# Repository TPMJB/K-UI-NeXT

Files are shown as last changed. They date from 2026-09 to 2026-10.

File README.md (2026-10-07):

# K-UI V1.8.5 "Dáinsleif"

An independent Dreamcast shell built directly on upstream KallistiOS, retaining
the original GD-ROM and using exFAT/FAT32 storage.

**Version 1.8.5 fixes the native reader placement that blocked Sonic Adventure
and Grandia II; the owner also reports Skies of Arcadia works.** Games adds
GDI/ISO/BIN-CUE/CDI/raw-image support, an Original/2048 picker, RAM-cached lists
and selected-title artwork. Disc Ripper adds BIN/CUE and verified CSO/ZSO/CHD
exports. SCI Wi-Fi integration and separate ESP32-C5/C6 firmware are included.
The splash identifies 1.8.5 and retains the Dáinsleif artwork.

Download the [1.8.5 release](https://github.com/TPMJB/K-UI-NeXT/releases/tag/v1.8.5),
then read the [installation guide](docs/release-v1.8.5.md) and
[release notes](docs/release-v1.8.5-notes.md). Install the runtime and complete
Games payload folder together. Existing exFAT cards, game dumps and compatible
independent K-UI boot CDs stay usable. DreamShell-based K-UI 1.0 requires the
supplied new CDI. No reformat, reripping or 2048 conversion is required.

Windows CE defaults to its background SCI reader and remains experimental;
audio/FMVs and title compatibility are limited. Time Stalkers and some native
FMV stalls remain unresolved. Compressed games require PC import before launch.
IDE/CF remains untested synchronous PIO; ATA DMA and CE on IDE/SCIF are future
work. ext4 is available only to the read-only bootstrap, not runtime apps or
Games.

The historical [1.7 notes](docs/release-v1.7-notes.md) and
[1.5.1 notes](docs/release-v1.5.1-notes.md) remain available.

The current SD runtime adds **raw-track GDI capture, saved-file verification and
controlled resume** to the independently booting hardware diagnostic. It stays
in RAM after you swap discs and uses FAT32/exFAT through the standard external
serial SD adapter. Keep the reusable CD and update `/KUI/runtime.kui`.

**Disc reading is done and verified. For the full state, read
[docs/HANDOFF-disc-reader.md](docs/HANDOFF-disc-reader.md) first.** A whole GD-ROM now rips in
about 20 minutes (it was over 100 with the original settings) and has been proven byte-exact
against the TOSEC catalogue on two discs: Sword of the Berserk (3 tracks) and MDK2 (31 tracks,
27 of them audio), on the console and again on a PC. MDK2 was also interrupted twice mid-disc and
resumed to a verified finish.
The capture engine also passes host-image tests. Earlier SD runtime launch and
disc/exFAT probes passed on a physical console. The user also
confirms B selects CD fallback and reports successful cold boots; the boot count
was not specified. Missing-file detection, checksum rejection and restoring the
good runtime have now passed by user report; see the
[hardware evidence](docs/hardware-evidence.md) for remaining coverage.
New K-UI shell code uses GPLv3; the Wi-Fi firmware/link library is MIT, and
dependencies retain their own licenses. There is no
separate contribution or commercial-relicensing agreement.

## The ten-app shell

The SD runtime opens ten apps, in this order on Home: **Games**, **Disc Ripper**,
**VMU Manager**, **File Manager** (new since 1.5.1), **Music Player**, **GD Play**,
**Memory Test**, **Network**, **Diagnostics** and **Settings**. New captures use a selectable
parent folder, defaulting to `/Games`, with title-based folders and GDI filenames.
The established raw acquisition engine remains in place; new format exports
have separate host validation and still need console acceptance.

Coming from DreamShell-based K-UI 1.0? Burn the supplied 1.8.5 CDI; that older
CD cannot boot this independent runtime. For an existing independent K-UI
installation, use its compatible bootstrap CD and merge the release package's `KUI` folder
onto the SD card as described in the [installation guide](docs/release-v1.8.5.md).
Update the runtime and Games payload together; optional original menu music
is included.
See [the current app acceptance round](docs/apps-round-five.md) and
[app boundaries and the later executable-loader plan](docs/app-architecture.md).
These new app paths still need physical-console acceptance.

- Select with D-pad or stick and open with A. B returns home while idle.
- The startup splash is capped at three seconds; B skips the shortened startup cue.
  Home Y cycles volume/off; L/R on Home and Ripper select songs. The header names the current song.
- GD Play exits through normal KOS shutdown to the stock BIOS. Music Player
  caches PCM16 WAV or Ogg Vorbis songs up to 6 MiB for background playback across apps.
  The developer `sd-update` includes an original one-minute WAV/Ogg sample.
  Music Player supports custom-song cycling, explicit cache clearing and a separate audio-CD player.
  Since 1.5 the menu songs ship as Ogg Vorbis and share one decoder, and Harbor
  Lights joins the rotation as a sixth song. All six cached use 1.06 MiB of RAM,
  against 4.46 MiB for the five 1.5 WAVs, which cards without the Oggs still play.
  The startup chime is embedded as Ogg too ([details](docs/music-round-five.md#bundled-menu-songs-as-ogg)).
- Ripper: A confirms a new dump, X resumes the newest matching job, Y verifies.
  Start opens Advanced, **Destination folder** and **Capture settings**.
  Output choices are GDI, BIN/CUE, CSO, DreamShell-LZO ZSO and CHDv4; compressed
  exports retain the verified raw capture for resume and verification.
  Advanced also offers explicitly confirmed Quick resume (sizes only), preserving
  full Resume and its saved-byte checks. During work, B requests Stop. Reports still save automatically. Idle insertion
  detection shows the disc title; moving capture/verification phases show percentage and ETA.
  Current retry attempts and the cumulative job total are labelled separately.
- System Settings: 640x480 TV timing with reversible preview, memory display,
  music enabled and volume, startup chime/app, local clock, TV safe area, menu sounds
  and restore-defaults. System Tools adds inventory, verified flash/visible BIOS backups and Restart.
  Capture hashes/readback remain inside the ripper. New file dates follow the RTC.
- VMU Manager: read saves, make verified SD backups, and preview/confirm restore
  into a free filename with readback. Managed copy/delete require confirmation and
  a verified restorable SD backup. No overwrite or format. Memory Test checks only its allocated RAM.
- Ripper Advanced CRC scans completed saved jobs and reports hash/Mode 1 sector
  errors separately. Already-read track sizes and CRCs are compared with the
  Redump/TOSEC catalogues, including GDI-only folders without a manifest. Only a
  full reference match establishes all-track agreement; unavailable/partial
  references retain the limited structural result.
  Separate Salvage jobs add durable bad-sector queues, optional zero filling and
  bounded repair passes; unresolved holes never receive a complete-dump claim.
- File Manager browses every folder and file on SD and opens games, music and
  pictures. Copy, move, rename and delete are checked and confirmed first;
  copies are read back and compared before they take their name, nothing is
  replaced, and the files K-UI needs to start are protected
  ([details](docs/files.md)). It has not yet been tried on a console.
- Network includes a temporary DHCP/address-conflict/gateway-ping test; it
  does not claim Internet reachability or change saved network settings. With a
  W5500 wired to the SCI port (a modification), Network also finds that adapter
  and runs an FTP server for the SD card: uploads take their name only once
  complete, and K-UI's start-up files are protected
  ([details](docs/ftp.md)). Earlier overlapping-transfer builds reached about
  0.8 MiB/s uploads and 0.5 MiB/s downloads in the tested W5500/SCIF setup;
  these are historical results, not new 1.8.5 measurements.
  A XIAO ESP32-C5/C6 with the separate K-UI firmware provides SCI Wi-Fi;
  Network Start opens scan/join and band selection. Storage remains on SCIF
  while networking owns SCI. Flash firmware by USB from a computer; console
  firmware updating is not exposed ([setup](docs/wifi.md)).
  Diagnostics retains disc/SD probes, log export,
  mstats and benchmarks. RAM remains visible in the ripper.
- Music keeps playing from RAM during menu actions and capture; uncached song
  changes wait until the storage worker is idle. Console continuity still needs checking.
- Repeated drive failures can retain PIO until reboot. The ripper now keeps that
  warning visible; the accepted DMA stop/lid policy is unchanged.

Defaults now select **CRC32, automatic end readback Off, DMA and 2 Hz busy redraws**:
these are the policy choices used by the accepted fast captures. Explicit
`bench.cfg` keys override saved preferences, and the log prints the effective
options. Resume keeps the existing job's hash mode. **Y Verify always rereads saved
files**. Only an independent **FULL TRACK MATCH** gives the stream CRC badge a
green result; partial matches and saved-file verification remain separate.

A title such as MDK2 produces `/Games/MDK2/MDK2.gdi`; another New uses
`/Games/MDK2 (2)/MDK2.gdi` without overwriting the first. Resume/Verify select the
greatest numbered matching-disc checkpoint in the chosen parent, with legacy
`/KUI/dumps` fallback. Existing jobs keep their format. See
[ripper controls](docs/ripper-controls.md) and [the capture format](docs/capture-format.md).

The reusable CD's built-in diagnostics remain available by holding B during
startup. Missing or invalid runtime packages fall back automatically. Keep using
the working CD; this UI update needs no new burn. See [SD bootstrap](docs/sd-bootstrap.md)
and [hardware evidence](docs/hardware-evidence.md) for the established boot checks.

## Build and test

On Ubuntu 24.04 / a compatible Linux or WSL installation:

```sh
sudo apt-get install build-essential git curl wget patch python3 bison flex \
  texinfo gettext libgmp-dev libmpfr-dev libmpc-dev libisl-dev \
  meson ninja-build pkg-config libisofs-dev libpng-dev libjpeg-dev \
  dosfstools exfatprogs mtools ffmpeg
python3 tools/fetch_deps.py --fatfs-only
make test test-images
bash tools/setup_kos.sh
source .deps/kos/environ.sh
make diagnostic
python3 tools/package.py
```

Packaging requires a clean committed source tree, so the source archive matches
the executable. The initial compiler build is substantial; subsequent builds
reuse it. Dependencies are pinned in [dependencies.json](dependencies.json).
The scripts use upstream KOS's stable SH-4 compiler profile: GCC 15.2.0,
Binutils 2.45.1 and Newlib 4.6.0.20260123. No DreamShell checkout is needed.

Host tests run the same portable C command, TOC, block-device and filesystem code
as the console app. Filesystem tests use disposable regular image files and
independent `mkfs`/`fsck` tools. They do not operate on physical disks.

## Milestone 1

The complete goal remains: boot independently, use FAT32/exFAT serial SD storage,
capture every supported retail GD-ROM track, and verify and resume saved dumps.

| Stage | Status |
| --- | --- |
| M1.0: source/build foundation and visible boot diagnostic | **Done.** Diagnostic runs and display fix confirmed; dozens of cold boots with no controller problems |
| M1.1: raw-disc and FAT32/exFAT capability probes | **Done.** Disc probes (Sword of the Berserk, MDK2) verified; exFAT and FAT32 both verified end to end. On FAT32 the runtime loads, the storage test passes and a whole disc rips byte-exact, about 2.4% slower than exFAT ([evidence](docs/evidence/fat32-sword-dma-2026-09-20.json)) |
| M1.2: validated runtime loading from SD | **Done.** exFAT handoff, B-selected fallback, missing-file rejection and good-runtime restoration confirmed; all five malformed fixtures rejected on hardware, each with its own reason, with a usable fallback ([evidence](docs/evidence/m12-runtime-rejection-2026-09-20.json)) |
| M1.3: full-track GDI capture | **Done.** Sword of the Berserk and MDK2 (31 tracks, 27 audio) captured and verified against TOSEC on the console and on a PC; Sword ripped three ways, identical by SHA-256 ([handoff](docs/HANDOFF-disc-reader.md)) |
| M1.4: SHA-256 capture verification and controlled stop/resume | **Done.** MDK2 stopped twice mid-disc and resumed to a finish verified on the console and against TOSEC; Sword track 3 PC-verified. The lid opened mid-capture stopped cleanly and resumed to a TOSEC-verified finish on hardware (Omikron). A scratched disc retried a fixed 10 times, named the bad sector and stopped with the partial job kept. A B stop and a lid-open in the same boot both resume on DMA ([evidence](docs/evidence/dma-stop-fix-confirmed-2026-09-20.json)). **Open:** a card that fills mid-capture, host-tested only |
| M1.5: hardware acceptance and minimal UI refinement | Launcher and non-Games app round five implemented: named dumps, salvage, VMU copy/delete/restore, Ogg/CD audio, settings/tools and network diagnostics; latest app hardware acceptance pending. Full-card failure remains host-tested only |

See [the research scope](docs/milestone-1-research.md),
[the implementation decisions](docs/diagnostic-design.md), and
[dependency provenance](THIRD_PARTY.md).

## Games

Games directly launches supported GDI, ISO, BIN/CUE, CDI v2/v3/v3.5 and
standalone BIN/IMG layouts. The supplied PC importer expands CSO/ZSO and
extracts CHD; resident compressed boot decoding is not implemented. See
[format and import limits](docs/games-formats.md).

Matching `Game` and `Game-2048` folders collapse into one Games entry. Choose
**Original** or **2048-byte copy** after selecting it. The
[batch converter](docs/gdi-2048-test.md) creates separate copies, preserves
originals and reports each conversion, skip or failure. Conversion does not
guarantee compatibility or replace an archival raw dump.

Recent lists remain in RAM. Rows appear before artwork, and only the selected
game's cover loads. The owner reports the first Games entry takes about
5–7 seconds on the tested collection and navigation afterward is fluid.
**X Refresh** rebuilds the cache after library/card changes. See
[covers and views](docs/games-covers.md).

Native confirmation uses **A** standard, **X** background SCI/20 and **Y**
background SCI/25. Windows CE uses **A** for its background SCI reader; its
broken regular reader is no longer offered. The native reader now stays below
the IP image, clearing startup-stack collisions without changing game code.
The owner confirms Sonic Adventure, Grandia II and Skies of Arcadia working
on the tested layout. Power Stone 1/2 worked after earlier GD command fixes.
These are scoped console results, not full playthroughs or an all-games claim.

Time Stalkers still returns to K-UI, and some titles stall/skip FMVs in both
Original and 2048 mode. CDDA, Mode 2 Form 2 and subchannel emulation remain
unsupported. See the [current release notes](docs/release-v1.8.5-notes.md),
[native placement evidence](docs/evidence/native-low-resident-2026-10-06.md),
and [historical gameplay development](docs/games-retail-test.md).

## License and contribution policy

New K-UI shell code is **GPL-3.0-only**, unless a file states otherwise.
The separate Wi-Fi firmware and shared kwlink library are **MIT**; source
headers and [THIRD_PARTY.md](THIRD_PARTY.md) identify the applicable licenses. Contributions
use the applicable existing file license. Contributors retain their copyrights;
there is no separate CLA or grant of proprietary relicensing rights.

This is a fresh repository, not a DreamShell fork. Requirements and hardware
observations can inform new implementations. Do not import upstream-derived DreamShell source or binaries by changing their names.
Independently authored additions from our earlier fork can be reused after checking
their origins, dependencies and intended license; see [the reuse inventory](docs/prior-work-reuse.md).
Original project artwork and the five original synthesized music loops are reused with recorded provenance; inherited assets keep their own terms.
Independently licensed upstream KOS contributions remain attributed and usable,
including contributions by people who also work on other projects.

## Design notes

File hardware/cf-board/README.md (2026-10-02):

# CF board: CompactFlash inside the Dreamcast

**Rev 1, designed 2026-09-29. Not yet made or tried.** A small board that
puts a CompactFlash card on the GD-ROM drive's bus (the G1 ATA bus) as its
second device, inside the console. The GD-ROM drive stays the first
(master) device and keeps working. The card is the slave, as KallistiOS's
`g1ata` driver expects: "The GD-ROM drive should always be the master
device on the chain, but you can hook up a hard drive or some other device
as a slave" (`dc/g1ata.h`).

The [standalone storage development build](../../docs/storage-transports.md)
adds a G1 ATA slave path, including the independent Games reader. Both this
board and the new IDE/CF driver still need hardware validation. See
[the handoff](../../docs/HANDOFF.md) for the current software state. Fitting
the board alone should not change the console's ordinary boot behavior.

| Top (card side) | Underside |
| --- | --- |
| Top | Underside, seen from below |

- [Schematic (PDF)](docs/cf-board-schematic.pdf)
- [Fit template, print at 100 % (PDF)](docs/cf-board-fit-template.pdf)
- [Gerbers for the board house](fab/cf-board-gerbers.zip),
  [parts list](fab/cf-board-bom.csv),
  [part positions](fab/cf-board-positions.csv)

## What the photos of the VA1 board show

From the owner's photos of both sides, with a ruler, sent on 2026-09-28:

- **CN503, the drive connector, is surface-mounted:** two rows of 25 legs at
  1.0 mm spacing. The A legs (A1 to A25, as printed on the board) run along
  the side facing the middle of the board. The B legs run along the side
  facing the board edge. Nothing comes through to the underside, so the
  wires are soldered to these legs.
- **The underside, under CN503,** has a grid of round test pads and the
  33 ohm resistor arrays in the drive's lines (RA507 to RA515 and others).
  The test pads would be easier to solder to than the legs, but nothing
  printed says which signal each carries (see
  [Using the test pads](#using-the-test-pads-instead)).
- **SCI connector points:** R115, R140 (beside IC105) and CE113 are on the
  underside. R122 and RA101 are not yet found in the photos. These matter
  for the [SCI connector plan](../../docs/sci-connector.md), not this board.

## How it connects

Each pad on the board takes one wire from the CN503 leg of the same name:
pad A4 to leg A4, pad B11 to leg B11. The pads are labelled A1 to A21 and
B1 to B21 on top, and with their signals on the underside. The CN503 signal
names follow the [iceGDROM](https://github.com/zeldin/iceGDROM) riser
board, which plugs into the same connector.

| Leg / pad | Signal | CF pin | Leg / pad | Signal | CF pin |
| --- | --- | --- | --- | --- | --- |
| A1 | +3V3 | JP1 (card supply) | B1 | +3V3 | JP1 (card supply) |
| A2 | /RESET | 41 (/RESET) | B2 | (unused) | leave unwired |
| A3 | +5V | JP1 (card supply) | B3 | +5V | JP1 (card supply) |
| A4 | D7 | 6 (D7) | B4 | D6 | 5 (D6) |
| A5 | D8 | 47 (D8) | B5 | D9 | 48 (D9) |
| A6 | D5 | 4 (D5) | B6 | D4 | 3 (D4) |
| A7 | D10 | 49 (D10) | B7 | D11 | 27 (D11) |
| A8 | GND | ground | B8 | GND | ground |
| A9 | D3 | 2 (D3) | B9 | D2 | 23 (D2) |
| A10 | D12 | 28 (D12) | B10 | D13 | 29 (D13) |
| A11 | D1 | 22 (D1) | B11 | D0 | 21 (D0) |
| A12 | D14 | 30 (D14) | B12 | D15 | 31 (D15) |
| A13 | GND | ground | B13 | GND | ground |
| A14 | DMARQ | 43 (DMARQ) | B14 | /DIOW | 35 (/IOWR) |
| A15 | /DIOR | 34 (/IORD) | B15 | IORDY | 42 (IORDY) |
| A16 | /DMACK | 44 (/DMACK) | B16 | INTRQ | 37 (INTRQ) |
| A17 | (unused) | leave unwired | B17 | DA1 | 19 (A1) |
| A18 | GND | ground | B18 | GND | ground |
| A19 | DA0 | 20 (A0) | B19 | DA2 | 18 (A2) |
| A20 | /CS0 | 7 (/CS0) | B20 | /CS1 | 32 (/CS1) |
| A21 | GND | ground | B21 | GND | ground |

**Never wire A22 to A25 or B22 to B25.** They carry CD audio, ground and,
on A25 and B25, **+12 V**, which would destroy the card. A3 and B3 (+5 V)
are needed only if the card is ever switched to 5 V (JP1, below).

That is 28 signal wires, 2 for 3.3 V and 8 for ground. Wire every ground:
the grounds are the return path for the 16 data lines.

## Wiring it

1. **Check the connector's orientation first, with the console unplugged.**
   Put a multimeter on continuity. Legs A21 and B21 must beep to ground
   (the metal shield, or the shell of the AV connector). Leg A5 must not.
   Leg A1 must beep to leg B1 (both are 3.3 V). If the connector were turned
   end to end, A21 would be a data line and would not beep. If anything
   disagrees, stop and send a photo: the numbering differs from what this
   board expects.
2. Use thin insulated wire, such as 30 AWG wire-wrap wire, about 10 to 15 cm
   long and no longer than the chosen spot needs.
3. Tin each leg lightly, lay the wire on it, and touch it with a fine tip
   and flux. Keep solder off the connector's plastic and out of its
   opening. Lay the wires flat along the board so the GD-ROM drive still
   seats fully in CN503.
4. Solder the other end of each wire to the pad of the same name.
5. Before powering: check continuity from each leg to its pad; check that
   no two neighbouring legs are bridged, in both rows; and check there is
   no short between C1's two ends (the card supply and ground).

## Before and at first power-up

- **JP1** (underside) comes bridged between 1 and 2: the card runs from
  3.3 V. To run it from 5 V instead, cut the thin trace between pads 1 and 2
  and bridge 2 and 3. Stay on 3.3 V unless a measurement says otherwise
  (see the design notes).
- **JP2** (underside) stays open: the card is the slave. Bridging it makes
  the card the master, for trying the board on a PC's IDE port only.
- Fit a CompactFlash card. Any size will do; True IDE mode is part of every
  CF card.
- Power up with the drive connected. The console must start and read discs
  exactly as before. The ACT LED (underside) lights briefly at start-up as
  the card announces itself, and later while the card is busy.

## Making it

- **Board:** 2 layers, 1.6 mm, 66.5 x 54 mm, any colour. Upload
  [cf-board-gerbers.zip](fab/cf-board-gerbers.zip). It fits the standard
  service of the usual board houses: 0.25 mm tracks, 0.2 mm spacing,
  0.3 mm drills. Choose **ENIG** (gold) plating if offered: its flat pads
  make the socket's 0.635 mm pins easier to solder by hand.
- **Parts:** [cf-board-bom.csv](fab/cf-board-bom.csv). The socket is a 3M
  N7E50-E516PG-30 CompactFlash header. The rest are 0805 resistors,
  capacitors and an LED.
- **Order of soldering:** the CF socket first (flux, tack two corner pins,
  drag-solder the rest, then check every gap with a magnifier), then the
  underside parts. The wire pads get their wires last, at the console.

## Where it goes

The board with a card fitted is about 7 mm thick in all, and the card
slides in from the right-hand edge. Print the
[fit template](docs/cf-board-fit-template.pdf) at 100 %, check that its bar
measures 50 mm, cut out the outline, and try it inside the console with
the drive and the power supply fitted. Double-sided foam tape holds it; the
two M2 holes also take nylon screws, and tracks stay 2.4 mm clear of them.
If no spot fits, the outline can change: the whole design is regenerated
from [tools/design.py](tools/design.py).

## Using the test pads instead

The round pads on the underside under CN503 are probably test points for
the same signals, which would make easier solder points. That is not
confirmed. To use them: with the board out and unplugged, beep from each
CN503 leg (top side) to the test pads (underside), write down the pad for
each signal in a copy of the table above, and send the list for checking
before soldering. Any signal without a test pad is wired at its leg.

## Design notes

- **3.3 V card supply.** The iceGDROM emulator drives these lines straight
  from a 3.3 V chip, so the Dreamcast's side works at 3.3 V. The GD-ROM
  drive's own output level is not documented. If it drove 5 V onto the bus,
  a card running at 3.3 V would be stressed. JP1 allows 5 V operation, as
  the iceGDROM riser's slave connector does. The level can be settled by
  measuring a data line while the drive reads a disc, before a card goes in.
- **The row names agree.** On the iceGDROM riser, the A row and the A25
  end face the riser's body, which lies over the middle of the mainboard,
  where the drive sits. That matches VA1's silkscreen, with A1 to A25 along
  the side of CN503 facing the middle of the board. The orientation check
  in the wiring steps catches a connector turned end to end.
- **No series resistors** on the board. The Dreamcast already has 33 ohm
  resistors in these lines. With short wires and a single card, the board
  stays simple, like the usual IDE modification.
- **No master/slave handshake with the drive.** The drive connector carries
  neither DASP nor PDIAG. The card's DASP line drives the ACT LED, and
  PDIAG has its own pull-up.
- **True IDE mode:** ATA SEL (pin 9) and A3 to A10 are grounded, and WE
  (pin 36) is held high. CSEL (pin 39) is left open, so the card is the
  slave. The CF pin assignments were checked against published True IDE
  tables.
- **The socket's footprint** is KiCad's `CF-Card_3M_N7E50-E516xx-30`, with
  the copper rings of its two unconnected board-lock holes cut from 3.99 to
  3.2 mm, so that they clear the locating holes by 0.55 mm instead of
  0.155 mm (`cf-board.pretty`).

## Files and checks

- `cf-board.kicad_pro`, `.kicad_sch`, `.kicad_pcb`: the KiCad 7 project.
  `cf-board.kicad_sym` holds the socket's symbol, and `cf-board.pretty` its
  footprint.
- `tools/design.py`: the connector pinouts, the parts and every
  connection, in one place. `tools/build.sh` rebuilds everything from it:
  schematic, netlist check, placement, autorouting with Freerouting 1.9,
  ground pours and stitching, DRC, and the files in `fab/` and `docs/`.
- `tools/check_netlist.py` compares KiCad's netlist, from the schematic and
  again from the finished board, with `design.py`. It stands in for ERC,
  which KiCad 7's command line lacks. `tools/drc.py` runs KiCad's DRC.

For rev 1, both netlist checks found 36 nets, 102 connections and no
problems. The DRC found no violations and no unconnected pads, and every
footprint matches its library.

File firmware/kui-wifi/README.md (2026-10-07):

# K-UI Wi-Fi firmware

Firmware for a **Seeed XIAO ESP32-C5** (dual-band Wi-Fi 6) wired to the
Dreamcast's SCI port. It gives K-UI a network connection the way the W5500
does, over Wi-Fi instead of a cable. It also builds for the XIAO ESP32-C6
(2.4 GHz only).

**Status: implemented and host-tested; hardware characterization remains
incomplete.** Earlier owner reports include Wi-Fi connection and FTP use,
without establishing performance for the merged 1.8.5 source. K-UI provides
a driver, FTP integration and a Wi-Fi page for choosing a network (see
[Wi-Fi](../../docs/wifi.md)). Set up and test the board from a computer
before installation.

## What it does

- Joins your Wi-Fi network (WPA2/WPA3, 2.4 or 5 GHz), remembers it, and
  rejoins by itself after a power cut or a dropped connection.
- Runs the TCP/IP stack itself. The Dreamcast opens up to eight numbered
  sockets on it, much as it does on the W5500, so the FTP server can run
  over either.
- Also offers the Dreamcast a network list, joining, name lookups, and the
  time of day (set from the internet). Firmware-update messages exist in
  the link protocol; K-UI does not yet expose a firmware-update workflow.
- A USB console for setting it up and checking it from a computer.

The link to the Dreamcast is described in [PROTOCOL.md](PROTOCOL.md); the
wiring is in [the SCI connector plan](../../docs/sci-connector.md).

## Loading it the first time

For Arch Linux, follow the [C5 flashing and bench-test guide](../../docs/wifi-flash-arch.md).

You need the board, a USB-C data cable and a current `esptool` with ESP32-C5
support. On Arch use its packages as described in the guide above; other
systems can use [Espressif's installation instructions](https://docs.espressif.com/projects/esptool/en/latest/esp32c5/installation.html).
Keep the board disconnected from the Dreamcast during this first USB test.
If already installed, disconnect its Dreamcast power and signal connections
before attaching powered USB: the XIAO's 5V pin is also USB VBUS.

1. Download the `kui-wifi-esp32c5` artifact from the latest successful
   **Wi-Fi firmware** run in the repository's Actions tab, and unzip it.
2. Plug the board into the computer. On Linux it appears as `/dev/ttyACM0`.
3. Write the whole image:

   ```
   esptool --chip esp32c5 --port /dev/ttyACM0 write-flash 0x0 kui-wifi-esp32c5.bin
   ```

   If esptool cannot connect, hold the board's **B** (boot) button while
   plugging it in, release it, then try again.

`kui-wifi-esp32c5-update.bin` in the same download is the app on its own,
for the firmware-update protocol, not initial USB flashing. K-UI's update
workflow remains to be implemented. `SHA256SUMS` lists checksums. The
protocol's rollback mechanism keeps an update only once the new firmware
has started and the Dreamcast has reached it over the link; otherwise the
board goes back to the firmware it had (see [PROTOCOL.md](PROTOCOL.md)).

## Testing it on the bench

Attach the included antenna to the board's U.FL connector while unpowered.
Start with a 2.4 GHz network. If a 5 GHz
network cannot be reached, check its channel and test with a known dual-band antenna.

Open the board's console, for example with
`python -m serial.tools.miniterm --raw --eol CR /dev/ttyACM0 115200`, and
press Enter for the `kui-wifi>` prompt.

```
band 2.4                        start with 2.4 GHz only
scan                            networks in range, with band and signal
join "My network" password      join and save (quote names with spaces)
status                          state, band, channel, signal, addresses, clock
band auto                       both bands; `band 5` for a separate 5 GHz test
forget                          disconnect and forget the saved network
reboot                          restart the board
```

`status` should show **online**, a channel and an address. From the computer,
`ping` that address. After a `reboot` it should come back online by itself;
reopen the terminal if USB disconnects. This tests the board's Wi-Fi, not
its SCI connection to the Dreamcast. Exit miniterm with **Ctrl+]** and unplug
USB before connecting the Dreamcast wiring and its 5V supply. For later USB
access to an installed board, disconnect those Dreamcast connections first.

## Building

With [ESP-IDF v5.5.5](https://docs.espressif.com/projects/esp-idf/):

```
cd firmware/kui-wifi
idf.py set-target esp32c5
idf.py build
idf.py merge-bin -o kui-wifi-esp32c5.bin    # in build/
```

The link and bridge code also builds on a normal computer. `make -C
firmware/kui-wifi/test` runs the tests: exactly-once, in-order delivery
through bit errors and cut-short transfers; and a simulated Dreamcast
driving real TCP and UDP sockets on localhost, with listening, connecting,
closes both ways, bands, echoes, a board reset and a firmware update. K-UI's
own tests also run this bridge core, behind K-UI's real driver and FTP
server (`tests/wifi_model.c` at the top of the repository).

## Licence

MIT (see [LICENSE](LICENSE)), unlike the rest of K-UI (GPL-3.0). The
firmware is linked with Espressif's closed-source Wi-Fi libraries, which GPL
code cannot be combined with. The link protocol code in
`components/kwlink` is shared with K-UI, which can include MIT code. No
DreamShell code is used.

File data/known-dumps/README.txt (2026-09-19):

Bundled known-dump database
===========================

redump.db contains game names, track numbers, sizes, and CRC32 values derived
from the Libretro Database file:

  metadat/redump/Sega - Dreamcast.dat, version 2026.08.01
  https://github.com/libretro/libretro-database/blob/master/metadat/redump/Sega%20-%20Dreamcast.dat

The source database is licensed under Creative Commons
Attribution-ShareAlike 4.0 International (CC BY-SA 4.0):

  https://creativecommons.org/licenses/by-sa/4.0/

This compact adaptation is distributed under the same license. It was produced
with host-tools/make_gd_redump_db.py and contains no game or disc payload data.

The bundled Libretro catalog normally lists one identifying data track per
game. Therefore GD Ripper reports IDENTIFIED BY DATA TRACK for a match. To use
a full Redump DAT with all tracks, run the included converter and replace this
redump.db file.

TOSEC GDI catalog
=================

tosec.db contains a compact factual index of retail GDI game names, track
numbers, lengths and CRC32 values from TOSEC's official 2025-03-13 DAT pack:
https://www.tosecdev.org/downloads/category/59-2025-03-13

Source DAT author: Maddog / TOSEC-ISO contributors. Regional source DATs:

TOSEC-ISO/Sega Dreamcast - Games - JP (TOSEC-v2025-02-16_CM).dat
SHA256 b3937cf6ef0fd13d97ef701202b8d06631c15f0de162a7364442e6f567157d88

TOSEC-ISO/Sega Dreamcast - Games - PAL (TOSEC-v2023-04-02_CM).dat
SHA256 4fb1cee56dfe84ae12003fd081a1b2758254ba16ce219bb0ccbfcdcd85323e9d

TOSEC-ISO/Sega Dreamcast - Games - US (TOSEC-v2025-02-09_CM).dat
SHA256 fdf463cee179196d1b089ee16bf8785511f0189f85e75e7d10c068860245f019

Generated using make_gd_redump_db.py: 1,245 game entries / 9,545 track entries.
Only names and checksum metadata are included; no games or disc payloads.
The Libretro CC BY-SA notice above applies to redump.db, not to TOSEC's work.
For updated metadata and corrections, visit https://www.tosecdev.org/.

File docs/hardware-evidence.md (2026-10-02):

# Hardware evidence

## SCI period correction: batching active and FMVs improved — 2026-10-01

**Console result — ce7006087f20:** the owner reports **18 seconds** from
Kasumi selection to the first fight (previously 25), **FMVs playing fine**,
and remaining slowdown during the first **seven seconds** of combat.
The return photo confirms batching: 5,355/6,762 reading steps enlarged
(79.19%), 21,872 sectors (3.23455 per step), zero spin steps and guard fault.
Latest period/vblank is **525/260**, the geometry mishandled by the old code.
Keep this as the current DOA2 comparison build. See the
[console evidence and limits](evidence/sci-pacing-period-console-2026-10-01.md).

## SCI batching: reported improvement, zero enlarged steps — 2026-10-01

The owner reports **about 25 seconds from selecting Kasumi to match start**
on **8d930310f79d**, versus the earlier 29 seconds, and noticeably smoother
combat with only slight slowdown in the first roughly ten seconds. The old
severe slowdown also resolved after about ten seconds; severity improved,
not duration. Audio remains pretty smooth. These are initial timing and
qualitative observations, with no explicit FMV acceptance.

The matching return photograph now shows **zero paced and spin steps**,
5,970 read steps, 11,880 game sectors (1.989950 per step) and no guard fault.
The owner passed through DOA2's title screen and retried the combination
several times; normal soft resets do not clear these session counters.
Larger batches did not activate, so the reported improvement cannot be
attributed to more sectors per call. Its cause remains unestablished.

Storage Soak run **13** passes 160 MiB/ten cycles in 303.722145 seconds,
with zero errors/DMA faults and successful remount verification/cleanup.
Write/read **1,197.40/1,064.98 KiB/s** is effectively unchanged versus run 10.
See the [reports, photo transcription and scope](evidence/sci-game-pacing-result-2026-10-01.md).
The subsequent [period correction](evidence/sci-pacing-period-fix-2026-10-01.md)
uses actual `SPG_LOAD` geometry and adds timing diagnostics. Its positive
console result is recorded above; this older photograph did not identify
the precise condition that prevented larger batches.

## SCI grouped CRC passed; game counter capture obtained — 2026-10-01

Build **6cc2abb460b5** passed Quick run **9** (4 MiB) and Soak run **10**
(160 MiB, ten cycles), with zero errors/DMA faults and successful remount
verification and cleanup. Soak write/read rates are **1,198.32/1,064.87 KiB/s**,
respectively +0.14%/+1.52% versus run 8. RX checking fell from 78.18 to
68.48 microseconds per sector, a 12.4% reduction; Quick independently reports
68.57 microseconds. Overall read gains remain modest and run variation applies.

The matching game counter photograph shows no guard fault, zero enlarged
or spin-triggered steps and approximately two sectors per successful read step.
It does not identify physical SCI DMA use or isolate the previously reported
29-second character-to-fight load. See the
[raw reports, photo transcription and limits](evidence/sci-grouped-crc-and-game-pacing-2026-10-01.md).
The resulting half-frame/max-four candidate was subsequently tested as
8d930310f79d; its separate report above shows no enlarged steps. These grouped
CRC results belong to its parent and do not validate batching activation.

## SCI word-reversal build soak passed; write setup improved — 2026-10-01

Runtime **499bcb53c2d4**, run **8**, passed the same five-minute Soak recipe
as run 7: 10 cycles/160 MiB verified in 306.434992 seconds, zero errors/DMA
faults and successful cleanup. Write/read rates were **1,196.64/1,048.89 KiB/s**,
respectively 5.65%/0.44% above run 7. TX setup fell from 35.96 to
20.21 microseconds per sector. RX reversal/CRC did not improve: 78.18 versus
77.18 microseconds, with transfer still near 331 microseconds. The small
read-rate change does not establish a repeatable read gain.

The owner timed the current DOA2 test at **29 seconds from selecting Kasumi
to the first fight**. The brief return-counter display could not be captured;
no game DMA, batch-size or standby-state values are available. A retry was
deferred until the display is easier to capture. See the
[original soak reports and separate game observation](evidence/sci-dma-word-soak-2026-10-01.md).
The runtime pass does not prove a game speed change or the module-wake hypothesis.

## SCI DMA Quick and five-minute profile soak passed — 2026-10-01

Runtime **65fcaafadb98** passed run **6**, a 4 MiB Quick check, and run **7**,
a five-minute Soak completing 10 cycles/160 MiB in 315.049953 seconds. Both
verified after remount with zero errors/DMA faults and successful cleanup.
Write/read rates were **1,097.42/1,037.03 KiB/s** for Quick and
**1,132.60/1,044.27 KiB/s** for Soak. Quick is slightly slower than a6cb218's
single Quick run (0.63%/1.49%); instrumentation and run variation prevent a
regression conclusion. Soak is 12.74%/12.76% above cf8e7ea, but five versus
fifteen minutes and two intervening changes prevent a controlled comparison.

Soak averages **331.02 microseconds for RX transfer** and **77.18 microseconds
for reversal/CRC** per DMA sector. A further 68.88 microseconds per sector of
timed file reads lies outside measured RX phases; it is not solely card time.
See the [original reports, exact comparisons and phase analysis](evidence/sci-dma-profile-2026-10-01.md).
This is runtime evidence; no new retail-game timing accompanies the reports.

## SCI cached processing Quick passed — 2026-10-01

Runtime **a6cb21895c37**, run **5**, passed a **4 MiB Quick** check with zero
errors/DMA faults. Write/read rates were **1,104.35/1,052.72 KiB/s**, respectively
9.93%/13.67% above the first DMA soak. This is preliminary run-to-run evidence:
Quick is much shorter than Soak and does not establish a sustained gain.
DMA reads exactly match the 8,192 verified sectors. See the
[original reports and review](evidence/sci-dma-cached-quick-2026-10-01.md).

## SCI DMA soak passed; DOA2 substantially improved — 2026-10-01

Runtime **cf8e7ea7866b**, run **4**, passed 26 cycles and 416 MiB written and
verified after remount, with zero errors or DMA faults. Write/read throughput
was **1,004.62/926.11 KiB/s**: 92.55%/75.15% faster than the first SCI run.
Reads are 51.25% faster than SCIF; writes remain 6.97% lower. Recorded DMA
reads exactly match the verified payload's sector count. See the
[original reports, conditions and comparison](evidence/sci-dma-soak-2026-10-01.md).

The owner reports DOA2 is now "much better", with a tiny amount of lag remaining
in some areas. This is qualitative title-specific evidence; it does not prove
the cause of that lag or accept other games, VMU and FMV behavior. The next
original optimization combines receive processing and overlaps transmit CRC
work while retaining integrity checks and the existing game pacing.

## Initial SCI DOA2 play check — 2026-10-01

After the passing SCI soak below, the owner tried Dead or Alive 2 and reported
that it was "largely the same" as SCIF. This is an initial qualitative play
observation, with no measured load-time improvement or separate acceptance of
FMV, return-to-menu and VMU operations. It does not establish the exact retail
payload build from a report. The owner requested an original SCI performance
fix, including DMA investigation, before broader testing. Reference projects
may inform the design; their implementation is not to be copied.

## SCI storage soak passed; slower than SCIF — 2026-10-01

The owner's SCI microSD run **2**, runtime **3a368ddcfaff**, passed the same
15-minute exFAT/128 KiB-cluster recipe as the SCIF baseline. It completed in
**15 min 56 s**, verifying **240 MiB across 15 cycles**, with zero reported
transport/FatFs errors and successful cleanup. Write/read throughput was
**521.75 / 528.75 KiB/s**, **51.69% / 13.65% lower** than SCIF. The report
establishes runtime integrity for this run, not a performance improvement.

See the [SCI baseline and original reports](evidence/sci-soak-baseline-2026-10-01.md)
for the complete comparison and latency interpretation. Runtime storage is
ready for Games compatibility checks; the initial DOA2 observation above does
not complete that coverage. Use the same image and a matching SCI-capable
`/KUI/apps/games/retail-boot.kui`. IDE/CF remains hardware pending.

## SCIF storage soak baseline passed — 2026-10-01

The owner designates run **1** from runtime **3a368ddcfaff** as the SCIF baseline
for SCI comparison. The 15-minute exFAT soak finished in **15 min 7 s**:
**21 cycles**, **336 MiB written and verified**, zero reported transport/FatFs
errors and successful cleanup. Across 64 KiB requests, aggregate write/read
rates were **1,079.94 / 612.32 KiB/s**; maximum call durations were
**141.026 / 173.527 ms**. Music was off and UI refresh was 2 Hz.

See the [baseline record and original reports](evidence/scif-soak-baseline-2026-10-01.md)
for exact settings and latency interpretation. The SCI comparison above uses
matching reported settings. No repeat of this accepted SCIF run is requested.

## Selected-image GD request test: hardware pending — 2026-09-24

The next Games increment implements selected-GDI allocation mapping and a
bounded request service through the actual GD BIOS vector. Its own standalone
client compares post-shutdown physical SD reads with small pre-handoff CRC
references. **No console result for this increment has been supplied.** Follow
[the selected-image guide](games-image-probe.md) using the existing Dead or Alive
2 dump; no full rip, full verification or reader benchmark is requested.

This does not start the retail executable, provide hardware SD DMA or establish
throughput. The accepted original-fixture result below remains valid within its
recorded scope; it is not evidence for the new selected-image/vector path.

## Games resident handoff: original fixture passed — 2026-09-24

The owner's console photograph identifies build **7a8493ae825e**, shows all
ten probe checks passing and reports **84 post-handoff SD blocks read**. The
separately linked client checked actual SD bytes after KOS shutdown and erasure
of retired launcher RAM. This accepts the G3 resident storage/handoff foundation
for the original fixture and K-UI probe ABI v1. See [the evidence](evidence/games-resident-probe-hardware-2026-09-24.json)
and [photograph transcription](evidence/games-resident-probe-hardware-2026-09-24.txt).

The photograph does not identify the filesystem, establish throughput or retail
GD BIOS compatibility, or demonstrate CDDA playback. Selected-game track mapping
and the bounded vector request path are now implemented but pending their own
hardware check as noted above. Retail boot remains subsequent work, with Dead or
Alive 2 the first intended target. No repeat of this original probe, ARMADA
inspection, full rip or reader benchmark is requested.

## Games image inspection: ARMADA — 2026-09-24

Runtime **57d53841c1ea** successfully inspected the saved ARMADA GDI three times
on exFAT. Each reports five tracks (three data, two audio), 1,187,764,704 stored
bytes, and `0WINCEOS.BIN` at LBA 548388 with length 1,253,376 bytes. Each inspection
read 7,199 metadata bytes. Bust-A-Move 4 was stopped after 3,143 bytes; subsequent
ARMADA inspections succeeded. It is a cancelled attempt, not a parsing failure.
An earlier `CMD 19 FAILED` belongs to inserted-disc identification before Games.

This accepts the demonstrated image-inspection path, not executable loading,
retail compatibility, full verification or performance. The log does not identify
every browser navigation action. See [the evidence](evidence/games-armada-inspection-2026-09-24.json)
and [console excerpt](evidence/games-armada-inspection-2026-09-24.txt).
The subsequent resident read proof passed as recorded above; no repeat ARMADA
inspection or rip is requested.

## Audio-CD follow-up accepted by owner — 2026-09-24

The owner confirms **audio CD worked** and wants to proceed to Games. Record
playback as passed by owner report; no repeat playback test is requested.
The message supplies no new log, build ID, album or individual control results,
so it does not establish every mixed-CD/transport path. The offered update was
packaged runtime `9c282c90c2f8`; that context does not identify the tested binary.
See [the confirmation record](evidence/m15-audio-cd-owner-confirmation-2026-09-24.json).
The older logged status observations below are retained as history.

## Current app acceptance: scans, music cache and VMU — 2026-09-24

Runtime **cc2320bb6d3a** has now passed all three tiny Advanced CRC fixture
expectations: clean hashes/Mode 1 checks pass; the damaged fixture reports two
suspect data sectors and three CRC mismatches; the GDI-only fixture explicitly
reports structural checks only. The existing **ARMADA** folder also scanned to
completion. Its five saved-track CRC32s were recorded, and Mode 1 structure
passed, but no K-UI manifest was present, so this runtime had no expected hashes
to compare. The amber result is not a failed scan or a full reference match.
The separately supplied completed report records **1,187,764,704 bytes**, with
**220,386 data sectors**, **284,616 audio sectors**, and zero bad/unsupported
sectors. A subsequent read-only comparison found **all five recorded CRC32s,
including both audio tracks, match TOSEC's Armada v1.000 US entry**. Total bytes
and data/audio sector totals match too. That comparison was performed from the
console report, not by independently reading the uploaded track files, and was
not part of the runtime's amber result. The report omits individual track sizes
and elapsed time. It does not require another whole-game PC read to compare the
already-recorded CRCs.

**Clear cache released all nine music file allocations**: nine allocations,
nine frees, zero cached/loading bytes and mask zero. Eight subsequent memory
snapshots retained **189,876 bytes of heap in use** and the same main-RAM
used/reserved estimate of **4,447,688 bytes**. Retained free allocator pages are
not live song allocations. This confirms cache clearing in this session; the
report does not identify selected filenames or prove every playback path
leak-free or glitch-free.

**VMU backup → delete → restore passed by owner report using THPS2**: the game
acted as if no save existed after deletion and loaded it again after restore.
The log contains no detailed VMU operation audit, so this is game-tested owner
acceptance of one save, not independently checked metadata or two-VMU Copy.

The owner heard the second audio CD play. The log records a 13-track audio-only
TOC and Play success on tracks 1–3, but tracks 1 and 2 are followed by
`Drive not ready` reports; CD status/control acceptance remains incomplete.
The earlier refused disc has 16 audio tracks plus a data track, consistent with
this build's mixed-disc refusal. The log does not identify its album or prove a
physical fault.

**Network testing is deferred until suitable hardware is available. Salvage
(item 8) is deferred by the owner to a future version.** Neither is marked
passed. Settings/tools were not established by this submission. The
[sanitized evidence](evidence/m15-app-round-five-2026-09-24.json) records the
upload's fingerprint, exact source-line ranges and these limits. The upload
contains 570 physical lines and says `Log truncated: no`; the requested larger
log buffer is a usability improvement, not a repair for truncation in this file.
Use the remaining checks in [the app guide](apps-round-five.md); no accepted
reader test needs repeating.

## Earlier app evidence: Dead or Alive 2, cache and Advanced CRC — 2026-09-23

Runtime **6f1be4cf53c3** completed Dead or Alive 2 after one failed capture and
a stopped Quick Resume. The final Quick Resume ended with **TOSEC FULL TRACK
MATCH across all three tracks** and used **5,286 DMA chunks and two PIO chunks**.
The two size-only resume checks took **0.419433 s** and **0.397359 s**. These are
observations from the owner's ordinary recovery session, not new reader tests.
Saved bytes were not reread, and no track files were supplied for a PC check.

Retries were working: the first capture made one retry at FAD 380094 and all
**10/10 retries at FAD 380111**, then stopped with **11 cumulative retries**.
The stopped resume added two more, making 13. The reported screen value of 1
was a presentation issue; it is not evidence that the engine made only one
attempt. The logs identify the inserted title before/after work, but do not
record the exact title drawn while capturing.

The damaged Advanced CRC fixture passed its acceptance criterion: **two suspect
data sectors** (FAD 150: P/Q, FAD 45152: EDC/PQ) and **three CRC mismatches**, with
10 data and four audio sectors read. The clean fixture is not present in this
submission. Two existing-folder attempts failed before scanning. Their old
error omitted the selected folder, filename and FatFs code, so these logs do
not establish which metadata was missing or whether the selected folder was
its parent. The next app update adds specific errors and imported-GDI support.

Music counters remain at **6,473,566 cached bytes**, zero loading bytes,
**12 allocations / seven frees**, and cached mask **0x3d** across the scan and
capture/resume reports. That mask includes the retained custom song. Peak file
allocation was **8,061,166 bytes**, below the **8,388,608-byte** cache budget.
Main-RAM use/reservation stayed at **10,745,736 bytes** after caching, with a
sampled peak of **12,333,336 bytes**. These snapshots support bounded retained
cache rather than continuing growth in this run; they do not prove every music
path leak-free. The owner reports the custom song played but was omitted by
trigger cycling; source inspection confirms the old five-bundled-song cycle.

Five diagnostic files are overlapping snapshots of **one session**, two of them
truncated. Their filename timestamps do not establish operation order.
[Sanitized source fingerprints and exact observations](evidence/m15-doa2-app-round-four-2026-09-23.json)
record the scope and limits. The RTC log uses September 23; actual file-date
artifacts and VMU write acceptance were not supplied. Follow
[the next app acceptance guide](apps-round-five.md) on the existing boot disc.
The remaining sections below retain historical runtime-specific findings;
statements about what was then pending should not supersede this entry.

## Omikron DMA stop/resume and music — 2026-09-23

Runtime **69dc33c0ff87** completed all five Omikron tracks after two stops and
Quick Resumes, ending in **TOSEC FULL TRACK MATCH**. The final resumed segment
used **1,796 DMA chunks and one PIO chunk**. Its two size-only prefix checks took
**0.483950 s** and **0.414696 s**. The three capture phases together averaged
**940.79 KiB/s**, excluding setup, pauses, resume checks and final publication.
Saved files and older prefixes were **not reread**. The rip log is truncated;
stopped phases do not contain their own DMA/PIO summary. Their PIO subtimers
must not be mistaken for evidence that all their reads used PIO.

All ten RAM snapshots in the rip report stayed at **9,671,936 bytes (9.224 MiB)**.
A separate, untruncated music report went from **4,162,232** to **11,548,184 bytes
(11.013 MiB)** after background-song selection. These reports are not proven to
be one continuous boot, so they do not establish RAM falling from 11 to 9 MiB.
The older runtime lacks cache counters. Cache filling is consistent with these
observations; the logs alone neither prove a leak nor rule one out. The owner
reports that the supplied music-folder demo played. Audio continuity and
performance cost were not measured.

[Sanitized evidence and input fingerprints](evidence/m15-omikron-music-resume-2026-09-23.json)
retain the exact phase and memory observations. Source inspection separately
found fixed FatFs dates and duplicate caching when a bundled song was selected
manually. The next SD update addresses both. Host testing also reproduced and
fixed a song-replacement/Resume lifetime race; that is not evidence that the
owner's RAM observation had that cause. [Music host evidence](evidence/m15-music-cache-host-2026-09-23.json)
records allocation tests and their limits. RTC dates, Advanced CRC scans, VMU
restore and expanded Settings remain pending console acceptance. Use
[the focused app tests](apps-round-four.md); no new optical benchmark or burn is
required.

## Dead or Alive 2 resume and app checks — 2026-09-23

Runtime **1d48aaf1412e** completed the remaining **387,858,912 bytes** of a
Dead or Alive 2 capture in **548.953593 s**, averaging **689.98 KiB/s** for that
resumed segment. **All three tracks matched TOSEC**. The log confirms the
reported slowdown: despite `capture_read=dma`, that segment used **zero DMA
chunks and 5,154 PIO chunks**. Its duplicate summary repeats the same counts.
This was an ordinary recovery run supplied by the owner, not a new benchmark.

The preceding failed capture visibly exhausted **10/10 retries** at its final
unreadable sector; the saved job reported 34 cumulative retries. The submitted
report is **truncated**, beginning partway through those errors. It does not
retain the event that disabled DMA, so it cannot distinguish the existing
timeout/repeated-DMA-failure latch from another cause. The earlier capture's
PIO subtimer covers only its PIO requests, not every captured byte. The accepted
B-stop/lid-open DMA fix remains separately established by
[the September 20 evidence](evidence/dma-stop-fix-confirmed-2026-09-20.json).

**Quick Resume's size check took 0.375164 s** before acquisition resumed.
The preceding full Resume was stopped during its saved-prefix reread; this
does not change either mode's intended behavior. Automatic end readback was
off, and a later Verify was cancelled during disc identification before any
saved-file verification. The TOSEC result therefore applies to checkpoint plus
captured-stream CRCs; **this submission does not verify the final saved files**.

Normal estimated main-RAM use/reservation was **5,048,856 bytes (4.815 MiB)**,
with a sampled peak of **5,058,616 bytes** before Memory Test. That app then
passed **70/70 passes over its allocated 4 MiB**, with zero errors. Its allocation
accounts for the later **9,243,168-byte** sampled peak; that peak must not be
attributed to ripping or music. Separate video/audio RAM is excluded. This log
does not measure the CPU or throughput cost of music.

Disc insertion identified Dead or Alive 2, then Omikron, and later reported an
empty drive. System preferences saved and reloaded within the session; cold-boot
persistence was not established here. L did emit an mstats log entry. Network
inspection correctly reported no supported Ethernet adapter; no connection test
was performed.

[Sanitized aggregates and input fingerprint](evidence/m15-doa2-resume-2026-09-23.json)
retain the exact timing and scope without publishing the raw report or private
device/storage details. Follow [the next app acceptance round](apps-round-four.md)
on the existing boot disc. The reader is not being rebenchmarked.

## Omikron final-track timeout and app round — 2026-09-23

Runtime **0599097a8bfb** started a new **Omikron: The Nomad Soul** capture.
The uploaded report's older free-text experiment note names another game; its
identified title and operation establish the actual workload. It committed
**1,201,396,896 of 1,203,979,392 bytes (99.7855%)**, finishing four tracks before
the final track failed. Capture wall time was **1257.766055 s (20 min 57.8 s)**,
or **932.80 KiB/s** of committed data including the terminal recovery waits.

A late DMA read timed out, disabling DMA until reboot. The subsequent PIO
fallback could not finish abort recovery and reported **RESET REQUIRED**. The
console preserved the partial checkpoint and saved a diagnostic report
automatically; the submitted file is a later manual report. Its generic
`CAPTURE/VERIFY FAILED` label does **not** establish a verification failure:
acquisition had not finished, automatic end readback was off, and neither a
saved-file verification phase nor a reference result appears. CRC32, DMA,
UI 2 Hz and full saved-prefix checking for Resume were selected.

UI scheduled time was **107.425 s / 1263.176 s**, reported as **8.5%**. Estimated
main-RAM use/reservation and its sampled peak stayed at **2,859,544 bytes**.
This failed, different-disc run is not a controlled UI speed comparison. The
log does not identify the physical cause of the stall, independently verify
the saved bytes or provide a final DMA/PIO transfer-count summary.

[Sanitized aggregates and input fingerprint](evidence/m15-omikron-timeout-2026-09-23.json)
record the original report's size and SHA-256. The raw report, hardware
identifiers, storage geometry, full disc identity and card paths are not copied
into this evidence record. Recovery uses the existing reset guard: reboot
before Resume, preserving the partial job. No reader/recovery policy changed.

The next app build adds idle insertion-title identification, clearer operation
and reset messages, phase ETA, separate system settings, optional RAM-cached
menu music, Memory Test, VMU listing/SD backup and network-adapter inspection.
**All of these new app paths still need physical-console acceptance.** Identity
polling and identification use the single worker only while idle; music pauses
before foreground work. The finished acquisition engine remains unchanged.
Use [the app acceptance guide](apps-test.md) on the same bootstrap CD; no new
optical benchmark or repeat full rip is required to test the apps.

## Ripper destinations and reference results — 2026-09-23

The next UI update adds a saved destination (default `/Games`), title-numbered
job folders, named GDI descriptors, Advanced actions and a structured stream-CRC
badge. Only a full catalogue match is green; partial/reference-unavailable
results and saved-file readback remain separate. See [ripper controls](ripper-controls.md).

Both baseline suites passed on clean `54711b931554` before the limited
`capture.c` destination/metadata/result changes; the protected source hashes
matched before and after that baseline. Acquisition, DMA, command and retry
behavior remain unchanged. New host tests pass on FAT32 and exFAT for naming,
collisions, full-identity resume selection, legacy fallback, path bounds,
publication failure/recovery and structured reference results.

**Pending on hardware:** destination selection/persistence, one ordinary named
capture with its catalogue result, and complete saved-file checking on a PC.
The same bootstrap CD is used. No new optical benchmark or measured speed claim
is part of this change. A dedicated salvage workflow remains planned.

## Completed MDK2 on the restored menu — 2026-09-23

The owner's initial impression that speed was restored is now accompanied by a
completed log for runtime **8bae3efe7c2f**. Its [sanitized evidence](evidence/m15-mdk2-2026-09-23.json)
records **all 31 tracks captured and TOSEC FULL TRACK MATCH** using stream CRC32.
Capture took **1223.545181 s (20 min 23.5 s)** at **973.96 KiB/s**. CRC32,
automatic end readback Off, DMA and UI 2 Hz were active; no capture retry messages
appear. Saved bytes were not reread, and this job has no supplied PC verification.

The accepted same-disc Trip 12 averaged 1011.67 KiB/s. This run is **3.73% slower**,
adding 45.61 s of capture time. UI scheduled time is reported as **8.3%**, versus
4.9% in Trip 12. Its extra 45.032 s of UI scheduled time nearly matches the
extra 45.936 s of whole-operation wall time, supporting remaining UI overhead.
These overlapping timers cannot be added to the write/hash wall times. The
earlier first-shell 12.4% figure used another game, so that comparison does not
isolate the display-clear change.

This completed ordinary capture supports the restored-menu runtime. It does not
establish the later destination-browser package's hardware acceptance and does
not call for changing or rebenchmarking the accepted reader.

## M1.5 first UI report — 2026-09-23

The owner reports that the shell seems functional during an ongoing game rip,
with a highest observed speed of about **933 KiB/s**, and requests restoration of
the original K-UI menu design. [Recorded observation](evidence/m15-shell-first-ui-report-2026-09-23.json).
No completed-rip average, build identifier, effective options or new verification
log accompanied this message. It does not replace the accepted reader results or
establish a performance regression. The remaining UI checks are still pending.

The follow-up UI update restores the original assets/layout and the earlier KOS
store-queue screen clear. This is a source-level display correction; its effect
on physical-console throughput has not been measured. The reader is unchanged.

### Completed log received after that observation

The uploaded log identifies
runtime **24d5cfe735d7** and **The House of the Dead 2**, not the restored-menu
update. [Sanitized results and input hash](evidence/m15-house-of-the-dead-2-2026-09-23.json).
The raw log remains in the project conversation and is not published here.

- All three tracks captured; **TOSEC FULL TRACK MATCH** for US v1.001 [12S].
- **1,188,966,576 bytes in 1273.291252 s: 911.9 KiB/s**, or 21 min 13 s of
  capture. Including setup/finish: 1278.391955 s (21 min 18 s), 908.3 KiB/s.
- CRC32, end readback Off, DMA, UI 2 Hz. **15,795 DMA chunks and
  four PIO chunks**; the duplicate summary lines describe the same counts.
- UI scheduled time **159.235 s / 1278.394 s**, reported **12.4%**, versus 5.1%
  in Trip 11, 4.9% in Trip 12 and 4.1% in the accepted FAT32 Sword run. This
  supports increased UI overhead. It does not isolate the clear's cost or prove
  the newer runtime's effect. UI time overlaps the stage wall timers.
- Preferences saved, reloaded and applied in the same session; L mstats,
  benchmark Stop and capture auto-report save are evidenced. Reboot persistence
  and restored-layout appearance still need their own observations.

Saved tracks were **not reread**; the reference match uses captured-stream CRCs.
No PC/saved-file verification was supplied for this job. The initial benchmark's
unreadable-disc result precedes the successful capture. The current
next step at that point was installing **8bae3efe7c2f** on the existing card and
checking its appearance during ordinary use. Current pending named-output checks
are recorded above. No reader changes are called for by this log.

These results cover the uploaded logs, storage fixtures and user reports received on
2026-09-16 and 2026-09-17. They establish the specific checks below on the user's console;
they do not complete the full dumping milestone.

## MDK2 optical command timing and automatic report save

The untruncated `diagnostics(20260917-220946).txt` identifies SD runtime
`92484724c538`. It is a **manual report** containing the preceding automatic
save's success message, `Report saved: /KUI/probes/p0005/diagnostics.txt`.
Automatic report saving after controlled Stop therefore worked according to
the console log; the separately saved automatic report was not uploaded.

This run resumes the same MDK2 job, `/KUI/dumps/df838eac34967ae16-0002`, from
checkpoint 11 with **75576816 committed bytes**, exactly where the prior log
ended. The completed tracks 1-3 and partial track 4 pass the console's CRC32
and SHA-256 checks. The 72.08-MiB prefix pass takes **212.448470 seconds**, or
**347.40 KiB/s**. Saved-file read calls consume 160.577146 seconds; SHA-256
and CRC32 together consume 51.099671 seconds. These are resume costs, separate
from the capture measurements below.

New capture spans **audio track 4, FAD [62456,70040)**: **17837568 bytes**
(7584 sectors) in **305.611520 seconds**, averaging **57.00 KiB/s**. The final
committed count is **93414384 bytes**. Thus the profiling build establishes
essentially the same slow audio throughput as the preceding 57.46-KiB/s run;
it does not establish a speed improvement.

| Capture category | Seconds | Share of capture wall time |
| --- | ---: | ---: |
| Optical read callback | 270.600197 | 88.54% |
| Track-file writes | 21.921474 | 7.17% |
| SHA-256 | 11.033157 | 3.61% |
| CRC32 | 1.989986 | 0.65% |
| Checkpoint sync/publication | 0.050895 | 0.02% |
| Other | 0.015811 | less than 0.01% |

The new optical subtimers separate costs that the older logs combined:

| Optical operation | Elapsed seconds | Calls | Time inside scheduler waits |
| --- | ---: | ---: | ---: |
| First PIO read | 130.570325 | 238 | 124.779241 s across 15687 waits |
| Second PIO read of the same range | 138.971324 | 238 | 133.207952 s across 16684 waits |
| Raw mode setup | 0.005312 | 238 | Not measured separately |
| Buffer preparation, checking and copy | 1.033794 | — | Not applicable |

The two read commands together spend **257.987193 seconds inside scheduler
waits**, 84.42% of capture wall time and 95.34% of the optical adapter's timed
interval. The runtime calls `thd_sleep(1)` at each wait; the measured elapsed
averages are **7.954 ms** for the first read and **7.984 ms** for the second.
There are 66.91 and 71.10 polls per command on average, respectively, for
32-sector requests. This makes the repeated read and the frequency of waits
between firmware service calls concrete optimization targets. These averages
are not a distribution of individual sleeps, and elapsed wait time includes
time in which the drive can progress or other threads run: it must not all be
treated as recoverable overhead.

Simply subtracting the measured second-read time while holding every other
cost fixed gives **104.53 KiB/s**. That is an arithmetic comparison, not a
prediction: a single sequential read and a different polling policy can also
change the first read's latency and other costs. Removing SHA-256 alone cannot
explain or fix this result; both capture hashes together account for 4.26%.
Mode setup is only 0.00174% of capture time. SD write calls average
**794.63 KiB/s**, so this trace does not show track-file writes imposing the
57-KiB/s overall rate.

There are **zero application retries, comparison mismatches or buffer-guard
failures**. The extra optical request ends in the user's controlled Stop:
read 1 completes 238 times; read 2 completes 237 times and is cancelled once.
Its abort succeeds, and 237 successful 32-sector chunks are committed. The
single optical `fatal` result describes that cancellation, not an exhausted
sector retry or unrecoverable media error. Internal drive retries are not
visible in these counters. The initial initialization command's sense 6/40
is followed by successful identification, prefix validation and capture.

Main-RAM use/reservations and sampled peak stay at **900888 bytes**, with
**15876328 bytes available**. The allocator's 232 free bytes describe only
its existing arena; a further 15876096 bytes remain unclaimed main RAM.
This log supplies no evidence of memory pressure or growth during the run.

[Machine-readable results](evidence/mdk2-optical-waits-2026-09-17.json) retain
the upload's SHA-256, exact phase/track/optical counters, prefix hashes and
derived rates. All timing groups and byte/FAD continuity checks reconcile.
MDK2 remains incomplete, and the uploaded log alone does not independently
verify the saved track bytes or an uninterrupted/reference dump match. The
profiling test has answered its question; the next hardware round should
measure the optical performance changes, using the existing bootstrap disc,
rather than repeat this unchanged baseline. See the [optical test guide](optical-test.md).

## MDK2 isolated audio capture and successful checkpoint resume

The untruncated `diagnostics(10).txt` comes from SD runtime `0ef58878ccdd` in
a fresh runtime session. It resumes the same MDK2 job as `diagnostics(9).txt`,
`/KUI/dumps/df838eac34967ae16-0002`, from checkpoint 9 with **59620848 committed
bytes**. Tracks 1-3 and the saved track-4 prefix pass the console's CRC32 and
SHA-256 checks before any new writes. Capture then starts at **track 4, FAD
55672**, writes **15955968 new audio bytes** (6784 sectors), and stops with
**75576816 committed bytes**. The counts reconcile exactly across the two logs.

The entire new capture phase is audio. It lasts **271.160576 seconds** (4 minutes
31 seconds), averaging **57.46 KiB/s**. This directly establishes slow audio
capture in the reported 50-KiB/s range; the log does not record individual
instantaneous screen readings or establish the earlier track-5 duration.

| Capture category | Seconds | Share of capture wall time |
| --- | ---: | ---: |
| Optical read callback | 240.661598 | 88.75% |
| Track-file writes | 19.840484 | 7.32% |
| SHA-256 | 8.596927 | 3.17% |
| CRC32 | 1.983868 | 0.73% |
| Checkpoint sync/publication | 0.065075 | 0.02% |
| Other | 0.012624 | less than 0.01% |

SD write calls average **785.36 KiB/s**, compared with 801.95-804.21 KiB/s in
the earlier runs. The much slower overall capture rate is dominated by the
optical callback. Its combined timer still cannot identify how much belongs
to mode setup, the first/second read, polling or buffer checks. SHA-256 is
3.17% of this capture; removing it alone would not resolve the slowdown.
There is no capture EDC bucket because the new bytes are all audio; the setup
phase's EDC checks are separate.

The preceding **resume prefix check** takes **167.466368 seconds** (2 minutes
47 seconds) for 56.86 MiB, averaging **347.67 KiB/s**:

| Resume category | Seconds | Share of resume wall time |
| --- | ---: | ---: |
| Saved-file reads | 126.206689 | 75.36% |
| SHA-256 | 34.167135 | 20.40% |
| CRC32 | 6.431161 | 3.84% |
| Other | 0.661383 | 0.39% |

The SD reads alone average **461.33 KiB/s** within those calls. Hashing adds
about 40.60 seconds to the prefix pass. These are measurements of this build,
not an A/B comparison with the other ripper. The 12.615276-second setup phase
is separate from both resume and capture. Every phase's categories sum exactly
to its wall time.

The final `CMD 16 CANCELLED` is the controlled Stop; 213 optical calls versus
212 successful writes account for the cancelled request. The log reports
**zero application retries**, and memory use, sampled peak and allocator
counters remain unchanged at the earlier values. This does not expose internal
drive retries. The initial `CMD 24 FAILED` is followed by successful TOCs,
identification, resume and capture; it is not a capture retry failure.

This establishes checkpoint/prefix validation and continued hardware writing
after a new runtime startup, followed by another controlled Stop. The log
does not independently identify how the console was restarted. MDK2 remains
incomplete; final saved-file verification and equality with an uninterrupted
or independent reference dump are still untested for this resumed job.

[Machine-readable results](evidence/mdk2-audio-resume-2026-09-17.json) retain
the input fingerprint, exact counters, prefix hashes and continuity checks.
The requested baseline test is complete. The [next steps](performance-test-plan.md)
are optical subtimers/automatic reports and a versioned fast-resume design;
another identical baseline or full rip is unnecessary. This evidence update
does not change the runtime.

## MDK2 capture reaching high-density audio

The follow-up `diagnostics(9).txt` is an untruncated log from SD runtime
`0ef58878ccdd`, MDK2 job `/KUI/dumps/df838eac34967ae16-0002`. It completes tracks
1-3 and stops inside **audio track 4**. The saved prefix is 59620848 bytes
(56.86 MiB): 50782032 data bytes and 8838816 audio bytes. Track 4 has 3232
committed sectors (7601664 bytes); the next FAD is 55672 if this checkpoint is
still the newest job state. The preceding audio track 2 contributes 526 sectors.

The measured capture lasts **409.071777 seconds** (6 minutes 49 seconds), with
an overall rate of **142.33 KiB/s**. This mixes the earlier data tracks with audio;
the file has no per-track durations or instantaneous speed records, so it does
not directly measure the user's on-screen 50 KiB/s observation or their separate
roughly-20-minute duration report.

| Capture category | Seconds | Share of capture wall time |
| --- | ---: | ---: |
| Optical read callback | 294.224269 | 71.92% |
| Track-file writes | 72.602139 | 17.75% |
| SHA-256 | 33.542500 | 8.20% |
| CRC32 | 6.281438 | 1.54% |
| Sector EDC | 2.005522 | 0.49% |
| Checkpoint sync/publication | 0.354948 | 0.09% |
| Other | 0.060961 | 0.01% |

The counters sum exactly to the phase wall time. SD write calls average
**801.95 KiB/s**, close to 804.21 KiB/s in the earlier track-1 sample. Main-RAM
use, sampled peak and allocator counters remain at the same values as that
sample. There are **zero recorded application retries**. `CMD 16 CANCELLED`
occurs at the controlled Stop; one extra optical call has time but no committed
bytes (795 disc calls versus 794 successful writes). It is not evidence of a
failed sector or an exhausted retry loop. Internal drive retry activity is not
separately visible in this instrumentation.

The larger optical share, stable write-call throughput and unchanged memory
support investigating the optical path through the audio portion first. The
callback still combines both reads, mode setup, polling and comparisons, so
the mechanical transfer rate or one specific driver operation cannot yet be
identified as the cause. SHA-256's 8.20% is not the dominant cost in this run.

As an explicitly conditional estimate, charging data bytes at the earlier
track-1 sample's total per-byte time leaves about 143.86 seconds for the audio
bytes, equivalent to about 60 KiB/s. Different data-track speeds, command sizes
and run conditions can invalidate this assumption. It is consistent with slow
audio capture, not a replacement for a direct audio-only measurement.

[Machine-readable follow-up results](evidence/mdk2-audio-entry-2026-09-17.json)
retain exact counters and this estimate's limitations. The isolated audio
measurement above now supersedes the conditional estimate for choosing the
next change. It resumes this exact prefix and measures resume and capture
separately. See the [performance test plan](performance-test-plan.md).

## MDK2 capture timing and resume overhead

`P1 diagnostics.txt` and `P2 diagnostics.txt` identify SD runtime
`0ef58878ccdd`, MDK2 and the same job `/KUI/dumps/df838eac34967ae16-0001`.
P2 starts with the exact bytes of P1 and adds another log-save action. They are
two snapshots of **one** operation, not separate capture trials. Both logs are
untruncated. The operation stopped during data track 1 after 9120 sectors
(21450240 bytes) and **112.024259 seconds** of measured capture, averaging
**186.99 KiB/s**, with zero recorded application retries.

| Capture category | Seconds | Share of capture wall time |
| --- | ---: | ---: |
| Optical read callback | 70.794132 | 63.20% |
| Track-file writes | 26.047232 | 23.25% |
| SHA-256 | 11.945064 | 10.66% |
| CRC32 | 2.269059 | 2.03% |
| Sector EDC | 0.843589 | 0.75% |
| Checkpoint sync/publication | 0.104441 | 0.09% |
| Other | 0.020742 | 0.02% |

The buckets add exactly to the capture wall time. Disc, EDC, write and both
hash buckets each account for the same 21450240 logical bytes in 285 chunks of
32 raw sectors. The optical callback includes both guarded PIO reads, mode
setup, polling, comparisons and scheduling. This measurement does not separate
those costs or establish that optical media transfer alone consumed 63.20%.

SHA-256 is a measurable cost but not the largest contributor in this trace.
Subtracting all measured SHA-256 time while holding other costs fixed gives
209.31 KiB/s, an idealized 11.94% speed increase, not a prediction of an actual
modified build. It does not account for the gap to the previously reported
DreamShell capture rates. SD write calls alone averaged 804.21 KiB/s for this
sample; that is neither a complete-rip rate nor a hardware maximum. No saved-file
verification or resume timing breakdown is present in these two logs.

Startup, operation start, controlled Stop and log-save snapshots all report
881976 bytes of main RAM used/reserved, 15895240 available, a sampled peak of
881976, and heap in-use/system counts of 88948/91708 bytes. These snapshots show
no growth or main-RAM pressure in this short operation; they do not establish
long-run memory behavior.

The user separately reports a longer run, roughly 20 minutes before noticing
capture near 50 KiB/s around track 5. The TOC identifies tracks 1/3/31 as data,
and 2 plus 4-30 as audio. The severe reported slowdown therefore occurred in
the audio portion, which this track-1 trace does not measure. The later mixed
data/audio and isolated audio logs are analyzed above. Photos show a
later checkpoint with about 70 MiB saved and a resume prefix check near
355-365 KiB/s, but not completion of that resume or its capture timing.

Current Resume deliberately rereads all committed bytes, validates CRC32/SHA-256
and rebuilds incremental hash contexts before appending. At 360 KiB/s, 70 MiB
takes about 199 seconds for that prefix alone. This is a separate source of
waiting from slow disc capture. Checkpoints currently retain finalized hashes,
not resumable SHA-256 state; a faster checkpoint resume would require a format
and validation-policy change. No checks have been removed by this evidence
update. Full saved-file and independent-reference verification remain separate.

[Machine-readable timing results](evidence/mdk2-timing-2026-09-17.json) retain
input fingerprints, exact counters, memory values, assumptions and limitations.
The isolated audio and resume baseline is now complete. Next performance
evidence should separate optical command work within the callback; hashing
and SD I/O must remain separately accounted for. See the
[test plan](performance-test-plan.md) for the next runtime work.

## First completed capture: Sword of the Berserk

The user reports that **SWORD OF THE BERSERK GUTS RAGE** completed capture and
saved-file verification on SD runtime `2657a97031e3`. The uploaded manifest
identifies that build/title and declares `complete` and `saved_data_verified`.
This build publishes the final manifest/GDI only after the complete SD reread
passes. Both checkpoints and the GDI layout support the reported completion.
The uploaded raw bytes independently establish the checks for tracks 1 and 2
below; track 3 was intentionally omitted.

| Track | Sectors | Bytes | CRC32 | Independent PC result |
| --- | ---: | ---: | --- | --- |
| `track01.bin` | 776 | 1825152 | `bcec7767` | Length, CRC32 and SHA-256 match the manifest and both checkpoints |
| `track02.raw` | 526 | 1237152 | `0ff934e3` | Length, CRC32 and SHA-256 match the manifest and both checkpoints |
| `track03.bin` | 504150 | 1185760800 | `2cfb5dcb` | Not supplied; values are recorded by the console, not independently recomputed |

The three declared tracks total **1188823104 bytes**. Their bounds, sector sizes,
type-change gap exclusion and `disc.gdi` entries agree with the declared profile.
This verifies metadata consistency, not agreement with an independent disc catalog.

Both 4096-byte checkpoints pass independent Python CRC32 and structure checks,
including identity/build, reserved bytes, track bounds/order and alternating
sequence parity. `checkpoint-b.bin` is sequence 126 with 503808 track-3 sectors;
`checkpoint-a.bin` is sequence 127 with all 504150 track-3 sectors and hashes
matching the completed manifest. Both record **zero retries**. The earlier
track-3 prefix hash could not be checked without track 3. Valid checkpoints on
their own do not demonstrate a hardware Stop/reboot/Resume cycle.

`diagnostics(7).txt` is from **addd439aaea5**, not the capture build. Its bytes
are identical to the previously examined `diagnostics(6).txt`; it contains the
earlier nine-sample disc probe and storage probe, with no capture/mstats/timing
output. `storage(3).bin` and `storage(3).json` are also identical to the previous
storage uploads. Rechecking them passes all 2097325 expected bytes and CRC32
`a70f77ca`, but establishes no additional independent console session.

The user reports capture around 210-220 KiB/s. Earlier photos show capture near
209 KiB/s and saved-file verification near 311 KiB/s, with estimated main RAM
around 860 KiB and a sampled peak around 869 KiB. These are spot observations,
not whole-operation averages or detailed allocator measurements. The original
capture build has no timing instrumentation. Timing build `0ef58878ccdd` has
since supplied the MDK2 measurement above; this evidence change adds no runtime code.

[Machine-readable results](evidence/sword-of-the-berserk-2026-09-17.json) retain
the original upload names, lengths, SHA-256 fingerprints, per-track checks and
decoded checkpoints. No game track bytes are stored in the repository.

Still needed: local PC verification of track 3, a compatible independent
reference comparison and final verification of a complete resumed hardware
dump. MDK2 now supplies data/audio timing and a successful checkpoint resume
through new audio writes, followed by controlled Stop, as described above.
If the original capture log remains available, save/upload the report whose
header says `K-UI SD runtime 2657a97031e3`; do not repeat the full capture just
to replace a lost log. Keep the completed dump for later hash comparisons.

## Capture runtime host coverage

The SD capture runtime implements full-track GDI capture, CRC32/SHA-256 saved
file reread, checkpointed controlled resume and an mstats action. Host FAT32 and
exFAT image tests exercise complete six-track output, independent Python hash
verification, early/middle/late/verification Stop, resumed-versus-uninterrupted
equality, a damaged newest checkpoint, an uncommitted suffix, bounded retries,
media-change and storage-failure handling, corrupt-prefix and wrong-disc refusal,
and preservation of existing completed jobs. These are synthetic host tests.

The first physical completion and MDK2 resume through new writes are documented
above. Full PC track verification, final verification of a complete resumed
hardware dump and an independent disc-reference match remain pending. Use
[the capture guide](capture-test.md) with the existing bootstrap CD; the earlier
physical evidence below applies to the diagnostic builds identified there.

## SD runtime session and confirmed startup selection

Tested source: `addd439aaea504d765498f214a1e5409d5862fee`.
The [successful combined build](https://github.com/TPMJB/K-UI-NeXT/actions/runs/35147067592)
contains the CD bootstrap and SD runtime for this build. Keep using the existing
disc; this evidence update does not require a new binary or another burn.

The uploaded `diagnostics(6).txt` starts with `K-UI SD runtime addd439aaea5`
and records `Running SD runtime build addd439aaea5`, with successful disc and
storage operations. After initially reporting a CD bootstrap heading, the user
clarified that holding B selects CD bootstrap and booting without touching any
buttons reaches SD runtime. This resolves the apparent discrepancy and confirms
the normal SD handoff and manual fallback selection.

Source inspection shows both the title and saved report header use the same
compile-time role. The CD shows its own role during startup even on a successful
load; it remains there when loading is skipped or fails. The user also reports
that cold boots work. No count was supplied, so this is recorded as a successful
user-reported check rather than a documented five-boot sequence.

The user then completed the three-step missing-file/checksum/restoration check
on the same disc. With the runtime renamed, the console reported that
`runtime.kui` failed or was missing (wording recalled approximately). The
`bad-checksum.kui` test produced `Runtime Checksum mismatch`. Renaming the good
file back restored normal operation. These are user-reported hardware passes
for missing-file detection, payload-checksum rejection and good-runtime
restoration. No new log or screenshot was supplied, and diagnostic probes or
controller responsiveness during automatic fallback were not separately reported.

| Check | Observed result |
| --- | --- |
| SD execution handoff | Confirmed by the runtime log and the user's no-buttons startup report |
| Hold B at startup | User confirms CD bootstrap selection; fallback probe results were not separately supplied |
| Missing runtime file | User-reported pass: failed/missing-file explanation shown |
| Bad payload checksum | User-reported pass: `Runtime Checksum mismatch` shown |
| Restore good runtime | User-reported pass: normal operation returns after renaming the original file back |
| Cold boots | Dozens, with no controller problems (user report, 2026-09-20) |
| Video mode | 640x480 NTSC interlaced, buffered |
| Disc TOCs | Both density regions parsed; three tracks |
| Raw disc reads | All nine samples passed repeat and buffer-guard checks |
| Data-sector comparison | All six data samples matched independent cooked reads |
| Audio samples | Three passed repeat/guard checks; offset and subchannels were not validated |
| Storage layout | exFAT, MBR volume start 2048, 249997312 volume sectors, 131072-byte clusters |
| Console storage probe | `/KUI/probes/p0009`, 2097325 bytes; write, remount and reread passed |
| PC storage verification | Exact length, every expected byte and CRC32 `a70f77ca` passed |

The initial `CMD 24 FAILED` with sense `6/40` was followed by successful
initialization and the complete disc probe. The TOCs, sample addresses and
sample CRC32 values match the prior session; this does not establish a second
disc layout or independent full-disc accuracy.

The PC check ran `tools/verify_probe.py` on temporary copies of the uploaded
`storage(2).bin` and `storage(2).json` using the standard fixture filenames.
The original uploads were unchanged. The storage pattern is deterministic,
so its hash matching previous successful fixtures is expected.

| Uploaded file | Bytes | SHA-256 |
| --- | ---: | --- |
| `diagnostics(6).txt` | 2514 | `d2a93a39de88d08c3395d40c6031e8cbb29427c4d7301eec5cb029303d5310b3` |
| `storage(2).bin` | 2097325 | `e19146d42e4161db7890e39427fc5ccb95ef1da2a97b910c224d03d8cda6daff` |
| `storage(2).json` | 115 | `618b9b5553f0932666bcf0363e235ba7d5c1884974106cc353afd886f4b44849` |

## Earlier evidence

- `99a069777c7e`: both TOCs, nine raw samples, six data comparisons and the
  exFAT console/PC storage checks passed. The first five uploaded diagnostic
  files are progressively longer snapshots of one session, not five boots.
- `cf8210bc5442`: the user explicitly confirmed the rendering fix removed the
  visual errors. Disc samples and exFAT console/PC checks passed again.
- The user reported a FAT32 console pass on a 32 GB card. Its log and fixture
  remain unavailable because they lack a compatible reader. FAT32 SD runtime
  loading has not been established on hardware.

## Remaining checks on the same bootstrap disc

These are unconfirmed by the supplied logs and user reports. If they were already run,
record the observed outcome rather than asking for another burn or repeating
successful work.

**Update 2026-09-20: most of these are now done.**

- **Done:** all five rejection fixtures fail safely on hardware, each with its own reason and a
  usable fallback ([evidence](evidence/m12-runtime-rejection-2026-09-20.json)); dozens of cold boots
  with no controller problems; a second retail disc with a different TOC (MDK2, 31 tracks); full
  PC/reference verification of complete dumps, including a dump resumed twice
  ([handoff](HANDOFF-disc-reader.md)).
- **Hardware recorded:** NTSC console, motherboard reported as "V1A" (most likely VA1), RF video
  cable, SanDisk 128 GB microSD (Endurance line), exFAT. The SD adapter model is not recorded.
- **Done since:** the lid opened mid-capture stops cleanly and resumes to a TOSEC-verified finish
  ([evidence](evidence/lid-open-omikron-2026-09-20.json)); a disc with physical damage retries a
  fixed 10 times, pins the exact bad sector and stops with the partial job kept
  ([evidence](evidence/scratched-omikron-retry-2026-09-20.json)).
- **Done since:** FAT32 end to end: the runtime loads from a FAT32 card, the storage test passes,
  and a whole disc rips byte-exact and PC-verified
  ([evidence](evidence/fat32-sword-dma-2026-09-20.json)).
- **Still open:** a card that fills up mid-capture (host tests only).

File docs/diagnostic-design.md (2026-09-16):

# Diagnostic implementation decisions

This implements the first M1.0/M1.1 test vehicle. Passing host tests and compiling
are prerequisites to a console test; neither completes hardware acceptance.

This page documents the original probes. The current SD runtime additionally
implements M1.3/M1.4: [capture/checkpoint design](capture-format.md),
[combined hardware test](capture-test.md), and [mstats accounting](memory-stats.md).
References below to deferred capture/resume describe the original probe scope.

The M1.2 bootstrap now loads a validated, versioned runtime from SD before an I/O
worker exists. It closes/unmounts/disconnects SD before KOS's execution handoff.
The runtime is a separate executable with its own kernel and no auto-loader, so
it does not recursively reload itself. Missing/invalid files and startup B lead
to the embedded diagnostic. See [the boot contract](sd-bootstrap.md).

## Ownership and lifetime

One 64 KiB-stack worker owns optical and SD/filesystem I/O. The main thread polls
the controller, draws an in-memory log, and exchanges requests under a mutex.
It never checks the drive or writes a log concurrently with the worker. KOS's
optional CD-ROM/ISO9660, dcload and serial debug output are disabled. Code and the
KOS minifont are in the executable, so the boot CD can be removed.

Video uses KOS's multibuffer mode. The main thread clears and draws a complete
frame into the non-displayed drawing buffer, waits for vertical blank, then
calls `vid_flip(-1)` to display it and select another drawing buffer. Waiting
before drawing into the displayed buffer does not protect a redraw that lasts
beyond the blanking interval. The startup log records the selected cable/mode
and interlace state. The user confirmed the fix removes the visual errors on
their setup; see the [hardware evidence](hardware-evidence.md).

The drive adapter uses direct documented KOS firmware calls and PIO only. The
small upstream BSD bus-activation helper retains its source attribution. No
firmware patch, DMA, streaming command or shared CD wrapper is used.

Submission and polling share one deadline: 10 seconds for INIT, 5 seconds for a
TOC/read, then up to 1 second to confirm abort. INIT permits at most two additional
attempts, only for disc-change sense. A failed abort permanently blocks further
disc commands until console reset. Firmware-visible parameters and buffers are
static, so an unfinished request cannot access freed memory. Polling deadlines
cannot interrupt a firmware call that itself never returns; that remains a
physical-console test limitation. The diagnostic does not claim proven drive
reset/recovery on damaged discs.

## What disc checks establish

Both density TOCs must parse before samples are read. Each session may contain
multiple tracks. Starts are FAD addresses; the checked conversion to displayed
GDI LBA subtracts 150 exactly once. TOC ends are **not** final dump boundaries.

The probe checks the start, midpoint and a late interior sector of every track,
deduplicating samples in short tracks. The late sample stays 150 sectors away
from a possible following pregap. No data is discarded from a dump: this build
does not dump tracks or generate GDI files.

Each raw sector is read twice into guarded buffers with different initial fills.
Equal results detect common underfill and instability; guards detect nearby
overwrites. Data sectors also require a supported Mode 1 or Mode 2 Form 1 layout,
two matching guarded 2048-byte reads, and equality with the raw-sector payload.
Audio gets repeat/guard checks, not offset correction. CRC32 and header bytes are
logged. EDC/ECC checking, independently verified reference hashes, subchannels,
full-track captures and disc fingerprints are later work. Matching samples do
not prove every byte on the disc can be read correctly.

## Storage and completion

The adapter accepts a 512-byte-sector FAT32/exFAT superfloppy or exactly one
supported MBR primary partition. It refuses GPT, extended/ambiguous layouts and
cards outside its 32-bit block range. Every FatFs request is range-checked and
translated within the selected volume. Any backend I/O/sync error latches the
device unavailable until the next explicit connection, preventing an automatic
remount from silently continuing a failed job. FatFs formatting APIs are absent.

The serial backend uses KOS SCIF with CRC enabled. Its `CTRL_SYNC` performs a
fresh SD read; the pinned KOS driver waits for the previous write's busy period
to end before issuing that command. This is deliberately different from the
upstream block-device no-op flush. The 500 ms ready wait does not guarantee
survival of sudden power loss, removal or opaque card-controller caching.

The storage test writes at least 2 MiB + 173 bytes and crosses two clusters on
larger-cluster volumes. Each byte is derived from its position. Successful
writes advance accounting only by their exact requested size. The test flushes,
closes, remounts, reopens, checks the file size, and rereads every byte against
the independent position-derived expectation. It also compares streaming CRC32.
A `storage.json` completion manifest is written only after that verification.

The PC tool recomputes the byte pattern and CRC32 and reports SHA-256 using
Python's standard library. A SHA-256 capture hash in the console dump format is
deferred to M1.4. The predictable storage fixture already allows byte-for-byte
validation without trusting a self-reported hash.

Each test/report uses an exclusively created `/KUI/probes/pNNNN/` directory and
new files. Failed or cancelled tests retain their partial data without a
completion manifest. B finishes the current filesystem call and performs close;
there is no resume support yet. Filesystem allocation scans and internal SD read
retry loops are not covered by the optical command deadline. This UI therefore
shows Stop requested rather than promising an immediate storage abort.

## Host validation

`make test` checks finite command behavior, abort failure, clock wrap,
partition bounds, media-error latching, malformed TOCs/raw layouts, CRC vectors,
chunking, and PC detection of corruption/truncation/incomplete results.

`make test-images` compiles actual FatFs and the same storage probe used by the
console. It creates FAT32/exFAT fixtures with independent distribution tools,
checks successful filesystems with `fsck`, verifies repeated runs, tests MBR
translation with outside-partition sentinels, and injects write/sync failures and
controlled cancellation. It checks that failures cannot produce a pass result.
The FAT32 output is also exported through mtools and checked by the PC verifier.

AddressSanitizer and UndefinedBehaviorSanitizer are enabled in host builds. On a
restricted execution host where LeakSanitizer cannot inspect `/proc`, use
`ASAN_OPTIONS=detect_leaks=0 make test test-images`; this leaves address/undefined
checks enabled. CI uses the full default sanitizer configuration.

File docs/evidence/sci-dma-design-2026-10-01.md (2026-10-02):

# Original SCI DMA candidate — 2026-10-01

The initial SCI soak passed integrity but measured 521.75 KiB/s writes and
528.75 KiB/s reads. The owner also found DOA2 largely the same as SCIF and
requested a performance fix. These are the [accepted initial measurements](sci-soak-baseline-2026-10-01.md),
not evidence that the hardware's throughput potential has been reached.

The owner explicitly requires an original implementation: reference projects
may supply ideas, but SWAT's implementation must not be copied. The new DMA
code is written around the SH-4 register contract and K-UI's ownership model.
Existing source provenance and notices are retained.

## Transfer design

An optional payload-block operation removes the indirect callback and mode
setup from every data byte. SD commands, tokens, CRC bytes, busy waits, stop
commands and card-status checks retain their existing framing. Every received
sector is still CRC checked. A failed payload is never resumed by switching
methods halfway through the sector.

For eligible 512-byte reads, DMA channel 1 moves SCI receive data directly
into the caller's isolated, 32-byte-aligned RAM buffer. The CPU supplies exactly
512 dummy bytes to generate the clock; it no longer reads/clears the receive
register once per payload byte. The first validated build restored byte bit
order through the uncached alias, then calculated CRC in a separate pass.
The follow-up candidate combines reversal and CRC after DMA completion through
the caller's original alias, allowing isolated P1 buffers to use cache again
after the pre-DMA purge. No CPU access occurs while DMA owns the buffer.
The game reader's existing aligned sector cache avoids a second resident buffer.

Runtime writes use a separate aligned sector buffer, reverse the outgoing bits
before transmission and let channel 1 feed the transmit register. The follow-up
candidate computes CRC from the immutable original source while transmit DMA
is active. CRC is published only after successful completion; protocol CRC
bytes and response checking remain unchanged. This buffer and write
implementation are excluded from the read-only game resident.

DMA is borrowed only when the controller is enabled without a global error and
channel 1 has no active transfer, unacknowledged completion or enabled completion
interrupt. CPU interrupts are masked across the short claim/transfer/restore
operation. No DMA interrupt handler is installed. The SCI request is disabled
and channel state restored before restoring the CPU's interrupt mask. Global
DMA error flags are never cleared to force a transfer through.

Short, unaligned or otherwise ineligible transfers use a bounded block-polling
path. That path keeps at most one byte in flight, preserving tolerance for
interrupt latency. DMA failure stops the operation, latches a fault and returns
through existing SD cleanup; it does not silently turn a partial transfer into
a success. Both completion of memory transfer and the final serial byte must
be established before proceeding to CRC/response handling.

Runtime counters track completed DMA reads/writes, polled blocks and DMA
failures. Storage tests log deltas for the run and preserve them in successful
results' existing message field, including JSON and History. No on-card binary
result format change is required. These counters are excluded from the small
game resident. Polling counts include filesystem metadata and short transfers;
a nonzero count does not by itself mean the payload benchmark missed DMA.

The resident borrows the manifest's track records instead of keeping a second
16-track table. The SCI resident alone uses link-time optimization and SH call
relaxation. The protected memory reservation and stack limits are unchanged;
the SCI stack audit counts every final compiler-emitted frame, including
initialization, duplicate local names and optimized clones. Missing final
reports fail the build. SCIF and IDE keep their existing compilation settings.

## Validation and first console check

Host checks cover delayed transmit/receive flags, all byte values, exact sector
counts, DMA and polling paths, cache preparation, busy-channel fallback,
mid-transfer errors, bounded abort, state restoration and the next scalar SD
operation. Protocol tests exercise equivalent bulk/scalar framing, CRC
failures, stream limits and stop-command cleanup. Native builds must still
pass the instruction, resident memory and stack guards at their existing limits.

The first DMA build **cf8e7ea7866b** passed the owner's 15-minute soak with
416 MiB verified, zero errors/DMA faults and write/read 1,004.62/926.11 KiB/s.
DOA2 was substantially improved with a little lag remaining. See the
[hardware result](sci-dma-soak-2026-10-01.md). The cached processing build
**a6cb21895c37** subsequently passed a 4 MiB Quick check at write/read
1,104.35/1,052.72 KiB/s, zero errors/DMA faults. See the
[short result](sci-dma-cached-quick-2026-10-01.md); different presets prevent
a controlled sustained comparison, and neither establishes disc equivalence.

## Next feed and phase-measurement candidate

Receive DMA now seeds TDR with 0xff once, then clears observed TDRE exactly
512 times to generate the payload clocks. The existing programmed read path
already reuses the retained TDR value. This removes 511 redundant peripheral
writes per sector. A specialized bounded loop keeps the error check and the
10,000-poll limit for every byte while avoiding resident helper-call overhead.
Normal runtime `-O2` already inlined the old helpers; do not claim a runtime
call-overhead defect. DMA ownership, count/completion checks, final-edge guard,
fault latching, CRC and stream cleanup remain unchanged.

Storage tests alone enable an injected microsecond timer at DMA boundaries.
Successful sampled reads accumulate setup, transfer and post-DMA reversal/CRC
time; writes accumulate setup (including reversal/purge) and transfer time
(including overlapped CRC). Independent sampled-block counts supply the
denominators. Failed DMA attempts do not enter those totals. Counters still
include completed bus transfers whose protocol CRC is subsequently rejected;
integrity is reported separately by the existing error/result fields.

These are software phase durations, not clock-active measurements. Setup
starts after channel eligibility. Transfer includes CPU feeding, completion
waits, the final-edge guard and stopping SCI/DMA. Channel restoration, commands,
token/busy waits, polling fallback and filesystem work remain outside the
measured phases. Timer overhead is included; timestamps are never read inside
the byte loop, and no timestamp is inserted between enabling SCI and feeding.

Detailed counts/totals are additive `sci_profile` fields in the live
`result.json`, with totals also logged. The binary History format, CSV and
success-message DMA summary remain compatible; loading History does not
reconstruct the detailed profile. Timing is disabled before result saving,
and for normal runtime I/O. All profiling state/code is excluded from the
small game resident. The next console Quick report should locate whether the
remaining cost is transfer feeding, receive processing or outside these phases.
This candidate does not add a second DMA channel, cross-sector buffers, a CRC
table, longer interrupt masking, or changed game pacing.

Keep both original and first-DMA soaks as comparison points. Install matching `KUI/runtime.kui` and
`KUI/apps/games/retail-boot.kui`; the existing `6af5e11` boot CD and exFAT card
remain usable. First run Diagnostics → R → Storage tests → Quick once, and
inspect integrity, throughput and the DMA counts. A longer soak and another
DOA2 comparison should follow a successful short test. Do not claim a measured
speedup before receiving the new console result.

Hardware reference: [Renesas SH7750 hardware manual](https://www.renesas.com/en/document/mah/sh7750-sh7750s-sh7750r-group-users-manual-hardware),
sections 14 (DMAC) and 15 (SCI). The nominal 12.5 Mbit/s clock corresponds to
1.5625 MB/s before protocol, software and card overhead; sustained throughput
is a measurement, not a promise.

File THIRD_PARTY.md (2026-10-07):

# Source provenance and licenses

New code is GPL-3.0-only under [LICENSE](LICENSE), except files explicitly
licensed otherwise, including the MIT Wi-Fi firmware and shared link library.
No DreamShell framework or
reader code is used as an input to this build. Selected original TPMJB artwork
from the earlier K-UI project is reused with the owner's authorization. This is source-aware
development, not a claim of a formal clean-room process.

| Input | Exact selection and use | License/notice |
| --- | --- | --- |
| KallistiOS | Official upstream `fcfa7d869471591ca1c777543261a7bfea7cb726`; kernel, hardware APIs, minifont and `arch_exec` execution trampoline | KOS BSD terms and per-file exceptions; [LICENSE.KOS](LICENSES/LICENSE.KOS), upstream `AUTHORS` and `doc/license/` |
| Original K-UI artwork | TPMJB's launcher badge and three original app icons, unchanged source images from `K-UI_DS` revision `2a5309298dde8fb100da1e2e4e10517695c9780f`; encoded as embedded RGB565 pixels | Owner-authorized reuse under this project's GPL-3.0-only; exact origins and hashes in [artwork record](resources/branding/README.md) |
| DejaVu Sans / Sans Bold | Unmodified font files and a generated ASCII raster atlas for the independent shell; no font engine linked at runtime | [Bitstream Vera/DejaVu license](LICENSES/DejaVu-fonts.txt); [source hashes and generation](resources/fonts/README.md) |
| Bus activation helper | `src/dreamcast/drive_bus.c` adapts the activation portion of upstream KOS `cdrom_init` at that pin | Original KOS copyright holders and BSD terms retained in the file |
| Resident probe SD reader | `src/loader/sd_reader.c` adapts the SCIF pin sequence and SD/CSD protocol from upstream KOS `hardware/scif-spi.c`, `hardware/sd.c`, and TMU register definitions from `kernel/timer.c`, all at the same pin; a separate read-only implementation owns its state and timer after kernel shutdown | Original per-file copyright holders and [KOS BSD terms](LICENSES/LICENSE.KOS) retained; no DreamShell source input |
| stb_vorbis 1.22 | `stb_vorbis.c` with documented short-read guards from `nothings/stb` commit `2c980bb59875b0d32144a71867fbdebb2f77cd20`; bounded, RAM-only Vorbis decoding in the Music app | Upstream alternative A, [MIT notice](LICENSES/stb_vorbis.txt); upstream/local hashes and adaptations in `dependencies.json` |
| stb_image 2.30 | `stb_image.h` with a documented zero-length read guard, from the same `nothings/stb` commit; PNG and JPEG box art that the owner places in `KUI/covers` | Upstream alternative A, [MIT notice](LICENSES/stb_image.txt); upstream/local hashes and adaptation in `dependencies.json` |
| lwext4 | Pinned `include/` and `src/` from `gkostka/lwext4` commit `58bcf89a121b72d4fb66334f1693d3b30e4cb9c5`; read-only CD bootstrap with documented checksum/bounds and read-only fixes; upstream/local per-file SHA-256 pins in `dependencies.json` | BSD-3-Clause and GPL-2.0-or-later per file; upstream [notice](LICENSES/lwext4.txt), all file headers retained in `third_party/lwext4` |
| FatFs | ChaN R0.16, official patches 1 and 2; SHA-256-pinned downloads, original license and patched source retained | [FatFs notice](LICENSES/LICENSE.FatFs) |
| K-UI Wi-Fi link library | This project's own `firmware/kui-wifi/components/kwlink` (`kwlink.c`, `kwhost.c`): the Dreamcast's side of the Wi-Fi board's link, shared with the board's firmware | MIT rather than GPL-3.0-only, so the firmware, which links Espressif's closed-source Wi-Fi libraries, can use it too; [notice](LICENSES/kui-wifi-kwlink.txt) |
| Known-dump catalogues (`data/known-dumps/`) | Track names, sizes and CRC32s only, no game or disc data. `redump.db` is adapted from the Libretro database's Redump Dreamcast DAT (CC BY-SA 4.0, share-alike; this file stays under that licence); `tosec.db` is a factual index of TOSEC's 2025-03-13 DAT pack | [Sources and licences](LICENSES/known-dumps-README.txt) |
| GCC/Binutils/Newlib | KOS stable profile at the pinned KOS revision | Component licenses; GCC runtime exception and Newlib component notices apply to runtime code |
| mkdcdisc | Canonical Simulant GitLab repository `4d74e40dd2122e14389a305ed1d86dd024201389`; separate host image-writing tool | MIT for its own code, with separate third-party components; upstream `THIRD-PARTY-NOTICES.md` |
| IP.BIN in the CDI | mkdcdisc MIL-CD template, including the LiENUS homebrew bootstrap | See the upstream IP.BIN provenance below; no DreamShell bootloader |
| Linux test/build utilities | Distribution `mkfs`, `fsck`, Meson, Ninja, libisofs and mtools | Host tools only; not linked into the Dreamcast executable |
| KiCad 7 libraries (CF board) | Symbols and footprints used by `hardware/cf-board`; `cf-board.pretty/CF-Card_3M_N7E50-E516xx-30_SmallRing.kicad_mod` is KiCad's `CF-Card_3M_N7E50-E516xx-30` with its board-lock rings cut from 3.99 to 3.2 mm | CC-BY-SA 4.0 with the KiCad libraries' exception for designs that use them; the adapted footprint file stays under CC-BY-SA 4.0 |
| iceGDROM riser board (reference) | Only the signal on each pin of the Dreamcast's GD-ROM connector, taken from `zeldin/iceGDROM` `pcb/riser`; no files copied | GPL-3.0 upstream; facts only |
| KiCad, Freerouting, kiutils | Host tools that draw, route and check the CF board (`hardware/cf-board/tools/build.sh`) | Host tools only; nothing from them is in the board files beyond their output |

The Wi-Fi board's firmware ([firmware/kui-wifi](firmware/kui-wifi/README.md))
is a separate program for the ESP32-C5 under its own MIT licence. It is built
with Espressif's ESP-IDF, including its closed-source Wi-Fi libraries, by its
own workflow, and is not part of the Dreamcast builds. Its host tests, and
K-UI's (`tests/wifi_model.c`), run its bridge core on the build computer only.

Source URLs and downloaded-file hashes are in [dependencies.json](dependencies.json).
The build artifact includes applicable KOS and FatFs license texts and source
records. Build-host package versions may change within Ubuntu 24.04; pinned
source inputs do not mean the entire compiler/image build is bit-for-bit
reproducible. `build.json` records the actual compiler and revisions, and
`SHA256SUMS` identifies the produced files.

## Bootstrap provenance

The image packager's [upstream notice](https://gitlab.com/simulant/mkdcdisc/-/blob/4d74e40dd2122e14389a305ed1d86dd024201389/THIRD-PARTY-NOTICES.md)
distinguishes the LiENUS replacement bootstrap from fixed Sega license-screen
code that the retail BIOS expects. Its interoperability rationale is an upstream
explanation, not blanket legal clearance from this project. The diagnostic uses
the MIL-CD template, disables the optional MR artwork, and does not distribute a
Sega BIOS image or a commercial game's extracted bootstrap.

The packager also contains libisofs, libedc, an ELF parser, a scramble routine and
makeip-derived code under their respective notices. They run on the build host;
their object code is not linked into K-UI. We retain the packager's notice so its
status is not reduced to its top-level MIT label.

## Independent references

The BSD `sega-dreamcast/httpd-ack` project informed the earlier feasibility
research and the declared GDI gap/address convention. No code from it is copied
into this implementation. The SHA-256/CD EDC routines are new implementations
of published algorithms; see [the capture format](docs/capture-format.md).
Games box art is also new code. The `.PVR` texture reader
(`src/core/pvr_texture.c`) follows the file layout, layout codes and Morton
(twiddled) texel order documented by KallistiOS's own texture tool at the
pinned commit (`utils/pvrtex/file_pvr.c`, `utils/pvrtex/pvr_texture.c`); no
code is copied from it. `0GDTEX.PVR` is found with the existing independent
ISO9660 reader. No DreamShell code, cover scanner or decoder is used. The command
adapter uses KOS's documented firmware structures and status values. It does
not patch or call the KOS CD-ROM command wrappers.

FatFs source changes consist of the two official patches. `config/ffconf.h` is
new project configuration; the block-device adapter and storage probe are new
project code. A source inventory must be revisited when any new dependency,
font, bootstrap, catalog or runtime component is added.

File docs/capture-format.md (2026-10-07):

# Capture format and invariants

Profile: `gdi-raw2352-typegap150-v1`. This is a declared logical GDI capture
profile, not a subchannel or forensic image of every physical region.

## Track plan

The planner accepts both density TOCs, consecutive track numbers starting at 1,
low-density start FAD 150, high-density first data track at FAD 45150, and
control values 0 (audio) / 4 (data). Other layouts fail before output creation.
All address ranges are half-open: `[start_fad, end_fad)`. GDI starts subtract
150 once. Raw files are `(end_fad - start_fad) * 2352` bytes; any individual file
above the FAT32 limit is refused even on exFAT.

For an intra-session change between data and audio, exclude the 150 sectors
immediately preceding the next TOC start. Same-type boundaries and each session
leadout use the full TOC range. The manifest retains `toc_end_fad` and
`excluded_tail_sectors`, making those exclusions explicit. The space between
the low-density leadout and high-density start is outside both session ranges.

This convention was checked against the independent BSD `httpd-ack` track/GDI
writer at [the pinned reference](https://github.com/sega-dreamcast/httpd-ack/blob/f5891519a01902d50b675ff38660ac87108de293/src/httpd-ack.c).
No source code is copied from that project. It is evidence of an established
GDI convention, not proof that every GD-ROM pregap matches it. Physical complete
captures and reference comparisons remain the acceptance gate.

## Reads and identity

Read at most 32 raw sectors (75,264 bytes) per PIO command. Firmware-visible
buffers and parameters have static lifetime. Capture reads each range once;
identification uses two reads with different fills and compares the payload.
Both paths inspect the guards and unused tail. Failed aborts and guard corruption
poison further drive access.
Sense 2/6 stops capture and requires a fresh prepare/identity check on resume.

Each data sector also passes its Mode 1 or Mode 2 Form 1 EDC check. This detects
errors; it does not repair ECC or validate independent reference content.
Audio bytes are preserved as returned by the drive, without byte swapping,
offset correction or subchannels. Repeat equality is not an audio reference.

The disc fingerprint is SHA-256 over the profile name, canonical track plan and
three raw content samples per track (start, midpoint, end-1). It includes the
high-density boot metadata, whose Dreamcast signature is required. Full hashes
are still necessary to establish whole-disc identity against a reference.
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

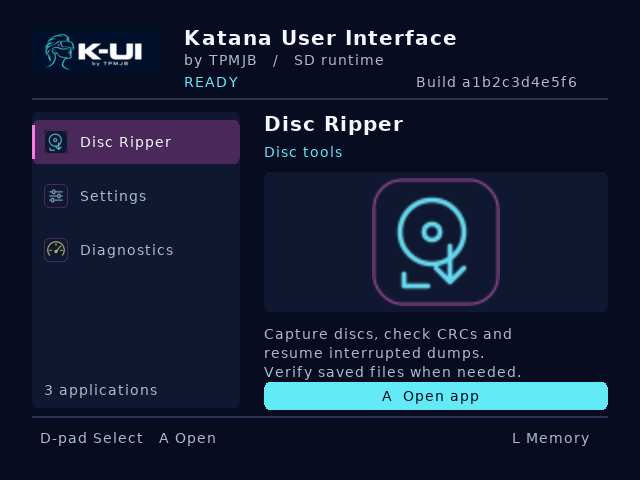
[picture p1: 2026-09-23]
docs/screenshots/m15-launcher.png

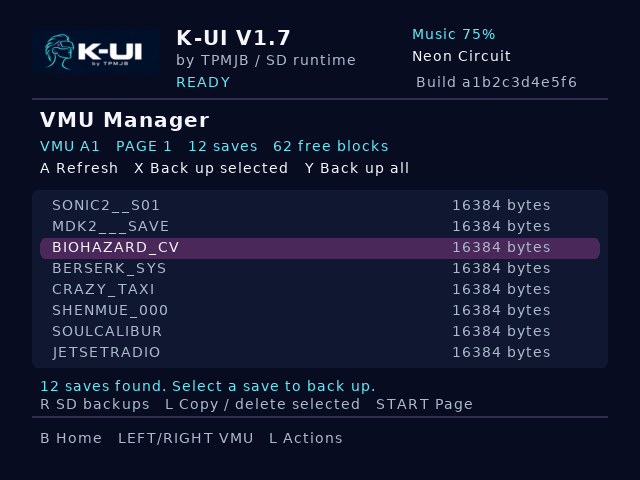
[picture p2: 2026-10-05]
resources/release-v1.7/vmu.png

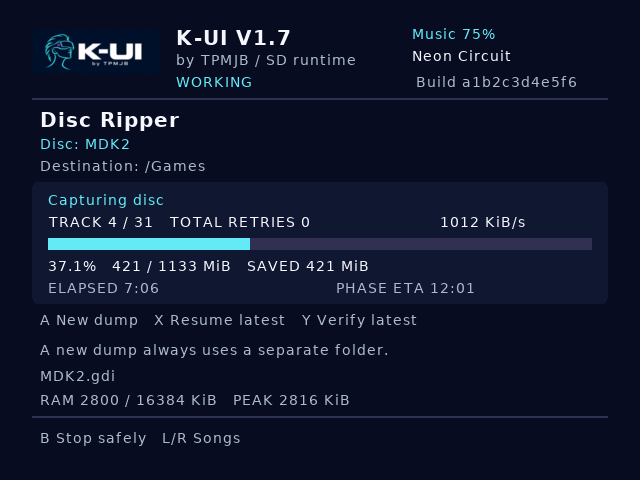
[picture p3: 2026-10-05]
resources/release-v1.7/ripper.png

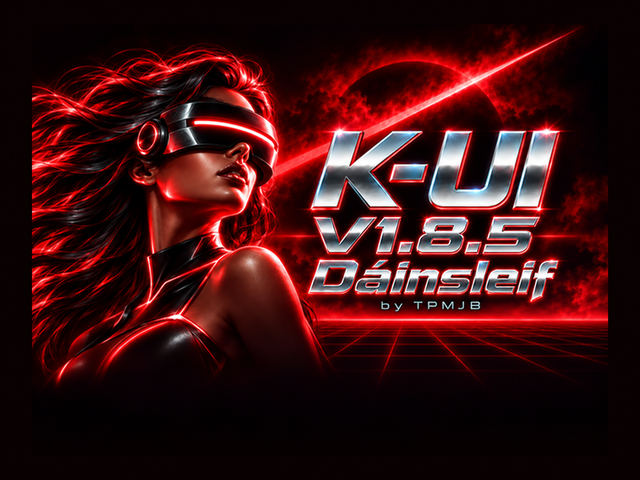
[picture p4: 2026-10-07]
resources/branding/boot-red.png

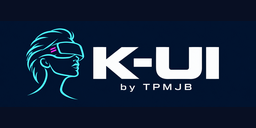
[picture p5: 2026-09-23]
resources/branding/launcher-brand.png

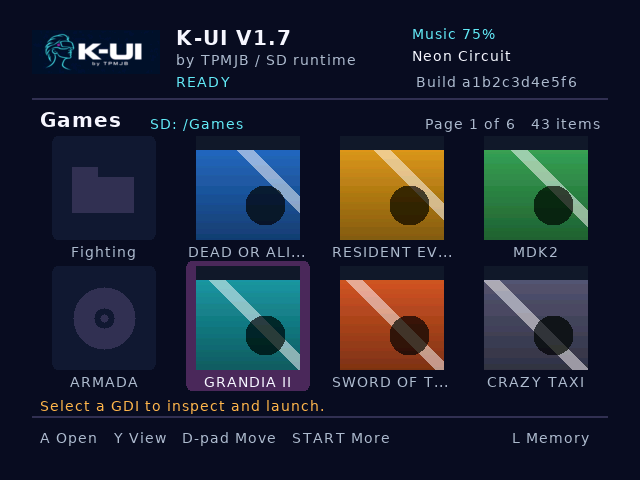
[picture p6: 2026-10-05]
resources/release-v1.7/games-gallery.png

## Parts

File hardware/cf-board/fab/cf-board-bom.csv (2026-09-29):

References | Quantity | Value | Footprint | Description | Suggested part
C1 | 1 | 10u | Capacitor_SMD:C_0805_2012Metric_Pad1.18x1.45mm_HandSolder | 10 uF 16 V X5R, 0805 | 10 uF 16 V X5R 0805
C2 C3 | 2 | 100n | Capacitor_SMD:C_0805_2012Metric_Pad1.18x1.45mm_HandSolder | 100 nF X7R, 0805 | 100 nF 50 V X7R 0805
D1 | 1 | ACT | LED_SMD:LED_0805_2012Metric_Pad1.15x1.40mm_HandSolder | Activity LED, green, 0805 | green LED 0805 (about 2 V at 2 mA)
H1 H2 | 2 | M2 | MountingHole:MountingHole_2.2mm_M2 | Mounting hole | nothing, or a nylon M2 screw
J1 | 1 | CF socket | cf-board:CF-Card_3M_N7E50-E516xx-30_SmallRing | CompactFlash header, Type I, SMT, 3M N7E50-E516PG-30 | 3M N7E50-E516PG-30
J2 | 1 | To CN503 | Connector_PinHeader_2.00mm:PinHeader_2x21_P2.00mm_Vertical | Wire pads, 2.0 mm grid (fit nothing, or a 2 x 21 2.0 mm header) | nothing (wires), or a 2 x 21 2.0 mm pin header
JP1 | 1 | 3V3/5V | Jumper:SolderJumper-3_P1.3mm_Bridged12_RoundedPad1.0x1.5mm | Card supply: 3.3 V as made (cut the trace and bridge 2-3 for 5 V) | nothing: solder jumper on the board
JP2 | 1 | CSEL | Jumper:SolderJumper-2_P1.3mm_Open_RoundedPad1.0x1.5mm | Open: slave (as needed in the Dreamcast); bridged: master | nothing: solder jumper on the board
R1 | 1 | 470 | Resistor_SMD:R_0805_2012Metric_Pad1.20x1.40mm_HandSolder | Activity LED resistor, 0805 | 470 ohm 1% 0805
R2 | 1 | 10k | Resistor_SMD:R_0805_2012Metric_Pad1.20x1.40mm_HandSolder | PDIAG pull-up, 0805 | 10 kohm 1% 0805

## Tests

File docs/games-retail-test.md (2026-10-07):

# DOA2 launch — historical SD latency comparison

This guide records earlier loader development. For release 1.8.5 controls,
compatibility and installation use the [release guide](release-v1.8.5.md)
and [current Games formats](games-formats.md). The native reader placement
is now below the IP image; see [hardware evidence](evidence/native-low-resident-2026-10-06.md).

**Historical release: 1.5.1, faster launches.** Track maps from the allocation
table, no executable pre-read, half-second handoff screens, silent CD-audio
commands and A+B+X+Y+Start restarting K-UI. The owner reports DOA2 launch is
"near instant now" and the restart works; see
[the launch-speed test](games-launch-speed.md).

**Historical playable baseline: `2072b489c378`**, pinned at
`baseline/doa2-pacing-2072b489c378` and on `main`: longer reads while the
picture is static, all-CMD18 streams and a counter screen on A+B+X+Y+Start.
The owner reports it worked really well; the first ten seconds of a fight
remain laggy. See [the pacing test](games-read-pacing.md) and
[the pin record](evidence/games-doa2-pacing-baseline-2026-09-26.md). The
earlier baselines below stay pinned for comparison.

**Previous playable baseline: `ed31d522c847`.** The owner reports the integrated
CMD18 build substantially better and really playable. Character selection to
the first stage took about 32 seconds; slowdown remained during the first
roughly eight seconds of battle and ten seconds of an FMV.

The exact package is pinned at `baseline/doa2-cmd18-ed31d522c847`; source,
archive hash and both transport/gameplay observations are in the
[CMD18 evidence record](evidence/games-cmd18-comparison-2026-09-24.md).
Keep these SD files installed. Games optimization is paused while the
[boot CD is refreshed](bootloader-refresh.md); no further comparison is
requested now. The following implementation notes describe this tested build.

The tested build uses bounded 8–10 physical-block CMD18 streams and CMD17 for
shorter tails. The two-game-sector EXEC limit is unchanged. Every image read
closes its stream before restoring the pins and returning to the game. It also
removes the resident's duplicate manifest decode and card initialization by
copying the stage's validated state and rebinding all callbacks locally.
The historical gameplay timings below describe the preserved working build.

**Earlier pinned working build: `6c02bd8b22f4`.** The owner reports fluid audio and
playable results, with delayed textures, stage loads and brief early-battle lag
still present. Exact rollback branch, archive checksum and timing intervals are
in [the pinned baseline record](evidence/games-doa2-pinned-baseline-2026-09-24.md).
Keep this build unchanged for future comparisons. The candidate discussion
below records how this now-tested build differed from its predecessor.

The selected-image GD probe has already passed on hardware: build
`c4cfd4585ec5`, DEAD OR ALIVE 2, all 11 checks, 93 physical SD blocks after
launcher shutdown. Do not repeat that probe for this test.

**Previous working baseline:** build `3ebbf8f9846b` was substantially better by
owner report: about 15 seconds to game startup, then about 10 seconds before
Start works on the initial screen (previously roughly three minutes).
Gameplay has minimal lag. Stage-start loads, FMVs and speech during loading
still suffer. These are approximate owner timings, not measured throughput.
Save/load through the physical VMU and broader compatibility remain open.
See [the hardware result and next change](evidence/games-doa2-fast-io-2026-09-24.md).
Keep this package as the working baseline.

## Tested SD latency change

The candidate reduces each EXEC call from eight to two game sectors, retaining
the existing physical-block cache across calls and avoiding the redundant
whole-destination cache purge at request submission. Per-chunk cache coherence,
CRC checking and the caller's interrupt-state restoration remain in place.
No extra buffer, compression, asynchronous DMA or prefetch is introduced.

Use the same card, dump and boot CD. Compare the opening movie and the same
stage introduction with character speech, then play a fight. Report whether
speech improves, whether loading gets longer, and whether gameplay stays smooth.
The smaller chunk is a latency experiment: infrequent game polling could reduce
throughput. Retain `3ebbf8f9846b` for rollback. One comparison run is sufficient;
no rerip or accepted-probe repeat is needed.

## Previous SD performance change (now tested on hardware)

Build `3ebbf8f9846b` changed CPU work in the existing synchronous read path:

- Dedicated receive-only SPI loop for normal-speed `0xff` transfers, with
  precomputed pin values and no transmit shifts or slow-delay branch per bit.
- Algebraic CRC16 byte update instead of eight polynomial iterations; card
  data CRC verification remains enabled, including rejection of corrupt data.
- Aligned 32-bit integer copies with byte fallback/tails, without borrowing
  game FPU or store-queue state.

That build retained eight-sector execution chunks and the diagnostic pauses,
without adding compression, asynchronous DMA or prefetch. The shared
CRC/copy changes are enabled only for retail stage/resident builds, leaving
the accepted standalone probes on their original implementation.

Focused validation is `ASAN_OPTIONS=detect_leaks=0 make test-retail-fast-io`:
SD pin edges/work accounting, protocol/CRC fixtures (including corrupt data),
and copy alignment/tails/canaries. These passed locally with address/undefined
behavior sanitizers. Native size, stack and instruction checks still run as
part of the console build. The owner subsequently confirmed the improvement
reported above.

The preceding first-gameplay baseline was `7fd48f11be02`; its original evidence
is retained in [the first gameplay record](evidence/games-doa2-gameplay-2026-09-24.md).

The first retail build `d19f1e0ebaf3` reached the independent loading screen
after an approximately four-minute wait, flashed more text, then returned to
the stock Dreamcast menu. This correction remains an **experimental retail
launch** with the limited hardware result above. It only offers launch for the native GD-ROM
`DEAD OR ALIVE 2` / `1ST_READ.BIN` profile. A different region or revision
may still need work. The product number in a synthetic test fixture is not
used as a hardware identification or compatibility claim.

Builds `255e63f79d8d` and `f26d1a883109` returned to the menu from
`0x8c012450` with zero recorded GD calls. The owner then supplied the exact
startup files: DOA2 `T3601N`, `V1.100`, region `U`. Its startup fills
`0x8c00c000..0x8c00f3ff`, overwriting our old reader-stack guard. The assembly
hook rejected calls before the C counters could increment. This correction
moves the entire reader stack below that range and reports the guard on a
menu return. See `evidence/games-retail-startup-return-2026-09-24.md`.

Build `289e10a1ab20` passed that startup guard and reached the reader, stopping
on unsupported command `0x28` (GET_VERS). The current correction implements
its bounded 28-byte compatibility response. DOA2's next visible startup step
is a one-sector ISO volume-descriptor read through the existing read commands.
Evidence: `evidence/games-retail-version-query-2026-09-24.md`.

## Install and test

1. Power off. Extract this build's `sd-update` archive onto the existing SD
   card, merging its `KUI` directory. Keep the existing boot CD and game dump.
2. Boot K-UI and open **Games**, then inspect the same DOA2 GDI.
3. Press **Y — Launch (experimental)**. On its confirmation screen press
   **A — Launch**. The existing **A — Test image reads** action on image
   details is the previously accepted probe, not this launch.
4. The loading screen now has a progress bar. Handoff screens stay up for
   about half a second. Photograph the last screen, including its
   build ID and error details. Unsupported reader operations stop on a
   diagnostic screen. If the game starts, report the furthest point reached: title,
   menu, or an actual fight, and whether controller input works.
5. A+B+X+Y+Start (the game's return-to-menu request) shows the reader's
   counters for about two seconds, then restarts the console, which boots
   the K-UI disc again. Otherwise power off/on to return to K-UI.

Preparation reads the IP and boot executable to record their checksums;
the independent loader checks those bytes again after K-UI shuts down.
Preparation keeps the track file open across sequential reads; it previously
reopened and retraversed its allocation chain for each sector. The detached
stage now enables CPU caches before SD transfers and CRC work. Neither change
is a measured hardware speed claim; the new console run establishes timing.
This is not a new disc capture or full-image verification. The loader never
writes the SD card or modifies the stored game files.

## What the experiment does

The temporary stage loads the owner's complete 32 KiB IP and native linear
boot executable. After checking both CRCs it clears the native Katana IP
flag at offset `0xfc`, bit `0x20`, matching the observed DreamShell setup,
and installs the resident before entering the owner's bootstrap 2 at
`0xac00e000`. It explicitly sets SP/VBR `0x8c00f400`, GBR `0x8c000000`,
SR/SSR `0x700000f0`, FPSCR `0x00040001` and CCR `0x00000909`. The precise
meaning of the IP flag is not established by the inspected source.
A temporary 128-byte executable-entry trampoline captures the resulting
integer CPU state, confirms the resident code remains intact, then restores
the original entry bytes and resumes the owner's `0xac010000` uncached alias
before the first original game instruction. The loader does not bundle proprietary bootstrap
code or apply compatibility patches to the executable.

The final reader must fit below `0x8c00bb00`, starting at `0x8c008300`.
Its guarded 1,280-byte stack occupies `0x8c00bb00..0x8c00c000`; the native
build rejects code/BSS overlap or a conservative stack bound over 1,232 bytes.
The owner executable's startup stack fill begins at `0x8c00c000`. Firmware low RAM, IP metadata/TOC, the upper bootstrap
and conventional VBR/stack, and executable RAM beginning at `0x8c010000`
are kept outside that reservation. The temporary high stage is no longer
needed once the game starts. A different stack/VBR arrangement is rejected.
This placement is an experiment for the selected game, not a general SDK
memory-reservation guarantee.

GD reads use the independent, read-only serial-SD backend with finite work
budgets and scoped ownership of the serial pins. The backend does not borrow
a game timer. The temporary stage first retires the UART/FIFO state left by
K-UI's shutdown; subsequent game-time reads preserve serial controls and
refuse to take over active serial I/O. Requests complete through explicit polling in bounded chunks;
command 17 still copies through the CPU. Hardware DMA interrupts, streaming,
image CDDA, Windows CE, IDE/CF, and broad game compatibility are not implemented.
The first game call requiring an unsupported operation therefore stops on
a diagnostic with the request and SD state. CD-audio PLAY/PAUSE/RELEASE
commands are accepted without sound. The standard BIOS-menu vector is
intercepted for return command 1: it shows the caller address, last GD
request and read counters, then restarts through the boot ROM. A direct jump
to ROM or a hardware reset bypasses that screen.

GD routing covers the BC supervisor vector, the C0 raw GD vector and both
direct firmware RAM entries (`0x8c001000`, `0x8c0010f0`). BC miscellaneous
setup/registration calls return zero while retaining the independent reader;
C0 ignores incoming R6 and dispatches by R7. Original GD forwarding is removed
to avoid recursion through those patched entries. A menu-return screen reports
counts for all four routes, the hook guard fault flag and current guard word.
A healthy guard is `4B554947` and its fault flag is zero. Exact evidence and
ABI comparison: `evidence/games-retail-gd-routing-2026-09-24.md`.

## Independent interface references

- Marcus Comstedt, [IP.BIN layout](https://mc.pp.se/dc/ip.bin.html) and
  [system calls](https://mc.pp.se/dc/syscalls.html): original bootstrap
  addresses, native GD executable layout, and firmware vectors.
- [KallistiOS, pinned commit fcfa7d869471591ca1c777543261a7bfea7cb726](https://github.com/KallistiOS/KallistiOS/tree/fcfa7d869471591ca1c777543261a7bfea7cb726):
  `kernel/arch/dreamcast/kernel/{startup.S,exec.c,execasm.s}`,
  `hardware/{syscalls.c,video.c}`, and `include/dc/pvr/pvr_regs.h` establish
  shutdown/cache and hardware interface details.
- GD status/mode interface details are additionally cross-checked against
  the independently developed redream source pinned in `retail_gd.c`.

The first build was implemented without reading the DreamShell ISO loader.
After the failed hardware attempt, the user explicitly requested comparison
with their existing DreamShell tree. Its bootstrap entry, CPU setup, cache
setup, syscall ordering and Katana IP flag were inspected for this correction.
See `evidence/games-retail-boot2-correction-2026-09-24.md` for exact source
files and hashes. The independent image reader and GD service remain in use. The accepted optical capture/drive/command files remain
unchanged. Host tests and binary layout checks cannot establish retail game
compatibility; this console run is the next evidence needed.

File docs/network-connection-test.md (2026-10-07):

# Ethernet connection test

Network retains its read-only adapter inspection and adds a temporary DHCP and
local-gateway test. It runs on the existing I/O worker and does not overlap a rip,
VMU write, storage test, or music-file load. It uses upstream KOS BBA/LAN drivers
and independently authored packet validation.

The connection test performs DHCP DISCOVER/OFFER/REQUEST/ACK, validates its
transaction ID and MAC address, checks the assigned address for an ARP conflict,
then requests the local gateway's MAC and sends an ICMP echo. It reports DHCP,
ARP and ICMP results separately. A router that filters ping may still be usable;
no response is reported as an unproven/failed ping, not as proof the adapter is
broken. A valid lease without an advertised gateway is displayed as such.
DNS server addresses are displayed, but DNS lookup and Internet access are not
tested. Dial-up modem support is not implemented.

This is a **temporary diagnostic session**, not a persistent networking service.
It never rewrites flash or saved addresses. It refuses to take over any running
interface, restores the previous packet-input callback, stops only the driver it
started, and unregisters only a device it registered. The acquired lease is not
retained by K-UI after the test; its server lease expires normally. A validated
static-address entry point exists for integration, but no inactive static editor
is exposed in the menu.

DHCP offer and ACK waits are individually limited to 15 seconds, ARP conflict
checking to 3 seconds, and gateway ARP/ICMP to 5 seconds each. B cancels between
protocol iterations. Pinned KOS's BBA startup has its own bounded 10-second link
wait, and LAN startup waits 4 seconds; cancellation takes effect after that
upstream call returns. The UI remains responsive throughout.

The engine rejects truncated/fragmented packets, wrong transactions, mismatched
hardware addresses, invalid IPv4/UDP/ICMP checksums, malformed DHCP options,
invalid masks, off-subnet gateways and address conflicts. DHCP option overload is
not implemented; such replies are ignored rather than interpreted incompletely.
The receive callback copies a bounded frame into a four-entry queue and leaves
all parsing to the worker. Queue drops are reported.

## W5500 on the SCI port

With no BBA or LAN adapter, inspection and the connection test look for a
W5500 wired to the SCI port. The same probe runs over the W5500's raw
Ethernet socket (socket 0 in MACRAW mode); the chip's own address stays
unset during the test. The W5500 also carries K-UI's FTP server; see
[the FTP server](ftp.md) for the wiring, the SPI speed checks and the tests.

## The Wi-Fi board on the SCI port

With no W5500 either, they look for K-UI's Wi-Fi board. It gets its own
address, so its test is different: it waits for the board to be online, then
looks up `pool.ntp.org` through it and reads the time the board set from the
internet; a successful lookup is the pass. See [Wi-Fi](wifi.md).

SCI storage reserves that port and blocks both W5500 and Wi-Fi probing. Keep
the storage card on SCIF for the first Wi-Fi test. The Wi-Fi hardware path has
not yet been validated on a console.

## Host and console checks

Host protocol tests cover DHCP success/NAK/deadlines, conflict detection, gateway
ARP/echo matching, every packet truncation boundary and malformed option lengths.
[Host evidence](evidence/m15-network-maintenance-host-2026-09-23.json) records these checks.
Lifecycle stubs cover preexisting interface refusal, callback/config preservation,
owned versus borrowed driver cleanup, cancellation and init/start/transmit errors.
TX storage is explicitly aligned to 32 bytes for the BBA driver. Neither driver
is polled from the test: BBA has its own RX worker and LAN an IRQ receiver.
They do not prove driver behavior on real hardware.

On a Dreamcast with BBA or LAN adapter, first run inspection, then the connection
test with a cable connected to a DHCP router. Save the report. Repeat with the
cable disconnected, and cancel one attempt. No full disc dump or new CD is
needed. If no Ethernet adapter is installed, the expected result is an explicit
no-adapter message. Hardware acceptance remains pending.

Primary implementation references:

- [Pinned KOS network interface](https://github.com/KallistiOS/KallistiOS/blob/fcfa7d869471591ca1c777543261a7bfea7cb726/include/kos/net.h)
- [Pinned KOS input callback](https://github.com/KallistiOS/KallistiOS/blob/fcfa7d869471591ca1c777543261a7bfea7cb726/kernel/net/net_input.c)
- [Pinned BBA driver](https://github.com/KallistiOS/KallistiOS/blob/fcfa7d869471591ca1c777543261a7bfea7cb726/kernel/arch/dreamcast/hardware/network/broadband_adapter.c)
- [Pinned LAN driver](https://github.com/KallistiOS/KallistiOS/blob/fcfa7d869471591ca1c777543261a7bfea7cb726/kernel/arch/dreamcast/hardware/network/lan_adapter.c)
- [DHCP RFC 2131](https://www.rfc-editor.org/rfc/rfc2131), [options RFC 2132](https://www.rfc-editor.org/rfc/rfc2132), [ARP RFC 826](https://www.rfc-editor.org/rfc/rfc826), [ICMP RFC 792](https://www.rfc-editor.org/rfc/rfc792)

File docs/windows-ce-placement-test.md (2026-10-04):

# Windows CE boot test

## Current release status — 1.7 (2026-10-04)

**1.7 retains the accepted 256-byte SCI token-search allowance from
`6f14bc529472`.** On the Windows CE confirmation, **X** selects the
background SCI reader and **A** the standard synchronous reader. The later
512-byte comparison was rejected after the owner's audio regression report;
no repeat comparison is pending. Windows CE remains experimental and
SCI-only, with title-specific FMV, audio and synchronization limits.

Use the [1.7 installation guide](release-v1.7.md),
[release notes](release-v1.7-notes.md) and
[baseline decision](evidence/v1.7-sci-baseline-2026-10-04.md) for current
operation. The dated experiments and next-step proposals below are retained
as implementation history; they do not request older comparison tests or
describe the selected release setting.

ARMADA and Worms Armageddon now boot and run from SCI microSD. FMV speed and
compatibility remain under test. The **Windows CE boot test** on a game's
detail screen provides the standard reader (A on confirmation) and the
background reader (X). The placement and bring-up results below are the
history of that implementation, not a statement that games still cannot run.

## What it needs

- `KUI/apps/games/ce-probe.kui` and `KUI/runtime.kui` from the same build.
- A raw GDI (2352-byte tracks) whose IP selects Windows CE, for example ARMADA.
- **SCI microSD.** Only the SCI reader is built CE-safe (below); preparation
  refuses other storage.

## How to run it

1. Games, select the CE game, A to inspect it.
2. The detail screen says `A Windows CE boot test`. Press A.
3. Press A for the standard reader, or X for the background reader. The
   experimental confirmation warning remains; compatibility is title-specific.
4. The launcher closes. The stage loads IP.BIN, then the kernel file
   (`0WINCEOS.BIN`), checking every sector's header and every SD block's CRC.
5. Play the selected title. On a fault, photograph the stop screen and power
   cycle. A+B+X+Y+Start can show the menu-return counters. A standard-reader
   comparison is optional for troubleshooting.

## Historical CE prefetch experiment (2026-10-04)

**Comparison at this stage: first-overrun fallback.** Recovery build
`68cbe37aa95e` boots with the live overlay hidden. The owner reports steady
FMV progression with persistent echo/repetition-like audio and no clear
improvement. Its whole-session report showed 5,891 overruns, 6,188 stream
starts and 2,925 polled blocks. Roughly two overruns per polled block is
consistent with the existing retry threshold; it does not establish the
cause of the audio symptom. The full counters and interpretation are in
[the handoff](HANDOFF.md#windows-ce-first-overrun-fallback-experiment-2026-10-04).

The next experiment at this stage changed only the CE background reader: after an
unrecovered overrun, reread that block by polled transfers immediately,
then return to DMA for following blocks. Other failure thresholds, the
retry limit, CRC, in-place repair safeguards and interrupt iteration bound
remain unchanged. Cold boot and use X on the same title; play the same
intro segment for the same duration, then photograph the return counters.
Compare pacing/audio and overruns/starts per completed card block. There
is no live rate overlay and no measured improvement for this change yet.

Earlier full overlay removal (`b3d9ee49f9b7`) stopped at bootstrap 2.
`68cbe37aa95e` restored the last working timer/accounting and display paths,
suppressing only status drawing while MMUCR.AT is set (CE active). Boot,
failure and menu-return screens remain. That guard is retained here.

The background reader now has a 2 KiB ring of CRC-checked output instead of
a single 512-byte spill. It can read ahead within the current request while
CE supplies the next DMA destination, and while a virtual PIO destination
cannot be accessed from the interrupt. Physical destinations still take a
direct copy when no older queued bytes remain. Virtual destinations are
copied only inside CE's GD calls, in the caller's address space.

Data arriving in the queue is not completion: a request or transfer finishes
only once its bytes reach the guest destination. Abort/reset discards queued
output. A terminal PIO-stream prefetch error reports failure and wakes CE,
even before its next transfer is submitted; it does not invent a transfer
callback. CRC checks, the resident memory limit and its 2 KiB stack are retained.
Each CE interrupt delivery visit takes at most two delivery-loop iterations,
including retries; this bounds block work, not the elapsed time of existing
token-polling loops.
Native game readers and the standard CE reader retain their existing paths.

The menu-return screen replaces the hook-count row with:

| Field | Meaning (hexadecimal) |
| --- | --- |
| `ISR` | 1 when CE's SCI handlers are installed |
| `Q PEAK` | Most queued bytes; capacity is `00000800` (2,048 bytes) |
| `Q BYTES` | Total checked bytes staged in the queue since launch |
| `Q FULL` | Service visits unable to admit another 512-byte block; a count, not time |
| `Q LEFT` | Bytes still queued when the report is captured |

`IRQ BLKS` and `CALLBLKS` count card blocks processed in those contexts;
prefetched IRQ blocks need not already have reached CE's destination.

Original prefetch comparison: replay ARMADA's same intro with X and compare with
the previous background build's roughly 470 KiB/s, including playback and
audio smoothness. A still supplies the standard-reader comparison. Then try
Worms' PIO intro. Capture the rate/busy display and menu-return screen if
possible. A queue peak above `00000200` proves use beyond the old spill;
it does not by itself establish a speed gain. Hardware performance remains
unmeasured when that change was built. Build `90b0456391fe` kept the live
display, so that first experiment did not change its drawing overhead; the
current comparison suppresses its MMU-on redraw as described above.

## Step 1: placement (passed on ARMADA)

## What it does

The kernel file is a 2048-byte load prefix followed by the kernel body. The
prefix's header (one load section: address, file offset, length, entry) says
where the body goes. Following Flycast's independent BIOS (see the
[loader audit](evidence/windows-ce-loader-audit-2026-10-01.md)), the prefix
goes to `0x8ce01000` and the body to `0x8c010000`.

The native stage occupies `0x8ce00000`, which covers the prefix's place, so
this test has its own package, `ce-probe.kui`, whose stage is linked 64 KiB
higher, at `0x8ce10000`. Its header carries the magic `KUIRCE01`; the launcher
refuses to mix it up with `retail-boot.kui`, and each stage checks the IP's
Windows CE flag itself.

The stage then:

1. Reads the prefix sector and builds the load plan
   (`src/core/ce_load_plan.c`) against everything still in use: firmware, IP
   and bootstrap area (`0x8c000000`–`0x8c010000`) and the stage with its stack
   (`0x8ce10000`–`0x8cff0000`). A rejected plan stops with `CE LOAD PLAN
   REJECTED`, its result code and the header fields.
2. Loads the body to `0x8c010000` and copies the prefix to `0x8ce01000`.
3. Shows the checksums, placement, the kernel's ROM header if it has one, and
   the IP's boot bytes.

## The result screen

| Line | Meaning |
| --- | --- |
| `PREFIX CRC32` | CRC32 of the 2048-byte prefix, read back from `0x8ce01000` |
| `BODY CRC32` | CRC32 of the body bytes in place at `0x8c010000` |
| `PREFIX AT` | Where the prefix was put |
| `BODY AT / BYTES / SECTORS / ENTRY` | The body's place, length, sectors read and the entry address |
| `ROMHDR / PHYSFRST / PHYSLAST / RAMSTART / RAMEND` | The CE ROM header found through `ECEC` at body offset 0x40: the kernel image's span and the RAM CE will use |
| `NO CE ROM HEADER AT BODY OFFSET 40` | Shown instead when the body has no such header (Worms Armageddon) |
| `IP F0 / F4 / F8 / FC` | Four words of the IP at 0xF0–0xFF, the boot information the next step needs |
| `STORAGE BLOCKS READ` | SD blocks read by the stage |
| `PLACEMENT CHECKED - CE WAS NOT STARTED` | The test finished |

Expected values, from the kernel files the owner supplied:

| Game | Prefix CRC32 | Body CRC32 | Bytes | Sectors | ROM header | Physlast | RAM start | RAM end |
| --- | --- | --- | --- | --- | --- | --- | --- | --- |
| ARMADA | `6200729C` | `B9F755BC` | `00131800` | `00000263` | `8C141420` | `8C141778` | `8C142000` | `8CFD0000` |
| Bust-A-Move 4 | `70513A3C` | `F6902800` | `001BE800` | `0000037D` | `8C1CE19C` | `8C1CE5B4` | `8C1CF000` | `8CFD0000` |
| Worms Armageddon | `EFFD7677` | `CD686951` | `0010E800` | `0000021D` | none | | | |

All three have body and entry at `8C010000`, and physfirst `8C010000` where a
ROM header exists.

## Console result: ARMADA, build 79f065b4ea88 (2026-10-03)

Passed on the owner's console over SCI microSD. Every value matched the
table above: prefix `6200729C`, body `B9F755BC`, prefix at `8CE01000`, body at
`8C010000` (`00131800` bytes, `00000263` sectors, entry `8C010000`), ROM header
`8C141420` with physfirst `8C010000`, physlast `8C141778`, RAM `8C142000` to
`8CFD0000`. `STORAGE BLOCKS READ 00000B45` (2885: 74 for the IP, 2811 for
the file's 612 raw sectors). The IP words at 0xF0–0xFF read `20202020`: that
range is the end of the IP's 128-byte title field (0x80–0xFF), padding spaces,
not boot information.

Found while planning the next step: ARMADA's CD driver (`wsegacd.dll`) calls
the BIOS GD entry `0x8c0010f0` directly, after `SetKMode(1)`, rather than
through the `0x8c0000bc` vector. The resident already redirects that entry
(and `0x8c001000`) to itself, so those calls reach K-UI.

## What it tells us

- That the prefix/body split, the higher stage and the sector checks work on
  the console with a real CE disc image.
- The RAM CE will claim. ARMADA's kernel uses `0x8c142000`–`0x8cfd0000` plus
  its driver globals up to `0x8d000000`, which covers the CE stage. The stage
  must therefore hand over before CE's kernel starts, and keep nothing there
  afterwards. The low resident (`0x8c008300`) sits below the kernel image;
  whether CE leaves it alone is the next step's question.

## Step 2: the boot test

After placement the stage carries on as for a native game:

1. It puts the relay's trampoline at the body start (`0x8c010000`), installs
   the CE-safe SCI reader in the low IP area, clears IP byte `0xFC` bit
   `0x20` exactly as native launches do, and enters the IP's bootstrap 2.
   Only the trampoline's first 64 bytes (all of its code) are placed, so the
   body keeps its `ECEC` signature and ROM header pointer at offset `0x40`
   while bootstrap 2 runs.
2. Bootstrap 2 runs under a K-UI exception table with SR.BL clear, which
   otherwise matches the native entry (SR.BL set): any exception, which would
   have reset the console, stops with `EXCEPTION WHILE BOOTSTRAP 2 RAN`, its
   vector, EXPEVT, TEA, SPC, SSR, R15, PR and the code at SPC; an interrupt
   (only if bootstrap 2 lowers IMASK) is left pending, as SR.BL would have
   left it, without changing any of bootstrap 2's registers.
3. Bootstrap 2 jumps to the body start and reaches the relay, which restores
   the boot VBR and SR.BL, checks the boot stack and CPU state, restores the
   body's first 64 bytes, checks the body's CRC32 and the reader's bytes,
   shows `ENTERING WINDOWS CE` (held two seconds, as is the screen before
   bootstrap 2) and jumps to `0x8c010000`.
4. Windows CE starts. Its CD driver calls the BIOS GD entry `0x8c0010f0`
   directly; the reader has redirected that entry (and the others) to itself.

The CE-safe reader (`KUI_RETAIL_CE`, built only into `ce-probe.kui`):

- **Stack:** CE calls with its MMU on and its stack at a virtual address. A
  TLB miss while exceptions are blocked (SR.BL) resets the console, so this
  reader writes and reads the caller's stack only with the caller's own SR:
  it masks after saving registers and unmasks before restoring them. Its
  private stack and all its data are physical addresses.
- **Addresses:** every buffer and parameter address goes through the existing
  check, which refuses anything that is not main RAM (`0x0c`/`0x8c`/`0xac`)
  without touching it. A CE virtual address therefore makes a request fail
  cleanly instead of crashing.
- **Reads:** a fixed step per EXEC, and a step on each CHECK while a read is
  pending (CE's driver polls CHECK between short sleeps). No pacing.
- **Trace:** it records the last four calls and, when one fails, stops with:

| Line | Meaning |
| --- | --- |
| reason | `GD REQUEST REJECTED`, `GD FUNCTION UNSUPPORTED` or `IMAGE READ FAILED` |
| `CALLER / STACK / SR / MMUCR / VBR` | CE's return address (PR), its stack, its SR at the call, the MMU control register and CE's vector base |
| `R7 / R4 / R5 / R6 / CALLS` | The failing call: function, first and second arguments, R6, and how many calls came before |
| `EARLIER` (three rows) | The three calls before it, newest first, as R7 R4 R5 R6 |

## Console result: first boot test, build 64f30e3f8ce4 (2026-10-03)

ARMADA reached `ENTERING OWNER BOOTSTRAP 2`, then the console reset to the
BIOS. That build entered bootstrap 2 with SR.BL set (as for native games), so
any exception there resets the console. Two differences from native launches
were found and removed in the next build:

- It left IP byte `0xFC` unchanged. Native launches clear its bit `0x20`
  before entering bootstrap 2, which skips bootstrap 1; every working launch
  has had it cleared.
- Its 128-byte trampoline covered body offset `0x40`, where the CE image
  keeps `ECEC` and its ROM header pointer, while bootstrap 2 ran.

ARMADA's kernel itself (`nk.exe` StartUp at `0x8c0120c0`, reached through a
jump at the body start) sets its own SR, stack and VBR at once and does not
read the bootstrap's state, so the reset is most likely inside bootstrap 2.

## Console result: second boot test, build 15b912ccfff5 (2026-10-03)

The same reset, but now clearly after `BOOTSTRAP 2 REACHED GAME ENTRY` and
the relay's screen: bootstrap 2 completed and the reset happened inside
Windows CE. The owner supplied ARMADA's IP.BIN (analysis only, not
committed). Its bootstrap 2 is SEGA's standard one ("IP Ver 1.03", January
1999): it disables the caches, clears 0x8c00fc00–0x8c010000, sets SR
`0x700000f0`, R15 and VBR `0x8c00f400`, FPSCR `0x40001`, and jumps to the
address stored at `0x8c00e004` (`0xac010000`). It never reads IP byte `0xFC`.

Reading ARMADA's kernel image for what CE expects of the BIOS:

- `wsegacd.dll` (the CD driver) reads IP bytes `0xF0`–`0xFB` (a 12-character
  string) and `0xFD` (4–99) only when byte `0xFC` is 1, so the real BIOS
  writes boot information there; with `0xFC` not 1 (as on disc, or cleared)
  the driver takes its "not available" path. It copies 256 bytes from IP
  `0x100`, the high-density TOC stored on the disc (`TOC1`, tracks 3–5).
- Its initialization loops on **BIOS system function 2** (`0x8c0000e0`,
  R4=2) until it is not negative; 0 means the disc is present and unchanged
  (it then copies the TOC), above 0 clears its TOC. That is the BIOS's
  check of the disc in the physical drive. K-UI forwarded it to the BIOS,
  which saw K-UI's own disc or none: the most likely reset.
- `platutil.dll` calls the BIOS sysinfo, font and flash vectors directly
  (unchanged by K-UI) and system function 1 (exit to menu, which K-UI already
  turns into its counters screen and restart).
- CE's debug output is enabled only on SEGA development hardware (it probes
  `0xa05f68a0` and looks for a monitor at `0xac008000`/`0xac004000`), so a
  retail console shows none.

The next build's CE reader answers function 2 itself (0: disc present and
unchanged), records it in the trace as `E0`, and stops with
`CE PASSED A VIRTUAL ADDRESS` at the first GD pointer argument (R5 of
REQUEST/CHECK, R4 of DRIVE/DATATYPE) that is not a main-RAM alias.

## Console result: disc-check build 21c31ca296bf (2026-10-03)

The first stop screen from inside Windows CE: `CE PASSED A VIRTUAL ADDRESS`
after 4 calls, from `wsegacd.dll` (caller `01DE1F8A`), SR `40008000` (kernel
mode, interrupts enabled), MMUCR `5800B801` (MMU on), VBR `8C0120F0` (CE's
table). The calls: GD INIT; REQUEST command `0x18` (drive init, no
parameters); EXEC; CHECK of token 1 with its status buffer at `080DFCF0` on
CE's stack (`080DFCDC`), a virtual address in the CD driver's process.

The driver's init (`0x8c0aaf20`) is REQUEST `0x18`, then EXEC and CHECK in a
loop: CHECK 2 (done) continues, 1 (busy) sleeps 10 ms and polls again, -1
(failed) reads the error code and runs its disc check (BIOS system function
2). The earlier builds refused the status buffer, so CHECK failed and the
disc check reached the real BIOS: that was the reset. After a command
completes it polls its disc interrupt event (SYSINTR 20) with a zero timeout,
so it does not depend on the interrupt to make progress.

ARMADA's driver uses GD functions INIT, REQUEST, EXEC, CHECK, ABORT, DRIVE,
DMA/PIO transfer and check (6, 7, 12, 13) and the PIO callback (11), and
commands 16, 17, 19, 20–23, 24, 26, 27, 30, 31, 33, 34, 36, 38 and 39. K-UI's
service lacks commands 26, 38, 39 and functions 6, 7, 12, 13 (11 only with
no callback).

Next build: the CE reader uses CE's virtual addresses directly. It masks
interrupts but leaves SR.BL clear, so CE's own TLB-miss handler maps each
page as the service reads or writes it; the service passes U0/P3 addresses
(only while the MMU is on) to the CE reader instead of refusing them.

## Console result: virtual-address build 6eb4736083b8 (2026-10-03)

ARMADA went past `ENTERING WINDOWS CE`; the screen went black (CE's display
driver taking over the video) and stayed black: no stop screen, no reset. So
CE accepted the virtual-address answers and asked for nothing K-UI refuses,
but it is waiting on something not yet visible.

Reading `wsegacd.dll` further: a request runs synchronously (EXEC and CHECK
with 5 ms sleeps) unless CHECK reports word 3 = 1, which K-UI never writes;
only then does its interrupt thread wait for the disc interrupt (SYSINTR 20,
15 s timeout, then ABORT). The platform's `ResetToFirmware` (`platutil.dll`)
calls the BIOS menu vector (`0x8c0000e0`, R4=1), which K-UI's reader catches.

Next build: two ways to see the hang.

- **Live status line** near the top of the frame CE is showing (its start
  and line pitch read from the video registers, nothing changed), redrawn on
  every disc request and every 16th call: `CALLS FUNCTION COMMAND SECTORS
  LBA` (calls so far, the last GD function, the last command, sectors read
  so far, the last sector address). If it keeps changing, CE is still
  reading; if it stops, the last values say where.
- **A+B+X+Y+Start** during the hang: if CE's controller handling still runs,
  K-UI's exit screen shows the guard, steps and sectors, CE's last caller
  and four calls, and the last command (`COMMAND LBA SECTORS DEST`), held
  for about 15 seconds before K-UI restarts.

## Console result: status-line build ec6d39cc5372 (2026-10-04)

This time ARMADA stopped with `GD REQUEST REJECTED` after 26 calls: REQUEST
(R7 0) for command `0x26` (38, DMA stream read), parameters at `0204FAF0`
on CE's stack, from `wsegacd.dll` (caller `01DE2DC2`). The earlier calls end
with CHECK, EXEC, CHECK of token 6. (The previous build's black screen was
probably the same point, its stop screen not reached or not drawn.)

How ARMADA's driver reads: it locks the buffer's pages and lists their
physical pieces (at most 4 KiB each, 32-byte aligned). One piece: DMAREAD
(17). Several: DMAREAD_STREAM_EX (38) with {FAD, sectors, 0}; when CHECK
first reports 3 it starts DMA_TRANSFER (6) {address, bytes} of the first
piece. A DMA thread waits on SYSINTR 21 (Holly ISTNRM bit 14, GD DMA end),
checks DMA_CHECK (7) for 0 and transfers the next piece. The request
completes when SYSINTR 20 (ISTEXT bit 0, the drive) wakes the interrupt
thread, whose CHECK then returns 2. A missing interrupt 20 times out after
15 s and aborts the read.

K-UI cannot make the G1 DMA or the drive raise those, so the CE reader raises
them inside CE's kernel the way CE's own interrupt dispatch does after the
platform handler returns a SYSINTR: set the pending bit, queue SYSINTR-8 in
the 32-entry ring after the ring's head index, set the reschedule flag. The
scheduler then sets the driver's events. In ARMADA's `nk.exe` these are
`0x8c145b40`, `0x8c145aa8` and `0x8c145884` (KData + 0x340, 0x2a8, 0x84). The
stage finds them by matching that dispatch code in the loaded kernel (one
match each in ARMADA and two other titles' kernels, at different addresses).

Next build:

- The CE reader serves command 38: CHECK returns 3 (STREAMING) while bytes
  remain; DMA_TRANSFER copies its piece at once (pieces may split sectors:
  `kui_retail_image_read_part`), raises SYSINTR 21, and after the last piece
  completes the command and raises SYSINTR 20; DMA_CHECK returns 0 with 0
  bytes left.
- The stage shows `CE PEND CE RING RESCHED` (the three addresses), or
  `CE KERNEL INTERRUPTS NOT FOUND`, on the placement screen.
- The CE reader may now fill up to `0x8c00c000`, with a 2 KiB stack at
  `0x8c00c000`–`0x8c00c800` (the IP's lower bootstrap area, unused once
  bootstrap 2 at `0x8c00e000` runs). Native readers are unchanged.
- Still missing for ARMADA: commands 26 and 39 (PIO stream), functions 12
  and 13, and 11 with a callback.
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

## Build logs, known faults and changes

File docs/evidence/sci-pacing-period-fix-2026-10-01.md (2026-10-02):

# Game pacing: use the programmed scanline period

**Console follow-up:** build `ce7006087f20` now shows enlarged steps on
79.19% of reading calls, an owner-reported 18-second Kasumi load and working
FMVs. See the [result and remaining fight-start issue](sci-pacing-period-console-2026-10-01.md).
The original pre-test reasoning below is retained for provenance.

## Trigger and limits

The owner's `8d930310f79d` return photo still shows zero enlarged steps:
5,970 successful read steps and 11,880 game sectors (1.98995 per step).
The button combination first returned DOA2 to its title screen and required
several more attempts before returning to K-UI. Those soft resets preserve
the resident's cumulative diagnostics. They add activity to the totals;
they cannot erase earlier enlarged steps. See the
[photo and reported 25-second load](sci-game-pacing-result-2026-10-01.md).

The photo does not report video-register geometry or actual resident read
cost. It therefore does not prove that the defect below occurred in this
particular launch. The reported smoother combat and shorter loading remain
observations with an unestablished cause, not proof that batching activated.

## Reproduced defect

The old reader inferred counter length from the vblank-in interrupt line,
capping the largest observed scanline at `vbi + vbi/8`. These are independent
register settings. A valid NTSC interlaced configuration has a 525-tick
counter and vblank-in at 260; a PAL interlaced configuration can have a
625-tick counter and the same interrupt line.

For `(period=525, vbi=260)`, the old estimate was capped at 293 ticks.
It rejected valid current lines above 292, halved the moving-screen time
allowance, and could underflow when timing a read across a counter wrap:

```
start=450, samples=524 then 50, one wrap, two game sectors
old cost16 = (293 + 50 - 450) * 16 / 2 = 2147482792 (uint32_t)
true cost16 = (525 + 50 - 450) * 16 / 2 = 1000
```

That inflated cost can suppress batching until it decays, while another
wrap can inflate it again. A temporary host harness reproduced the old
result against the unmodified source. This is an arithmetic regression
case, not a measured console performance result.

## Original implementation

- Read PowerVR `SPG_LOAD` at offset `0xd8`; its bits 25:16 store the vertical
  counter period minus one. Replace inferred maximum scanline state with
  this programmed period.
- Use that period both for elapsed read timing and the existing pacing
  allowance. Sector limits and duration policy are unchanged: two by default,
  at most four for moving buffers within a predicted half-period, up to
  eight for a sufficiently still buffer.
- Reject invalid start/end lines and implausible geometry. A timing epoch
  invalidates measurements spanning a geometry change, including a change
  back to the original mode, or an inconsistent sample. These changes clear
  learned cost, stillness and spin accumulation without inventing counter
  wraps. Early vblank interrupt positions are valid independently of period.
- Replace less useful return-screen fields with latest `PACE PERIOD`,
  `PACE VBI`, `PACE COST16`, `PACE STILL` and `PACE LINE`. Keep cumulative
  read, sector, frame, enlarged-step, spin-step and guard-fault counters.
  The five timing fields are current state, not a snapshot of the fight;
  returning to the title screen can change them. `PACE COST16 / 16` is
  estimated counter ticks per game sector, not microseconds.

No SWAT/DreamShell driver code was copied. Transport, per-block CRC, stream
cleanup, memory/stack reservations and interrupt restoration are unchanged.
The new geometry read is read-only. Windows CE remains a separate loader task.

## Primary cross-checks

- [KallistiOS video implementation](https://github.com/KallistiOS/KallistiOS/blob/master/kernel/arch/dreamcast/hardware/video.c),
  retrieved blob `7a1907890668beba74b8fd94194018412aac438c`: 524/624
  interlace vertical counts, interrupt line 260, and register programming.
- [Flycast scanline generator](https://github.com/flyinghead/flycast/blob/master/core/hw/pvr/spg.cpp),
  retrieved blob `f2f0cca5051ddd3f829f7b70814da05e5406f649`: counter wraps
  at `SPG_LOAD.vcount + 1`, including interlaced modes.
- [Flycast register definitions](https://github.com/flyinghead/flycast/blob/master/core/hw/pvr/pvr_regs.h),
  retrieved blob `81bc5cd27cdfa7c2f0da8c594a72cf3c6c7593e8`: register
  offsets and field widths. These sources establish the independent
  period/interrupt settings; they do not establish DOA2's particular settings.

## Validation and next console check

246 focused host checks pass under AddressSanitizer/UndefinedBehaviorSanitizer.
Coverage includes real interlace tuples, VGA, explicit wrap arithmetic,
moving/still limits, early vblank positions, invalid samples and geometry
changes. Host models do not establish hardware speed.

Local SH-4 normal and benchmark builds pass linked instruction, layout and
stack audits with unchanged guards. SCI payload is 11,164 bytes, resident
end `0x8c00baec` (20 bytes free), conservative stack 1,184/1,232 bytes.
SCIF/IDE payloads are 10,652/9,876 bytes and stack bounds 1,084/1,004 bytes.
Normal entry/stage payloads are 56,704/48,512 bytes; normal/benchmark audits
inspect 18,962/19,831 linked instructions. There are no unresolved symbols
or resident FPU instructions. Official CI run 36947691757 subsequently passed
both jobs with the same audit figures; the console result records package
verification and provenance.

Repeat the same Kasumi-to-first-fight timing and check the first ten seconds
of combat, speech and an FMV. Then capture the K-UI return screen; if DOA2
first resets to its title screen, release the buttons before trying again.
Note any intervening resets. The decisive first question is whether
`PACED STEPS` becomes nonzero. A new Storage soak is unnecessary for this
resident-only correction. Use `8d930310f79d` as the console comparison build.

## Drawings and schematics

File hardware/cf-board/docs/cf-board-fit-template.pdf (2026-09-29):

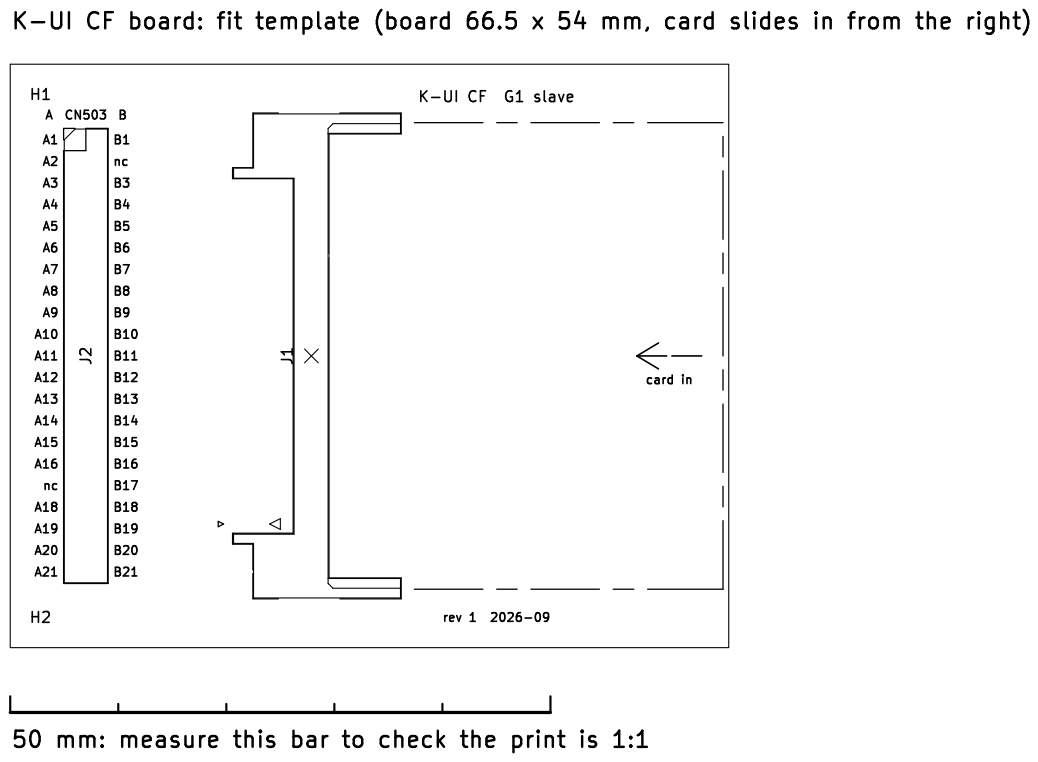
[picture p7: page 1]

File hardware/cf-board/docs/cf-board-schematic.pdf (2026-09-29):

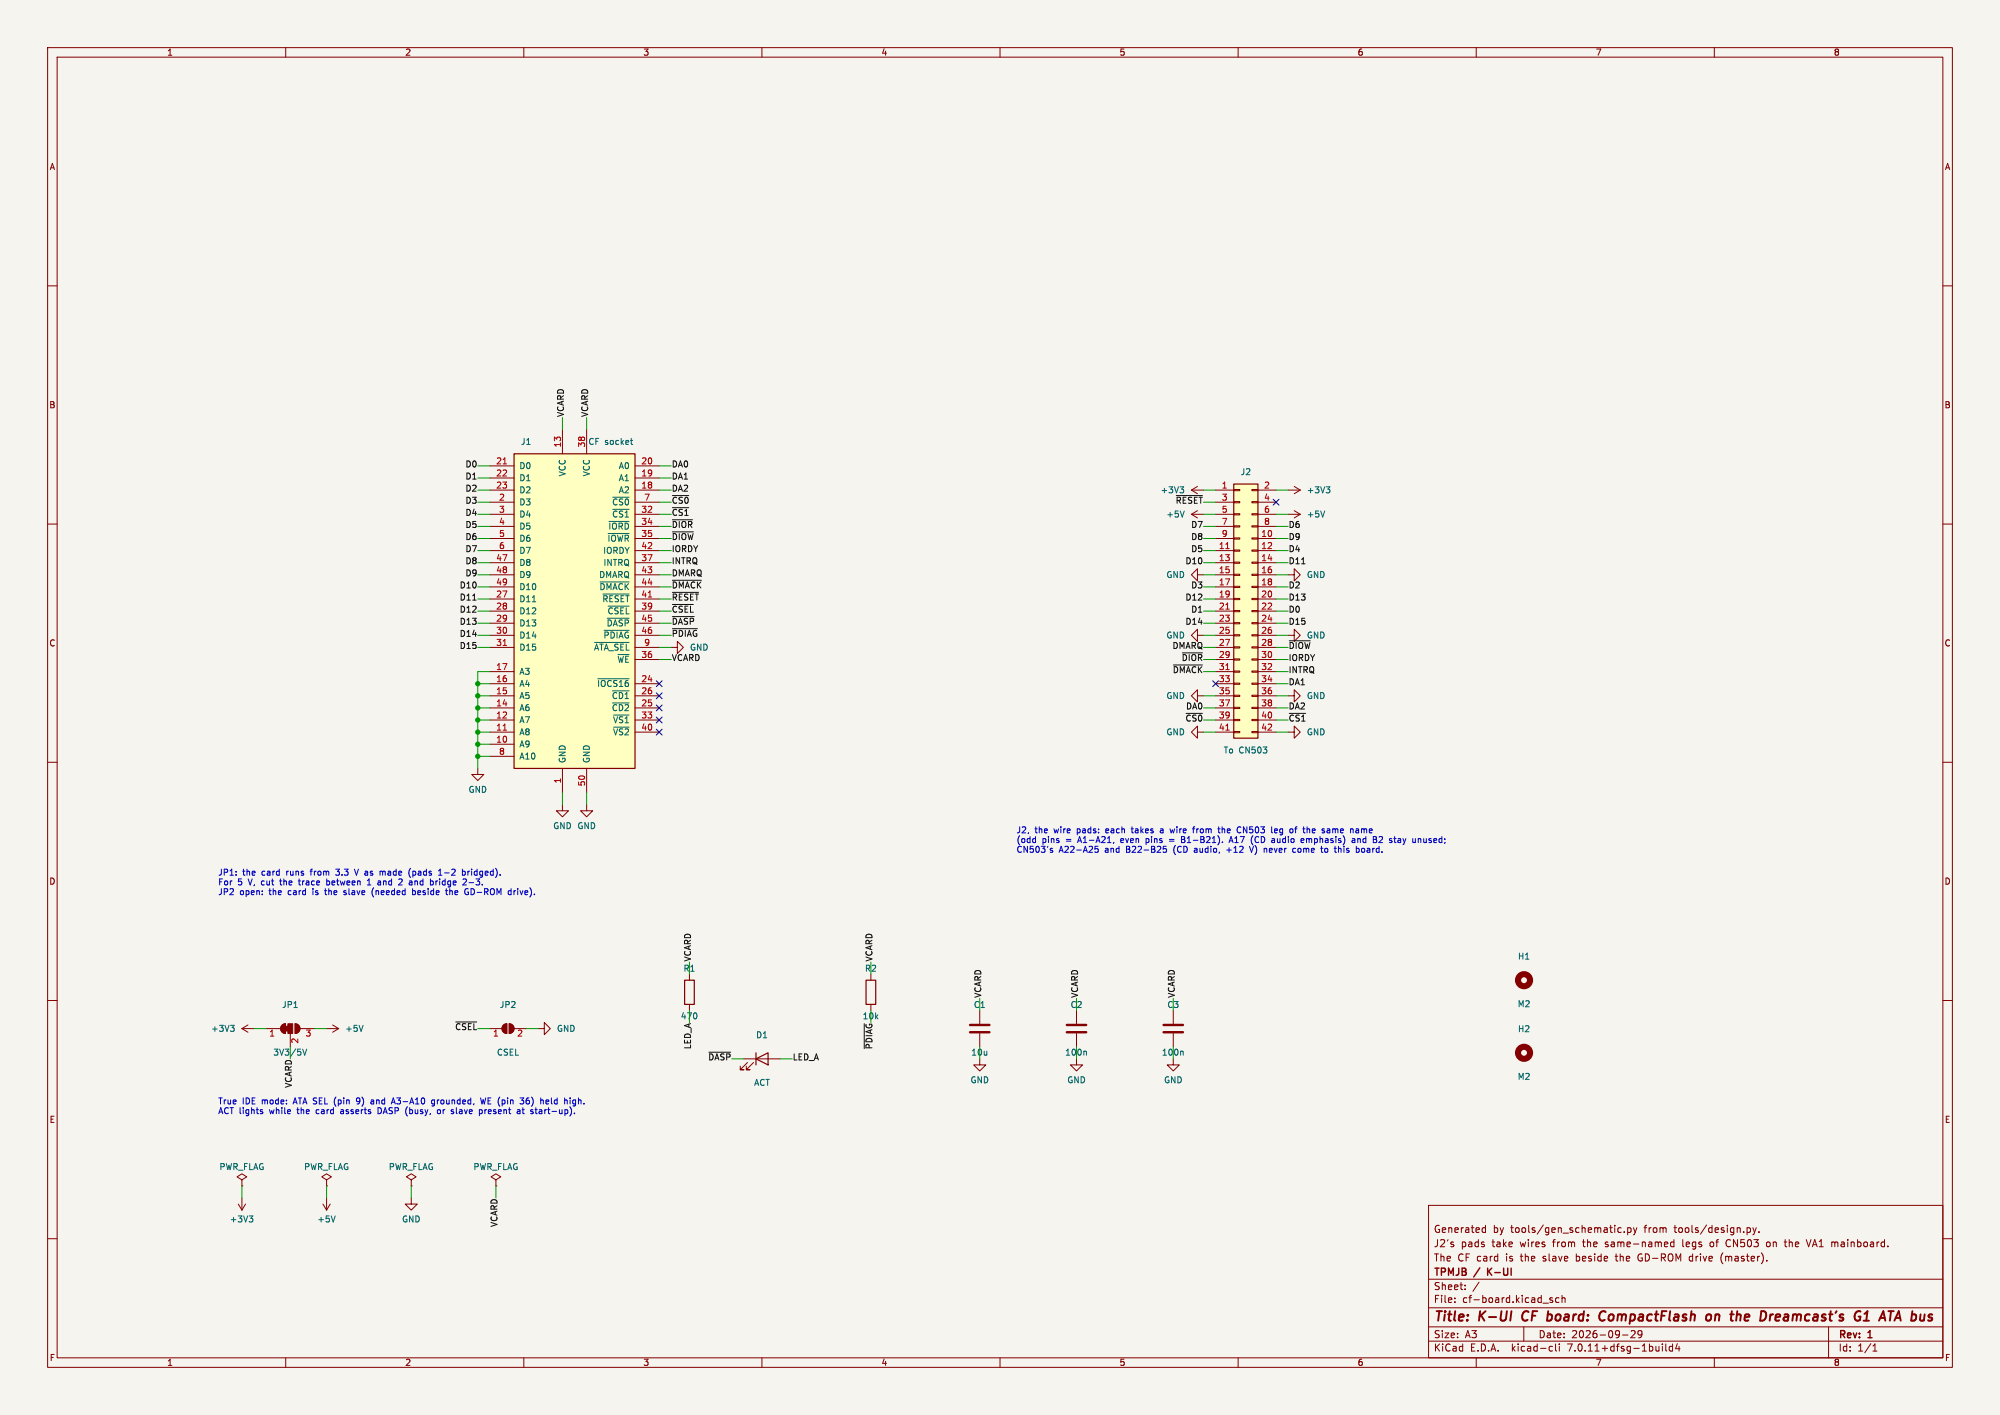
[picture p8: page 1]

1 A9 10 A8 11 A7 12 VCC 13 A6 14 A5 15 A4 16 A3 17 A2 18 A1 19 D3 2 A0 20 D0 21 D1 22 D2 23 ~{IOCS16} 24 ~{CD2} 25 ~{CD1} 26 D11 27 D12 28 D13 29 D4 3 D14 30 D15 31 ~{CS1} 32 ~{VS1} 33 ~{IORD} 34 ~{IOWR}35 ~{WE}36

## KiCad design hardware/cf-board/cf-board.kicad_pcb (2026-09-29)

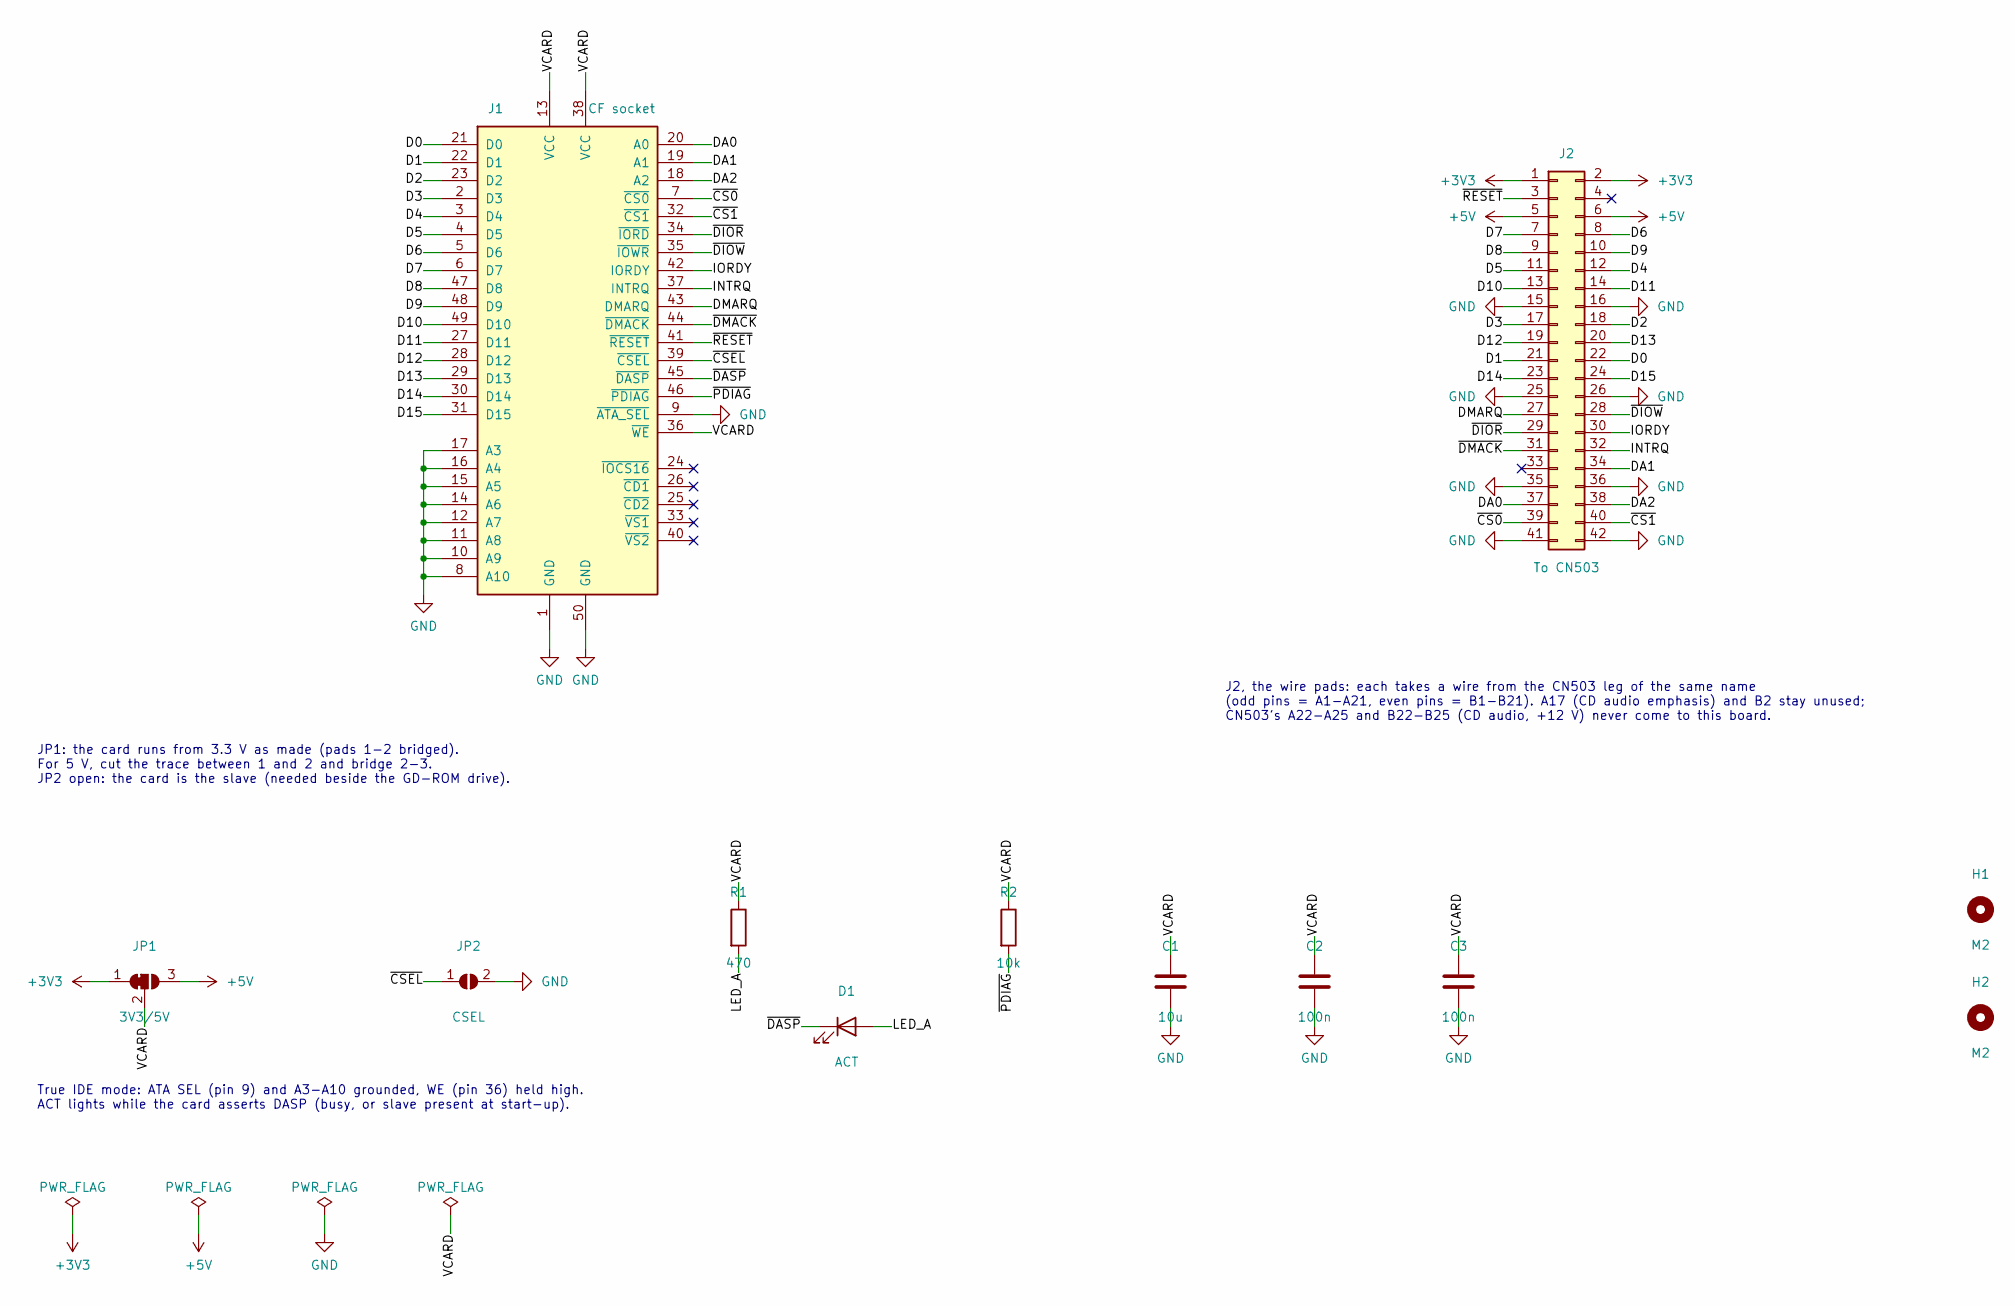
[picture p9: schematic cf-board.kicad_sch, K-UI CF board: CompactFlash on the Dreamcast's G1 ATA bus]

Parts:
C1: 10u; C_0805_2012Metric_Pad1.18x1.45mm_HandSolder
C2, C3: 100n; C_0805_2012Metric_Pad1.18x1.45mm_HandSolder
D1: ACT; LED_0805_2012Metric_Pad1.15x1.40mm_HandSolder
H1, H2: M2; MountingHole_2.2mm_M2
J1: CF socket; CF-Card_3M_N7E50-E516xx-30_SmallRing
J2: To CN503; PinHeader_2x21_P2.00mm_Vertical
JP1: 3V3/5V; SolderJumper-3_P1.3mm_Bridged12_RoundedPad1.0x1.5mm
JP2: CSEL; SolderJumper-2_P1.3mm_Open_RoundedPad1.0x1.5mm
R1: 470; R_0805_2012Metric_Pad1.20x1.40mm_HandSolder
R2: 10k; R_0805_2012Metric_Pad1.20x1.40mm_HandSolder

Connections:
+3V3: J2.1, J2.2, JP1.1 (A)
+5V: J2.5, J2.6, JP1.3 (B)
/D0: J1.21 (D0), J2.22
/D1: J1.22 (D1), J2.21
/D2: J1.23 (D2), J2.18
/D3: J1.2 (D3), J2.17
/D4: J1.3 (D4), J2.12
/D5: J1.4 (D5), J2.11
/D6: J1.5 (D6), J2.8
/D7: J1.6 (D7), J2.7
/D8: J1.47 (D8), J2.9
/D9: J1.48 (D9), J2.10
/D10: J1.49 (D10), J2.13
/D11: J1.27 (D11), J2.14
/D12: J1.28 (D12), J2.19
/D13: J1.29 (D13), J2.20
/D14: J1.30 (D14), J2.23
/D15: J1.31 (D15), J2.24
/DA0: J1.20 (A0), J2.37
/DA1: J1.19 (A1), J2.34
/DA2: J1.18 (A2), J2.38
/DMARQ: J1.43 (DMARQ), J2.27
/INTRQ: J1.37 (INTRQ), J2.32
/IORDY: J1.42 (IORDY), J2.30
/LED_A: D1.2 (A), R1.2
/VCARD: C1.1, C2.1, C3.1, J1.13 (VCC), J1.36 (~WE), J1.38 (VCC), JP1.2 (C), R1.1, R2.1
/~CS0: J1.7 (~CS0), J2.39
/~CS1: J1.32 (~CS1), J2.40
/~CSEL: J1.39 (~CSEL), JP2.1 (A)
/~DASP: D1.1 (K), J1.45 (~DASP)
/~DIOR: J1.34 (~IORD), J2.29
/~DIOW: J1.35 (~IOWR), J2.28
/~DMACK: J1.44 (~DMACK), J2.31
/~PDIAG: J1.46 (~PDIAG), R2.2
/~RESET: J1.41 (~RESET), J2.3
GND: C1.2, C2.2, C3.2, J1.1 (GND), J1.8 (A10), J1.9 (~ATA_SEL), J1.10 (A9), J1.11 (A8), J1.12 (A7), J1.14 (A6), J1.15 (A5), J1.16 (A4), J1.17 (A3), J1.50 (GND), J2.15, J2.16, J2.25, J2.26, J2.35, J2.36, J2.41, J2.42, JP2.2 (B)

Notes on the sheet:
J2, the wire pads: each takes a wire from the CN503 leg of the same name (odd pins = A1-A21, even pins = B1-B21). A17 (CD audio emphasis) and B2 stay unused; CN503's A22-A25 and B22-B25 (CD audio, +12 V) never come to this board.
JP1: the card runs from 3.3 V as made (pads 1-2 bridged). For 5 V, cut the trace between 1 and 2 and bridge 2-3. JP2 open: the card is the slave (needed beside the GD-ROM drive).
True IDE mode: ATA SEL (pin 9) and A3-A10 grounded, WE (pin 36) held high. ACT lights while the card asserts DASP (busy, or slave present at start-up).

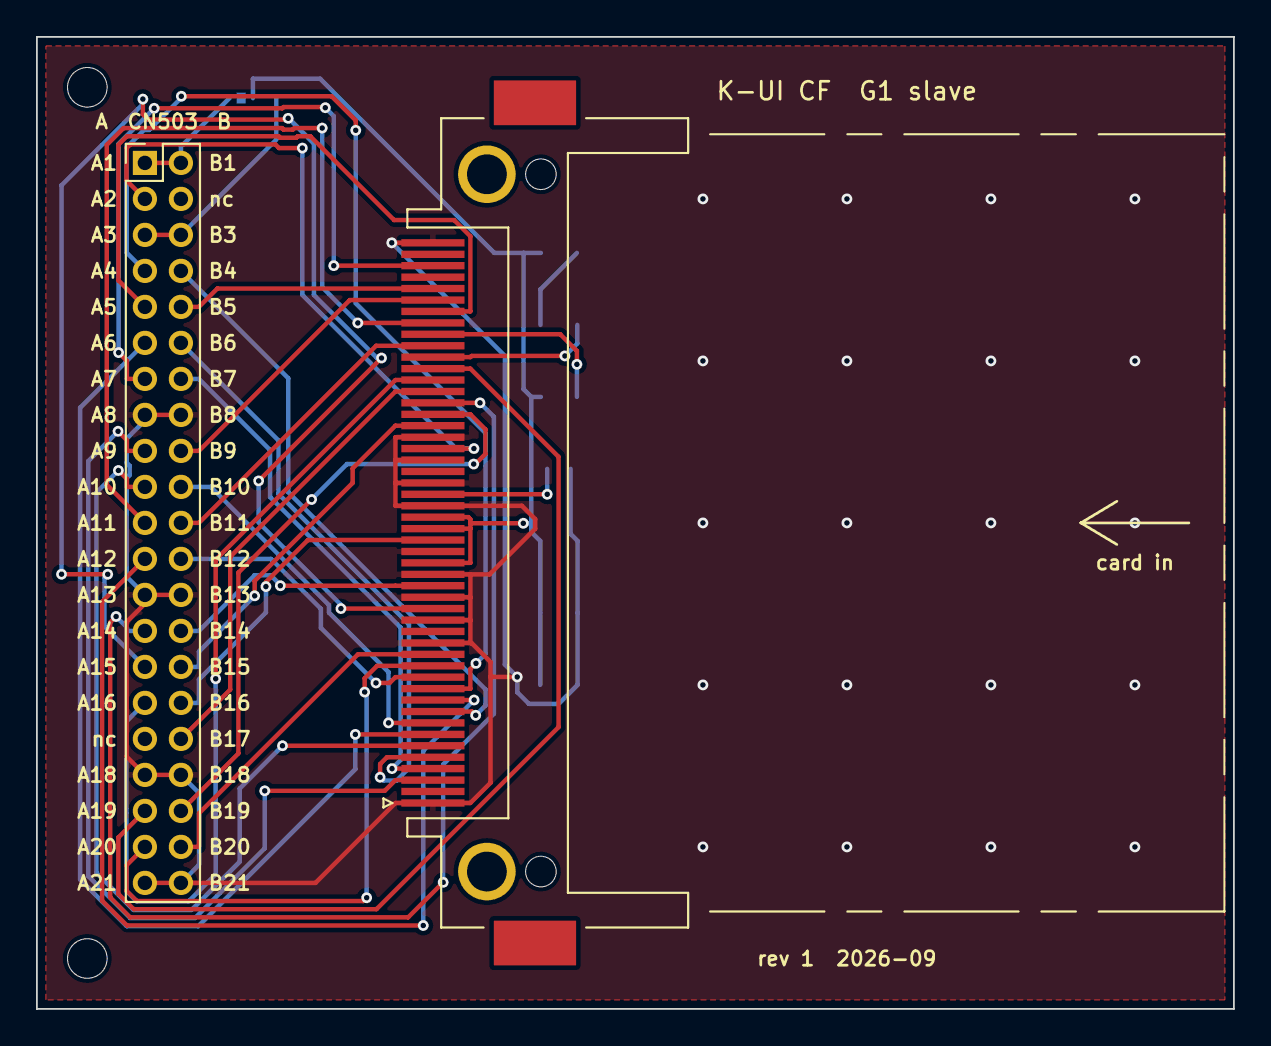
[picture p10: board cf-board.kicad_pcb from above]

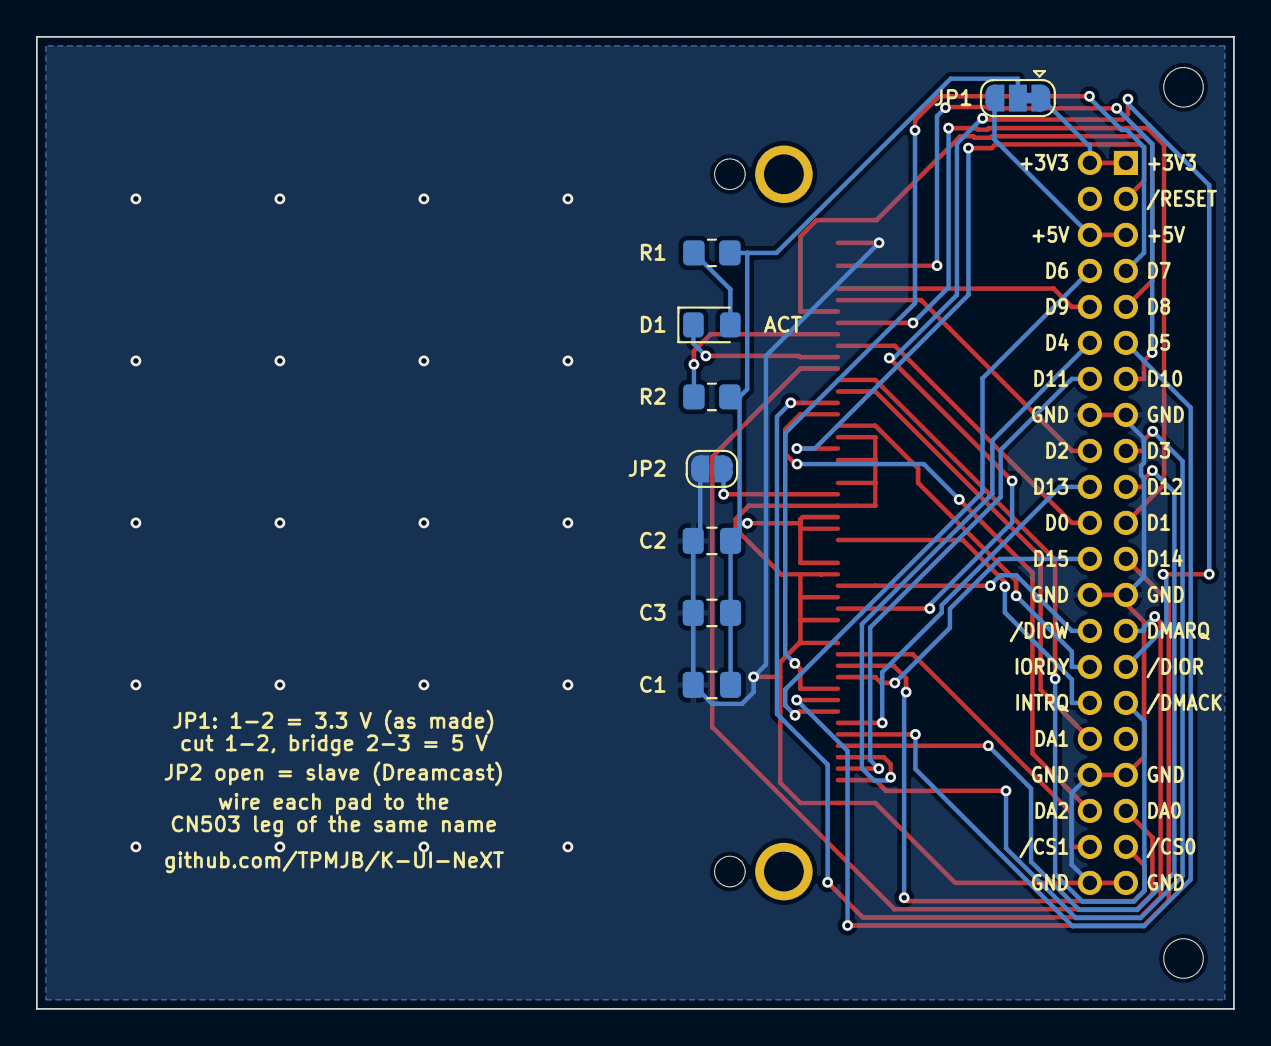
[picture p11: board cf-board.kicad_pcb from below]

Board: 2 copper layers, 66.5 x 54.0 mm, 12 parts (8 on the bottom side), 36 nets.

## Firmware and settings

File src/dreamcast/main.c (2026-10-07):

/* SPDX-License-Identifier: GPL-3.0-only */
#include "platform.h"
#include "kui/version.h"
#include "kui/ui_rate.h"
#include "kui/report.h"
#include "kui/clock_platform.h"
#ifndef KUI_SD_RUNTIME
#include "kui/boot_ui.h"
#endif
#ifdef KUI_SD_RUNTIME
#include "kui/shell.h"
#include "kui/settings.h"
#include "kui/system_settings.h"
#include "kui/disc_identity.h"
#include "kui/music.h"
#include "kui/apps.h"
#include "kui/music_player.h"
#include "kui/games.h"
#include "kui/games_probe.h"
#include "kui/games_image_probe.h"
#include "kui/games_retail.h"
#include "kui/games_covers.h"
#include "kui/image_loader_layout.h"
#include <arch/exec.h>
#include "kui/splash.h"
#include "kui/gd_play.h"
#include "kui/recovery_scan.h"
#include "kui/capture_display.h"
#include "kui/viewport.h"
#include "kui/network_probe.h"
#include "kui/ftp.h"
#include "kui/salvage.h"
#include "kui/maintenance.h"
#include "kui/menu_sound.h"
#include "kui/cd_audio.h"
#include "kui/storage_test.h"
#include "sd.h"
#include "sci_sd_bus.h"
#include "kui/sci_video_quiet.h"
#include <dc/sq.h>
#endif
#include <kos.h>
#include <dc/minifont.h>
#include <stdarg.h>
#include <stdio.h>
#include <string.h>

/* No KOS CD/VFS polling and no serial console competing with the SD adapter. */
#ifdef KUI_SD_RUNTIME
KOS_INIT_FLAGS(INIT_IRQ | INIT_CONTROLLER | INIT_VMU | INIT_NO_DCLOAD | INIT_QUIET);
#else
KOS_INIT_FLAGS(INIT_IRQ | INIT_CONTROLLER | INIT_NO_DCLOAD | INIT_QUIET);
#endif
#ifndef KUI_BUILD_ID
#define KUI_BUILD_ID "local-unversioned"
#endif
#define KUI_BUTTON_BENCH (1u<<29)
#ifndef KUI_SD_RUNTIME
#define KUI_BUTTON_BOOT_LEFT (1u<<30)
#endif
#ifdef KUI_SD_RUNTIME
#define KUI_BUTTON_MSTATS (1u<<30)
static struct kui_memory_stats memory_status;
static bool memory_valid;
static struct kui_shell shell;
static struct kui_settings settings_current, settings_pending;
static unsigned settings_generation;
static char settings_note[96];
static char destination_current[KUI_DEST_ROOT_CAP], destination_pending[KUI_DEST_ROOT_CAP];
static char capture_destination[KUI_DEST_ROOT_CAP], destination_note[128];
static bool destination_ready;
static unsigned destination_generation, destination_result, destination_offset;
static struct kui_destination_page destination_listing;
static struct kui_capture_stats capture_summary;
static struct kui_capture_display capture_display;
static bool observing_capture;
static enum kui_shell_outcome capture_outcome;
static char capture_message[128];
static bool drive_reset_required, dma_degraded;
static struct kui_system_settings system_current, system_pending;
static unsigned system_generation;
static bool system_ok, system_loaded;
static char system_note[128];
static bool video_preview, video_awaiting_save, safe_video_boot, video_prior_safe;
static unsigned video_prior_mode;
static uint64_t video_deadline;
static unsigned applied_video = KUI_VIDEO_AUTO;
static struct kui_disc_identity disc_identity, disc_snapshot;
static struct kui_music_status music_snapshot;
static struct kui_cd_audio_status cd_audio_snapshot;
static unsigned cd_audio_generation,cd_track_pending;
static bool cd_drive_owned;
static struct kui_app_status memory_test_status, network_test_status,maintenance_status;
static struct kui_vmu_view vmu_snapshot;
static unsigned vmu_generation, vmu_slot_pending, vmu_page_pending, vmu_selected_pending;
static struct kui_vmu_backup_view vmu_backups;
static unsigned vmu_backups_generation,vmu_backup_page_pending,vmu_restore_generation;
static unsigned vmu_delete_generation,vmu_copy_generation,vmu_copy_slot_pending;
static char vmu_restore_path_pending[KUI_VMU_BACKUP_PATH_CAP];
static struct kui_datetime clock_pending,clock_snapshot;
static bool clock_valid;
static unsigned clock_generation;
static char clock_note[128];
static struct kui_storage_test_request storage_test_pending;
static uint32_t storage_baseline_pending;
static struct kui_storage_test_result storage_test_result;
static struct kui_storage_test_history storage_test_history;
static struct kui_storage_test_progress storage_test_progress;
static unsigned storage_test_generation, storage_history_generation;
static bool storage_test_running;
static struct kui_app_status sci_async_status;
/* Only the UI thread draws. A fresh request is acknowledged by that thread
 * after its final frame and SQ drain, never merely by the worker setting a flag. */
static struct kui_sci_video_quiet sci_video_quiet;
static struct kui_app_status scan_status,salvage_status;
static char salvage_path_pending[KUI_DEST_JOB_CAP];
static unsigned salvage_passes_pending;
static bool salvage_zero_pending;
static char scan_path_pending[KUI_DEST_JOB_CAP];
static unsigned active_app;
static bool splash_active,boot_ready,startup_skip,startup_finished;
static bool probe_launch_ready,probe_launch_failed;
static struct kui_runtime_image probe_image;
static struct kui_app_status probe_status;
static uint64_t splash_deadline;
static int music_requested=-1;
static unsigned music_request_generation,music_cache_attempted;
static struct kui_music_player_page music_listing;
static struct kui_app_status player_status;
static unsigned music_listing_generation,music_offset_pending;
static char music_path_pending[256];
static struct kui_games_page games_listing;
static struct kui_games_detail games_detail;
static unsigned games_listing_generation,games_detail_generation;
static unsigned games_offset_pending,games_result_offset;
static unsigned games_epoch_pending,games_result_epoch,games_result_view;
static char games_path_pending[KUI_GAMES_FILE_CAP];
static unsigned games_reader_pending;
static unsigned games_view_pending;
static bool games_refresh_pending,games_cache_clear_pending;
static bool games_warm_done;
static unsigned games_storage_observed=KUI_STORAGE_AUTO;
static struct kui_shell_games_art_key games_art_requested,games_art_running,games_art_published,games_art_done;
static bool games_art_request_valid,games_art_result_ready,games_art_done_valid;
static struct kui_games_entry games_art_entry,games_art_running_entry;
static struct kui_games_cover_result games_art_result;
static struct kui_app_status games_scan_status;
/* The worker fills staging pixels; only main publishes them to the selected
 * cover. A ready result owns staging until main accepts/discards it, so neither
 * an older visible page nor drawing can race the next artwork read. */
static uint16_t games_cover_pixels[KUI_COVER_PIXELS],games_cover_staging[KUI_COVER_PIXELS];
static uint16_t games_detail_cover[KUI_COVER_PIXELS];
/* File Manager: requests copied from the shell when a job is queued, and
 * results the main loop installs by generation. files_status is the live
 * progress; files_result a finished run's (or File Manager song's) status. */
static struct kui_files_request files_request_pending;
static struct kui_files_job files_job_pending;
static struct kui_files_preview files_totals_pending;
static char files_picture_pending[KUI_FILES_PATH_CAP];
static struct kui_files_page files_listing_result;
static struct kui_files_preview files_preview_result;
static struct kui_app_status files_status,files_result;
static struct kui_files_picture files_picture_result;
static unsigned files_listing_generation,files_preview_generation,files_result_generation,files_picture_generation;
static bool files_music;
/* The picture view's pixels: only the worker writes them, and only while
 * the view shows none (its picture is still loading). */
static uint16_t files_picture_pixels[KUI_FILES_PICTURE_EDGE*KUI_FILES_PICTURE_EDGE];
/* FTP server: the status it publishes as it runs, drawn on its page. */
static struct kui_ftp_status ftp_status;
static bool ftp_seen;
/* Wi-Fi page: the job copied from the shell (its password wiped once the
 * job ends) and the view the job publishes as it goes, by generation. */
static struct kui_wifi_request wifi_request_pending;
static struct kui_wifi_view wifi_view;
static unsigned wifi_generation;
static bool is_capture_action(unsigned action) {
    return (action>=4 && action<=6) || action==22;
}

#define KUI_ROLE "SD runtime"
#else
#define KUI_ROLE "CD bootstrap"
#endif

#define LOG_LINES 1500
#define LINE_BYTES 77
#define VISIBLE_LINES 19
static mutex_t lock = MUTEX_INITIALIZER;
static char lines[LOG_LINES][LINE_BYTES];
static unsigned line_count;
static bool log_truncated, busy, cancel_requested, saving_report;
static unsigned pending;
static char report[LOG_LINES * LINE_BYTES + 256];
#ifndef KUI_SD_RUNTIME
static struct kui_boot_ui boot_ui;
static bool boot_worker_available,boot_attempt_cancelled;
static unsigned boot_attempt_previous,boot_held_navigation;
static uint64_t boot_last_draw,boot_repeat_at;
static uint64_t boot_draw_us;
static unsigned boot_draw_count;
static char boot_notice[128]="Ready to load K-UI. Choose a source or insert your card.";
#endif
/* The UI thread is main(). It shares the one CPU with the I/O worker, and a
 * full-screen software redraw plus vid_waitvbl (a busy-wait in this KOS) is a
 * lot of CPU. The cap below lets an operation trade screen updates for speed;
 * KUI_OPT_UI_FULL is the loop exactly as it always was. */
static kthread_t *ui_thread;
static volatile unsigned ui_hz_busy = KUI_OPT_UI_FULL;
void kui_ui_set_hz(unsigned hz) { ui_hz_busy = hz; }

/* Per-thread CPU time in ms from the scheduler. A running thread's current
 * slice is not in its total until the next switch, so add it here. */
static uint64_t cpu_ms(kthread_t *t, uint64_t now_ms) {
    uint64_t ms = thd_get_cpu_time(t);
    if(t == thd_get_current()) ms += now_ms - t->cpu_time.scheduled;
    return ms;
}
void kui_cpu_census_mark(struct kui_cpu_census *out) {
    irq_mask_t irq = irq_disable();   /* one consistent snapshot: no switch mid-sum */
    uint64_t ms = timer_ms_gettime64();
    kthread_t *self = thd_get_current();
    out->wall_us = timer_us_gettime64();
    out->worker_ms = cpu_ms(self, ms);
    out->ui_ms = ui_thread ? cpu_ms(ui_thread, ms) : 0;
    out->total_ms = thd_get_total_cpu_time() + (ms - self->cpu_time.scheduled);
    irq_restore(irq);
}
#ifdef KUI_SD_RUNTIME
static struct kui_capture_progress capture_status;
static uint64_t rate_at,rate_bytes;
static unsigned rate_kib;
static uint64_t phase_started_ms, progress_updated_ms;
void kui_capture_status(void *ctx,const struct kui_capture_progress *p) {
    (void)ctx;mutex_lock(&lock);
    if(capture_status.phase!=p->phase || p->elapsed_ms<rate_at || p->done<rate_bytes) {
        rate_at=p->elapsed_ms;rate_bytes=p->done;rate_kib=0;
        phase_started_ms=timer_ms_gettime64();
    } else if(p->elapsed_ms-rate_at>=1000) {
        rate_kib=(unsigned)((p->done-rate_bytes)*1000/(p->elapsed_ms-rate_at)/1024);
        rate_at=p->elapsed_ms;rate_bytes=p->done;
    }
    kui_capture_display_progress(&capture_display,p);
    capture_status=*p;progress_updated_ms=timer_ms_gettime64();mutex_unlock(&lock);
}
#endif

void kui_log(const char *format, ...) {
    char text[256];
    va_list args;
    va_start(args, format); vsnprintf(text, sizeof(text), format, args); va_end(args);
    mutex_lock(&lock);
#ifdef KUI_SD_RUNTIME
    if(observing_capture) kui_capture_display_log(&capture_display,text);
    if(strstr(text,"DMA stays off until reboot")) dma_degraded=true;
    /* Presentation latch only. The drive adapter owns the actual poisoned
     * state; no UI action clears it or retries an aborted command. */
    if((!strncmp(text,"CMD ",4) && strstr(text," ABORT FAILED: RESET REQUIRED")) ||
        strstr(text," GUARD CORRUPTION: RESET REQUIRED"))
    {
        drive_reset_required=true;
        disc_snapshot.title[0]=0;
        disc_snapshot.state=KUI_DISC_IDENTITY_RESET_REQUIRED;
    }
#endif
    size_t size = strlen(text);
    for(size_t pos = 0; pos < size || pos == 0; pos += LINE_BYTES - 1) {
        if(line_count == LOG_LINES) {
            log_truncated = true;
            memmove(lines, lines + 1, (LOG_LINES - 1) * LINE_BYTES);
            --line_count;
        }
        snprintf(lines[line_count++], LINE_BYTES, "%.*s", LINE_BYTES - 1, text + pos);
    }
    mutex_unlock(&lock);
}
bool kui_cancelled(void) {
    mutex_lock(&lock);
    bool requested = cancel_requested;
    mutex_unlock(&lock);
    return requested;
}
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
int main(void) {
    kui_storage_boot_begin();
    ui_thread = thd_get_current();
    vid_set_mode(DM_640x480 | DM_MULTIBUFFER, PM_RGB565);
    kui_log("Running " KUI_RELEASE_SHORT " " KUI_ROLE " build " KUI_BUILD_ID);
    kui_clock_start(kui_log);
    kui_log("Video: %ux%u %s %s, buffered",
        (unsigned)vid_mode->width, (unsigned)vid_mode->height,
        vid_mode->cable_type == CT_VGA ? "VGA" :
            (vid_mode->flags & VID_PAL ? "PAL" : "NTSC"),
        vid_mode->flags & VID_INTERLACE ? "interlaced" : "progressive");
#ifndef KUI_SD_RUNTIME
    kui_boot_ui_init(&boot_ui,timer_ms_gettime64());
    kui_log("CD menu: B stays here; X opens recovery; startup boot begins after 3 seconds.");
    kui_log(kui_storage_boot_from_card()?"Card boot: automatic loader override bypassed.":
        "CD autoboot: optional /KUI/boot.kui first; Start K-UI bypasses it.");
    kui_log("Choose Auto, SCIF, SCI or IDE/CF. A retries after inserting an SD card.");
    kui_log("Boot images are read-only. Built-in diagnostics label and confirm writes.");
#endif
    kui_log("Diagnostic code and fonts are loaded entirely in RAM.");
    kui_log("Replace boot CD with a known-good retail GD-ROM; close lid.");
#ifdef KUI_SD_RUNTIME
    kui_log("Diagnostics page: A disc samples; X SD test; Y save log.");
#else
    kui_log("Open Diagnostics for disc samples, storage write/read checks, or log saving.");
#endif
    kui_log("Use a spare test card for write tests. No formatting; existing files preserved.");
#ifdef KUI_SD_RUNTIME
    kui_system_settings_default(&system_current);system_pending=system_current;
    kui_music_init(kui_log);kui_disc_identity_init(&disc_identity);
    kui_disc_identity_park(&disc_identity);disc_snapshot=disc_identity;
    safe_video_boot=(controller_buttons()&CONT_Y)!=0;
    kui_settings_default(&settings_current);
    settings_pending = settings_current;
    kui_shell_init(&shell, &settings_current);
    kui_shell_set_system_preferences(&shell,&system_current);
    kui_destination_default(destination_current);
    snprintf(settings_note,sizeof(settings_note),"Loading preferences from storage...");
    pending = 27; busy = true; splash_active=true;
    splash_deadline=timer_ms_gettime64()+3000;
    kui_log("K-UI launcher: Disc Ripper, VMU, Memory, Network, Settings, Diagnostics, GD Play and Music.");
    kui_log("B skips the original startup splash/chime. Home Y cycles menu music volume/off.");
    kui_log("Ripper: A new dump (confirm), X resume latest matching disc, Y verify.");
    kui_log("B returns home while idle; during work it stops and checkpoints.");
    kui_log("New dumps use game-named folders in /Games; duplicates get a number.");
    kui_log("Home/Ripper L/R: previous/next song. Ripper Start: Advanced, destination and settings.");
    kui_log("Newly inserted GD-ROM titles appear while idle, then the disc stops.");
    kui_log("The boot disc stays stopped; disc apps start the drive when requested.");
    kui_log("System Settings: video, memory display and menu music. Hold Y on runtime start for safe video.");
    kui_log("Reports say if a dump matches Redump/TOSEC (copy data/known-dumps/*.db to KUI/).");
    kui_log("Capture defaults: CRC32, no automatic readback. Y Verify rereads saved files.");
    kui_log("Saved preferences apply first; explicit /KUI/bench.cfg keys override them.");
    kui_log("Capture/Resume/Verify auto-save a report after ending. Wait for READY.");
    kui_log("Diagnostics R trigger: isolated benchmarks from /KUI/bench.cfg.");
    kui_log("The screen redraws 2x a second while working, which frees CPU (ui_hz=full: off).");
#else
    kui_log("Configured benchmarks use /KUI/bench.cfg; B stops safely.");
    kui_log("Bench SD sections write temporary test files; results auto-save to SD.");
    kui_log("Full capture is available in the updated SD runtime.");
#endif
    /* Code, fonts and assets are already in RAM. Show the boot screen before
     * the bounded STOP; no worker or app can own the drive at this point. Do
     * not read the boot disc merely to populate the optional idle title. */
#ifdef KUI_SD_RUNTIME
    draw_shell();
#else
    draw_boot();
#endif
    (void)kui_disc_stop();
    /* A slow STOP must not consume the interval in which input can cancel
     * automatic startup, nor expire the chime before its worker starts. */
#ifdef KUI_SD_RUNTIME
    splash_deadline=timer_ms_gettime64()+3000;
#else
    kui_boot_ui_init(&boot_ui,timer_ms_gettime64());
#endif
    kthread_attr_t attrs = {.stack_size = 64 * 1024, .label = "kui-io"};
    kthread_t *io_worker=thd_create_ex(&attrs,worker,NULL);
#ifndef KUI_SD_RUNTIME
    boot_worker_available=io_worker!=NULL;
#endif
    if(!io_worker) {
#ifdef KUI_SD_RUNTIME
        kui_log("Unable to start I/O worker; reset console");
        for(;;) {draw_shell();thd_sleep(100);}
#else
        kui_log("Diagnostic worker unavailable; boot, recovery, tools and log viewing remain available.");
        snprintf(boot_notice,sizeof(boot_notice),"Diagnostics unavailable; boot and recovery still work.");
#endif
    }
#ifdef KUI_SD_RUNTIME
    kui_memory_log("runtime ready");
    memory_valid=kui_memory_snapshot(&memory_status);
    uint64_t next_memory_sample=timer_ms_gettime64()+1000;
#endif
    unsigned previous = 0;
    uint64_t last_draw = 0;
    bool was_busy = false;
#ifdef KUI_SD_RUNTIME
    unsigned seen_settings_generation = 0, seen_destination_generation = 0;
    unsigned seen_system_generation=0,seen_vmu_generation=0,seen_music_listing=0;
    unsigned seen_clock_generation=0,seen_vmu_backups=0,seen_vmu_restore=0;
    unsigned seen_storage_test=0,seen_storage_history=0;
    unsigned seen_vmu_delete=0,seen_vmu_copy=0,seen_cd_audio=0;
    unsigned seen_games_listing=0,seen_games_detail=0;
    unsigned seen_files_listing=0,seen_files_preview=0,seen_files_result=0,seen_files_picture=0;
    unsigned seen_wifi_generation=0;
    bool startup_routed=false;
    unsigned held_navigation = 0;
    uint64_t repeat_at = 0;
#endif
    for(;;) {
        unsigned buttons = controller_buttons();
        unsigned pressed = buttons & ~previous;
        previous = buttons;
#ifdef KUI_SD_RUNTIME
        const unsigned navigation = CONT_DPAD_UP | CONT_DPAD_DOWN | CONT_DPAD_LEFT | CONT_DPAD_RIGHT;
        unsigned held = buttons & navigation;
        uint64_t input_at = timer_ms_gettime64();
        if(held != held_navigation) { held_navigation = held; repeat_at = input_at + 400; }
        else if(held && input_at >= repeat_at) { pressed |= held; repeat_at = input_at + 140; }
        /* Preserve Stop/cancel priority even if B was held before an A edge. */
        if(pressed && (buttons & CONT_B)) pressed |= CONT_B;
        bool games_ui_changed=false;
        publish_music();
        mutex_lock(&lock);
        if(splash_active && input_at>=splash_deadline) {splash_active=false;last_draw=0;}
        if(seen_settings_generation != settings_generation) {
            kui_shell_set_preferences(&shell, &settings_current);
            seen_settings_generation = settings_generation;
        }
        if(seen_destination_generation != destination_generation) {
            if(destination_result == 1) kui_shell_set_destination(&shell, destination_current);
            else if(destination_result == 2) kui_shell_set_listing(&shell, &destination_listing);
            else kui_shell_destination_error(&shell, destination_note);
            seen_destination_generation = destination_generation;
        }
        if(seen_system_generation!=system_generation) {
            if(system_ok) {
                kui_shell_set_system_preferences(&shell,&system_current);
                kui_menu_sound_config(system_current.menu_sounds,system_current.music_volume);
                if(applied_video!=system_current.video_mode) apply_video(system_current.video_mode);
            } else if(video_awaiting_save) {
                safe_video_boot=video_prior_safe;apply_video(video_prior_mode);
            }
            video_awaiting_save=false;
            seen_system_generation=system_generation;
        }
        if(seen_vmu_generation!=vmu_generation) {
            kui_shell_set_vmu(&shell,&vmu_snapshot);seen_vmu_generation=vmu_generation;
        }
        if(seen_music_listing!=music_listing_generation) {
            kui_shell_set_music_listing(&shell,&music_listing);
            seen_music_listing=music_listing_generation;
        }
        if(seen_games_listing!=games_listing_generation) {
            (void)kui_shell_set_games_rows(&shell,&games_listing,games_result_epoch,
                games_result_offset,games_result_view);
            seen_games_listing=games_listing_generation;
            games_ui_changed=true;
        }
        if(games_art_result_ready) {
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

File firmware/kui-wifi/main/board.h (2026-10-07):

/* SPDX-License-Identifier: MIT */
/* Seeed XIAO pins for the SCI connector (docs/sci-connector.md). The same
 * XIAO pins on both boards; the GPIO numbers behind them differ. Strapping
 * pins are avoided: the console's pull-ups must not change how it starts. */
#ifndef KUI_WIFI_BOARD_H
#define KUI_WIFI_BOARD_H
#include "sdkconfig.h"

#if CONFIG_IDF_TARGET_ESP32C5
#define BOARD_CHIP 5
#define BOARD_NAME "XIAO ESP32-C5"
#define PIN_SCLK 8   /* D8 */
#define PIN_MISO 9   /* D9 */
#define PIN_MOSI 10  /* D10 */
#define PIN_CS 1     /* D0 */
#define PIN_READY 0  /* D1 */
#define PIN_RESET 23 /* D4 */
#elif CONFIG_IDF_TARGET_ESP32C6
#define BOARD_CHIP 6
#define BOARD_NAME "XIAO ESP32-C6"
#define PIN_SCLK 19  /* D8 */
#define PIN_MISO 20  /* D9 */
#define PIN_MOSI 18  /* D10 */
#define PIN_CS 0     /* D0 */
#define PIN_READY 1  /* D1 */
#define PIN_RESET 22 /* D4 */
/* The C6 board switches between its own ceramic antenna and the U.FL
 * connector: GPIO3 low powers the switch, GPIO14 high picks U.FL. */
#define PIN_RF_SWITCH_POWER 3
#define PIN_RF_ANTENNA 14
#else
#error "K-UI Wi-Fi firmware supports the XIAO ESP32-C5 and ESP32-C6"
#endif
#endif

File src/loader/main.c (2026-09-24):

/* SPDX-License-Identifier: GPL-3.0-only */
#include "display.h"
#include "sd_reader.h"
#include "kui/loader_layout.h"
#include "kui/loader_probe.h"
#include <stddef.h>
#include <stdint.h>
#include <string.h>

extern const uint8_t __client_image_start[] __asm__("__client_image_start");
extern const uint8_t __client_image_end[] __asm__("__client_image_end");
extern uint8_t __bss_end[] __asm__("__bss_end");
static struct kui_loader_probe_service service;
static struct kui_loader_probe_manifest manifest;
static struct kui_loader_sd card;
static enum kui_loader_sd_result last_sd_result;

static int read_block(void *context, uint32_t lba, uint8_t output[512]) {
    last_sd_result = kui_loader_sd_read(context, lba, 1, output);
    return last_sd_result == KUI_LOADER_SD_OK ? 0 : -1;
}
static enum kui_loader_probe_result submit(
    const struct kui_loader_probe_request *request, void *output,
    uint32_t capacity, uint32_t *token) {
    return kui_loader_probe_submit(&service, request, output, capacity, token);
}
static enum kui_loader_probe_result poll(uint32_t token, uint32_t *bytes) {
    return kui_loader_probe_poll(&service, token, bytes);
}
static enum kui_loader_probe_result cancel(uint32_t token) {
    return kui_loader_probe_cancel(&service, token);
}
static uint32_t read_count(void) { return service.blocks_read; }
static const struct kui_loader_probe_api api = {
    KUI_LOADER_PROBE_VERSION, sizeof(struct kui_loader_probe_api),
    submit, poll, cancel, kui_loader_display_result, read_count
};

static void erase_range(uintptr_t start, uintptr_t end) {
    volatile uint32_t *p = (volatile uint32_t *)start;
    while((uintptr_t)p < end) *p++ = 0;
}
static void erase_retired_runtime(void) {
    /* Erase every main-RAM byte other than the BIOS area, our new resident
     * image/BSS, and our current 64 KiB stack reservation. Even old shell heap
     * allocations or a trampoline near the top of RAM cannot be read later.
     * The first 64 KiB are firmware-owned and are not used by the service. */
    erase_range(KUI_LOADER_CLIENT_ADDRESS, KUI_LOADER_RESIDENT_ADDRESS);
    erase_range((uintptr_t)__bss_end, KUI_LOADER_RESIDENT_MEMORY_END);
    erase_range(KUI_LOADER_RESIDENT_STACK, 0x8d000000u);
}

void kui_loader_resident_main(const uint8_t wire[KUI_LOADER_MANIFEST_BYTES]) {
    kui_loader_display_init();
    kui_loader_display_line("Resident entered; launcher has shut down.");
    enum kui_loader_probe_result result = kui_loader_probe_manifest_decode(wire, &manifest);
    if(result != KUI_LP_OK) {
        kui_loader_display_result("Launch extent manifest", 0, (uint32_t)result);
        kui_loader_display_summary(1, 0);
        return;
    }
    size_t client_bytes = (size_t)(__client_image_end - __client_image_start);
    if(!client_bytes || client_bytes > KUI_LOADER_CLIENT_MAX_BYTES) {
        kui_loader_display_result("Independent client bounds", 0, (uint32_t)client_bytes);
        kui_loader_display_summary(1, 0);
        return;
    }

    erase_retired_runtime();
    memcpy((void *)(uintptr_t)KUI_LOADER_CLIENT_ADDRESS, __client_image_start, client_bytes);
    /* Cache-off code/data remain coherent; no retired KOS cache helper is
     * invoked. The client entry itself clears only its own BSS. */
    kui_loader_display_line("Old launcher RAM erased; own client installed.");
    kui_loader_display_line("Initializing independent read-only SD backend...");
    last_sd_result = kui_loader_sd_init(&card);
    if(last_sd_result != KUI_LOADER_SD_OK) {
        kui_loader_display_result("SD initialization", 0, (uint32_t)last_sd_result);
        kui_loader_display_line(kui_loader_sd_result_name(last_sd_result));
        kui_loader_display_number("Last command: ", card.last_command);
        kui_loader_display_number("Last response: ", card.last_response);
        kui_loader_display_summary(1, 0);
        return;
    }
    /* The manifest's bound is the mapped partition end; the physical card may
     * contain additional partitions or unused sectors beyond that bound. */
    if(card.blocks < manifest.card_sectors) {
        kui_loader_display_result("Mapped volume fits card capacity", 0, 0);
        kui_loader_sd_shutdown(&card);
        kui_loader_display_summary(1, 0);
        return;
    }
    result = kui_loader_probe_init(&service, &manifest, read_block, &card);
    if(result != KUI_LP_OK) {
        kui_loader_display_result("Resident service initialization", 0, (uint32_t)result);
        kui_loader_sd_shutdown(&card);
        kui_loader_display_summary(1, 0);
        return;
    }

    uint32_t (*client_entry)(const struct kui_loader_probe_api *) =
        (uint32_t (*)(const struct kui_loader_probe_api *))(uintptr_t)KUI_LOADER_CLIENT_ADDRESS;
    uint32_t failures = client_entry(&api);
    if(!service.blocks_read) {
        kui_loader_display_result("Actual post-handoff SD reads", 0, 0);
        failures++;
    }
    if(last_sd_result != KUI_LOADER_SD_OK) {
        kui_loader_display_line(kui_loader_sd_result_name(last_sd_result));
        kui_loader_display_number("Last command: ", card.last_command);
        kui_loader_display_number("Last response: ", card.last_response);
    }
    kui_loader_sd_shutdown(&card);
    kui_loader_display_summary(failures, service.blocks_read);
}

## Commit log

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2026-09-17 Measure capture, hashing and storage wall time by phase
    Record non-overlapping timing buckets for raw reads, EDC, track I/O,
    SHA-256, CRC32 and checkpoints. Separate capture from setup, resume,
    verification and finalization; report on Stop, failure or completion.
    Keep paired reads, validation and saved formats unchanged. Add deterministic
    accounting checks and extend FAT32/exFAT capture tests to check phase/byte
    accounting alongside existing fault injection and resume equality.
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2026-09-20 v4.2: experimental code opt-in, CI error digest
    [t6a-dma-probe.cfg]
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2026-09-23 Add M1.5 launcher, persistent preferences and clear ripper results
    Keep the hardware-accepted capture engine unchanged. Add controller navigation,
    versioned alternating settings records and explicit saved-file verification
    status. Use the verified CRC32/no-readback defaults and preserve explicit
    bench.cfg overrides. Block capture on configuration I/O failure. Cover UI,
    settings fault recovery and adapter outcomes in host tests; document the short
    one-disc UI acceptance check and independently authored prior-work candidates.
    [main.c]
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2026-09-23 Fix inserted-disc detection and restore startup, music controls and disc launch
    [main.c]
2026-09-23 Apply music volume immediately when preference saving fails
    [main.c]
2026-09-23 Fix SH-4 format checks for music title and sample rate
    [main.c]
2026-09-23 Keep music playing across apps, shorten startup and expose DMA fallback
    [main.c]
2026-09-23 Add verified VMU restore, saved-track scans and RTC settings; bound music replacement
    [main.c]
2026-09-23 Fix Dreamcast compiler checks and validate short Ogg seek headers
    [main.c]
2026-09-24 Record app acceptance, expand logs and fix scan references and CD controls
    [main.c]
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2026-09-24 Fix DOA2 bootstrap 2 setup, enable loader caches and retain return diagnostics
    Compare the requested DreamShell source: install the independent reader before bootstrap 2 and explicitly prime retail CPU state. Preserve the original game entry and keep failures visible. Reuse the preparation track handle to avoid per-sector allocation-chain walks.
    Focused validation: five FAT32/exFAT reader lifecycle cases passed; frozen optical sources unchanged. Broad repeat suite skipped as requested.
    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
2026-09-24 Add read-only startup extraction helper for DOA2 exit analysis [skip ci]
    Record unchanged menu-return caller and zero counts across all GD routes. Request the exact owner executable to trace startup instead of producing another speculative console build. One synthetic extraction fixture matched exact IP/boot bytes and unchanged source hashes.
2026-09-24 Reduce CPU overhead in synchronous retail SD reads
    Use a receive-only SPI loop, algebraic checked CRC16, and aligned integer memcpy for the independent retail loader. Keep compression, scheduling, DMA behavior, and accepted probes unchanged.
    Focused validation: ASAN_OPTIONS=detect_leaks=0 make test-retail-fast-io passed (pin edges/work budgets, CRC/protocol failures, memcpy alignment/tails/canaries). Native layout, stack and instruction audit run in the console build.
    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
2026-09-24 Reduce retail read blocking and reuse cached SD blocks
    Record the improved DOA2 hardware baseline. Limit EXEC reads to two sectors while retaining eight-sector preflight checks, persist the existing one-block cache, and defer destination cache purges to the actual copy. Bind the already validated manifest after resident BSS initialization to recover code space without moving the guard.
    Focused validation: retail GD and image tests passed under ASan/UBSan, including progress/cancel/failure, validation-only mapping and identical 147-block reads for 32 sectors across 1/2/8-sector splits. Hardware must compare speech, FMVs and loading against 3ebbf8f9846b; no compression or asynchronous DMA.
    V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
2026-09-24 Pin playable DOA2 SD baseline and owner timings [skip ci]
    Preserve packaged build 6c02bd8b22f4 at baseline/doa2-sd-6c02bd8b22f4 and archive its exact SD ZIP. Record fluid audio, remaining load/texture delays, precise reported intervals, and constraints for measured CMD18 work. Documentation only; no new console build or repeated tests.
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2026-09-24 Integrate bounded CMD18 streams after passed console comparison
    Keep two-sector game EXEC chunks and the pinned baseline. Consume contiguous 8-10 block streams through the existing cache, close at request and extent boundaries, and preserve CRC and error cleanup. Adopt validated stage state with resident-local callbacks to remove duplicate cold initialization.
    Focused protocol, SD ownership/adoption/run selection and image boundary checks passed with ASan/UBSan. Actual gameplay performance awaits owner comparison.
    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
2026-09-25 Match the splash test to the Dainsleif background
    RC1 replaced the splash artwork, whose #030913 frame is RGB565 0x0042, but
    the host test still expected the previous background. make test therefore
    stopped at test-splash, before the remaining host and Python suites. The RC
    and release commits used scoped validation that skips the host suite, so CI
    did not run it.
    Claude-Session: https://claude.ai/code/session_01Gp9EYc2r9fMpZ7V8WtfonZ
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2026-09-25 Add Harbor Lights to the menu music rotation
    Harbor Lights, the original one-minute piece first shipped as the 1.5 update's
    larger-file sample, is now the sixth bundled song: a 197,444-byte Ogg encoded
    from its reproducible WAV (2,646,044 bytes, too large for a bundled WAV) and
    recorded in the music manifest with its own generator. All six cached songs
    hold 1,111,209 bytes including the shared decoder arena.
    Harbor Lights has no 1.5 WAV fallback, so the player now records bundled songs
    whose files a card lacks. L/R skip them, and a startup pick that turns out to
    be missing moves on to the next song instead of leaving the menu silent.
    Choosing the song by path or Clear cache looks again. Hos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
    [main.c]
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2026-09-26 Add Games box art, disc titles and three views
    Games > Advanced > Scan box art visits every game below /Games and records
    its disc title and cover in KUI/covers: the owner's PNG/JPEG when present,
    else the disc's own 0GDTEX.PVR, else the title alone. Unchanged games are
    skipped from size/date stamps; records are replaced only once complete.
    Y cycles List (large cover beside the names), Compact (two columns of four)
    and Gallery (four by two); the view is saved in KUI/apps/games/view.txt.
    Image details show the large cover. Game files are only read.
    The PVR decoder is an independent implementation from KallistiOS's texture
    tool at the pinned commit; stb_image 2.30 (MIT, same stb pin as stb_v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
    [main.c]
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2026-09-29 Add the CF board: CompactFlash on the G1 ATA bus
    A rev 1 design for a small board that puts a CompactFlash card inside the
    console, as the slave beside the GD-ROM drive on its connector (CN503 on
    the owner's VA1 mainboard). The card runs in True IDE mode from 3.3 V,
    with a solder jumper for 5 V.
    hardware/cf-board holds the KiCad 7 project (schematic and routed board),
    Gerbers, a parts list, part positions, a 1:1 fit template, and a wiring
    guide with a connector orientation check. tools/design.py is the single
    source of the pinouts and connections; tools/build.sh regenerates
    everything from it. Both netlist checks (schematic and board) find 36
    nets, 102 connections and no problems, and KiCad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
    [cf-board-bom.csv, cf-board-positions.csv, cf-board.kicad_pcb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]
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2026-10-01 Storage: boot and launch from standalone SCIF, SCI or IDE/CF
    Carry a fixed storage selection through bootstrap, runtime and native game handoff. Add bounded SCI SD and G1 ATA/CF transports, retain exFAT, and serialize IDE writes with GD-ROM DMA. SCI networking remains exclusive. Include focused protocol tests and one-card installation notes.
    SCI and IDE/CF require console validation; this is a development build.
    [main.c]
2026-10-01 Keep only the selected storage reader resident during games
    Build and audit separate SCIF, SCI and IDE readers within the existing
    low-memory and stack reservation. Preserve full stage validation while
    removing duplicate resident initialization checks and transport dispatch.
    Also tighten boot marker matching and transfer buffer bounds, and document
    the one-card SCI benchmark configuration.
    Focused manifest, storage, GD initialization and package checks passed.
    [t13-sci-storage.cfg]
2026-10-01 Bootstrap: add graphical menu, card retry and updateable tools
    Reuse Dainsleif artwork and the launcher font for TV-safe startup and recovery controls. Keep normal autoboot, allow source selection and repeated card attempts, and serialize loading with diagnostics. Add fixed tools.kui loading through the existing validated read-only image contract. Document the controls and future card-only recovery path.
    [main.c]
2026-10-01 Bootstrap: avoid unchanged redraws and measure loading from card
    Keep the displayed boot frame while its content is unchanged, avoiding repeated artwork copies and vblank waits during runtime reads. Add an exclusively owned read-only load measurement with initialization, load/check throughput and drawing time. Package the exact bootstrap as tools.kui so the existing graphical CD can test this correction without another burn.
    [main.c]
2026-10-01 Bootstrap: crimson artwork and optional card-updatable boot menu
    Keep version 1.5.1. Add a validated CD-origin boot.kui override with normal/recovery fallback, manual bypass and card-origin loop prevention. Link red artwork only in the bootstrap and draw its dimmed backdrop without VRAM reads. Keep tools.kui built from the same CD ELF and avoid installing an override by default.
    Focused verification: boot UI and splash bounds/pixel checks, asset provenance/audio check, and 45 real-image boot recovery scenarios passed with ASan/UBSan (local leak detection disabled for ptrace environment). Independent boot ownership and packaging reviews found no blocker. Native build and existing CI gate sti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
    [main.c]
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2026-10-01 Record accepted SCIF 15-minute soak baseline [skip ci]
    [scif-soak-baseline-2026-10-01-result.csv]
2026-10-01 docs: record SCI soak and initial performance findings [skip ci]
    [sci-soak-baseline-2026-10-01-result.csv]
2026-10-01 SCI: add original bounded sector DMA and report actual use
    Replace per-byte payload callbacks with an optional bounded block operation.
    Implement original SH7750 channel-1 receive/transmit DMA with cache handling,
    strict ownership checks, bounded completion, fault cleanup and PIO fallback.
    Keep command framing, CRC checks and stop/status handling intact. Preserve
    per-run DMA/fallback counts in Diagnostics results for the first console check.
    Fit the read-only SCI resident within the existing memory reservation by
    borrowing manifest track objects and using SCI-only LTO/call relaxation.
    Audit every final LTO stack frame and distinguish validated ELF file metadata
    from callable symbols without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
    [main.c]
2026-10-01 SCI: combine receive processing and overlap transmit CRC
    The first DMA soak verified 416 MiB without errors, improving reads 75.15%
    over polled SCI and 51.25% over SCIF. DOA2 is substantially better but retains
    some lag. Preserve the original reports and this hardware comparison.
    Return CRC from bulk payload transfers. After receive DMA completes, reverse
    bits and calculate CRC in one pass using the caller's original cache alias.
    Calculate transmit CRC while DMA sends the separate reversed staging buffer.
    Compiler barriers preserve DMA/CPU ordering; publish CRC only on success.
    Keep framing, integrity checks, bounded cleanup and game pacing unchanged.
    Host tests cover all lengths and byte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
    [sci-dma-soak-2026-10-01-result.csv]
2026-10-01 SCI: streamline receive clock feeding and measure DMA phases
    Record a6cb218 Quick: 4 MiB verified, zero errors, writes 1104.35 KiB/s
    and reads 1052.72 KiB/s. Preserve the uploaded JSON/CSV and distinguish
    this short check from the accepted 15-minute soak.
    Seed the receive dummy byte once and use bounded inline TDRE polling,
    removing 511 redundant TDR writes per sector. Keep exact byte counts,
    CRC, channel ownership, final-edge guards and failure cleanup unchanged.
    Enable runtime phase timing only during Storage tests. Export successful
    sample counts and setup/transfer/check totals in additive JSON fields;
    retain binary History/CSV compatibility and original failure messages.
    Exclude all pr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
    [sci-dma-cached-quick-2026-10-01-result.csv]
2026-10-01 SCI: reverse sector words and record measured DMA phases
    Use table-free byte-preserving word reversal in RX and aligned TX staging,
    retaining per-block CRC and bounded transfer cleanup. Preserve unaligned TX
    support and keep the first dummy seed inside the bounded clock-feed loop.
    Record the owner's passing Quick and five-minute soak with phase analysis.
    Native normal and benchmark audits pass the existing memory/stack guards;
    console speed acceptance remains pending.
    [sci-dma-profile-2026-10-01-quick-result.csv, sci-dma-profile-2026-10-01-soak-result.csv]
2026-10-01 SCI: check reversed words directly and extend return counters
    Run 8 verifies 160 MiB with zero errors, but read checking still costs
    78 microseconds per sector. Feed each reversed word's four logical bytes
    directly into CRC, removing per-byte boundary tests and byte reloads.
    Keep CRC publication and DMA ownership/fault handling unchanged.
    Add independent CRC/data coverage for every byte value in each word lane.
    Extend BIOS return counters to 900 frames with a per-frame polling bound,
    so the owner can capture game batching after the 29-second DOA2 load.
    Focused ASan/UBSan and native normal/benchmark audits pass existing guards.
    Actual console speed and counter capture remain pending.
    [sci-dma-word-soak-2026-10-01-result.csv]
2026-10-01 Allow measured short game-read batches on moving framebuffers
    Use a half-frame estimate and four-sector cap while retaining the two-sector fallback and existing still-screen pacing. Add boundary and timing-model coverage, record the latest SCI results and DOA2 counters, and document the separate Windows CE boot-layout blockers.
    [sci-grouped-crc-and-game-pacing-2026-10-01-quick-result.csv, sci-grouped-crc-and-game-pacing-2026-10-01-soak-result.csv]
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2026-10-02 fix(diagnostics): check SCI control bits instead of the receive pin
    SCSPTR bit 0 reads RxD, not the TxD latch. Accept both input levels while
    checking EIO/direction controls, and refuse preexisting GPIO output owners.
    Model independent pin levels to catch the original false rejection.
    Retain probe phase, DMA-start/count/IRQ and register evidence on the failure
    screen, alongside the separate card-recovery cause. Record the first console
    failure without inferring that autonomous reception is unsupported.
    Validation: strict ASan/UBSan probe and recovery regressions, shell checks,
    JSON formatting and failure renders; full CI and console retest pending.
    [main.c]
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2026-10-02 fix(diagnostics): verify SCI receive handoff before repeated reads
    Record 17 verified autonomous console transfers and distinguish framing bus faults from card responses. Bound receiver cleanup and restore full-duplex SCI only while deselected; retain CRC, ownership and DMA quarantine.
    Add a host-only checked CE load planner and record review of the supplied polling proposal, including the resident BL/virtual-stack prerequisite. CE launching remains unchanged.
    [main.c]
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2026-10-02 fix(diagnostics): preserve SCI framing fault before peripheral shutdown
    The console verified 16 slow reads and one fast read, then latched a normal-bus fault before the next command. Capture the first failed wait's original status and controls before SCR=0 changes them, preserve the snapshot through recovery, and report the exact framing step and byte index.
    Keep transfer and reset behavior unchanged. Compile telemetry out of native residents; retain CRC, DMA ownership and quarantine checks. Add targeted fault-capture regressions and record the console evidence.
    [main.c]
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2026-10-02 fix(diagnostics): reset SCI module after verified trailing overrun
    The first-fault report isolates an RDRF timeout before the next card command.
    Test a bounded SCI-only module-standby reset after validated completion,
    retain first-fault evidence, and prevent SCI access if resume is unconfirmed.
    CRC, data, guards and ownership gates remain; ordinary game reads and CE
    launch are unchanged. Host fault-injection and independent review pass;
    console validation remains required.
    [main.c]
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2026-10-02 SCI async: retry proven-idle overruns; add screen-on stress and speed test
    The passing quiet stress (71,641 reads) and the earlier read-560 failure
    show the remaining risk: SCI holds one received byte, so any bus stall
    longer than about 0.64 us at 12.5 MHz overruns the block, and games keep
    the bus busy. A lone mid-payload overrun now becomes a retry instead of a
    storage lockout when the stopped channel is provably idle (count and
    address agree and hold across four checks, each after an uncached read;
    at most two late transfers tolerated). The request reuses the handoff
    (deselect, MSTP0 reset, re-init), clocks out the rest of the block and
    re-issues the same CMD17, up to three times. Every o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
    [main.c]
2026-10-02 SCI async: leaner single-block reader; CMD18 gap and resume measurements
    Reader:
    - Ready/token/token-end waits check their 100 ms limit every 32 bytes
    instead of reading the wall clock on every framing byte.
    - Finish reverses and CRC-checks each block by table lookup.
    - Re-initialization waits one bit time at the fast rate (64 loops, not 1,024).
    - Masked windows are timed from after irq_disable(), so a preemption before
    the mask is no longer counted as masked time.
    - Stages report token_us/max_token_us: the card wait in microseconds.
    Speed test (R) adds two read-only CMD18 measurements, always ended by CMD12:
    - a 16 KiB continuous receive-only capture, parsed for every block's CRC and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
    [main.c]
2026-10-02 SCI async: show the CMD18 stage's details when a measurement fails R
    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
    [main.c]
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2026-10-02 SCI async: check streamed blocks while the next one is received
    The 3aa4554c44d9 run streamed 2,048 blocks with matching data at 1,059 KiB/s,
    about the ordinary reader's 1,095: per block 343 us receiving, then 69 us of
    checking and 62 us of next-block framing in series.
    begin_stream(lba, count, dst) now reads a whole run and poll drives it.
    Blocks alternate between two receive areas: when a block completes, the
    same poll resets the SCI, reselects, finds the next token and starts the next
    DMA, then checks the completed block (CRC16 with its RDR byte) into dst while
    the next one is on the wire. A block failing its check is read again: the
    in-flight block is dropped when it arrives, then CMD12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
    [main.c]
2026-10-02 SCI async: find what holds the CPU for 2.5 ms
    About once per R run the CPU stalls for 2.5 ms, once inside an SCI module
    reset with interrupts masked. R now records where and why:
    - Pause log: interrupt-masked windows of 0.5 ms or more, calls of 1.5 ms or
    more and long gaps between polls, with site, stage and uptime.
    - The slowest module reset's six steps on raw TMU2 reads, and its length in
    CPU cycles from KOS's PRFC0 counter.
    - A 1 s reset loop after the streaming pass: back-to-back handoffs with
    module resets, card deselected, no DMA; counted apart from the reads.
    - Three 1 s idle CPU tests after closing: masked, masked with an uncached
    RAM read per loop, and unmasked.
    The report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
    [main.c]
2026-10-02 SCI async: time the probe with TMU2 ticks at their real length
    The ad0340e18528 console run shows the "2.5 ms pause" was never a stall:
    every logged pause fell exactly on a whole second of uptime, while 73,273
    back-to-back module resets (longest 9 us) and 3 s of idle CPU tests timed
    with raw counters (longest masked gap 1.4 us) saw nothing. KOS's
    timer_us_gettime64() counts TMU2's 80.2 ns ticks (Pck/4, 12,468,720 Hz) as
    80 ns, so each second reads 997,498 us and then jumps 2.5 ms.
    The probe now times with __dreamcast_get_ticks() scaled by the TCOR2 period,
    so its pause log, masked windows and per-phase times are uniform. The reset
    loop, idle CPU tests and CPU-cycle cross-check are removed;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
    [main.c]
2026-10-03 SCI async: record the final reader run; report resident sizes in CI
    The 9e6ccca3dd9e console run shows no pauses with the uniform clock: longest
    call 371 us, longest masked window 61 us, which was the reader's one-time
    lookup-table build at open. Build the tables before masking. R's stream line
    is shortened to fit the screen and the masked-window line omits an empty
    stage.
    Diagnostic CI adds an annotation with each low resident's code, BSS, free
    bytes, conservative stack sum and (SCI) largest symbols, read from the linked
    ELF by tools/report_retail_sizes.py, so the size budget is visible without the
    job log. The step cannot fail the build.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
    [main.c]
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2026-10-06 Fix Games paging and original/2048 folder matching
    Reuse a bounded worker-owned directory snapshot across pages and views, resolve ordinary folders lazily, and preserve visible names when pairing. Retry transient discovery failures without hiding copies. Poll idle Games controls independently of redraws; retain busy caps and SCI video handoff.
    Validation: 152 FAT32/exFAT Games checks, full shell and UI-rate checks, 8 cover checks, 24 retail packaging checks and 9 workflow checks passed. Independent runtime/backend reviews passed. The standard Armada CE black screen remains unresolved; no resident reader or transport algorithm changed.
    Validation: games-variants
    [main.c]
2026-10-06 Cache Games in RAM, correct GD command handling and add ripper exports
    Publish rows before selected artwork, retain bounded catalogues and warm /Games in the idle worker. Correct mode transfer accounting, invalid CHECK handles and terminal command occupancy.
    Add resumable BIN/CUE, CSO, DreamShell-LZO ZSO and CHDv4 output choices. Preserve raw captures, verify decoded exports and retain read-only Verify behavior. Independently validate track geometry and legacy CHD audio import.
    Portable sanitizer suite, relevant FAT32/exFAT suites, independent codec/MAME/libchdr checks and six native resident layout/stack guards pass locally. Physical title compatibility and menu timing require console tes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
    [main.c]
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2026-10-06 Restore working launch preparation and stop idle optical media
    Withdraw the checksum-batching test after its native INVALID RETAIL MAP regression. Restore the exact prelaunch source from the console-tested 606f build while retaining the GD command fixes, formats and RAM catalogue. The precise native corruption mechanism remains unproved.
    Draw the first boot/runtime screen, then submit bounded STOP before worker creation. Idle title detection remains parked until an observed removal/insertion; explicit disc applications can wake the motor. Preserve optical ownership, DMA/poison guards and startup input timing.
    Validation: 56 FAT32/exFAT launch-preparation scenarios with independent CRCs, re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
    [main.c]
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
